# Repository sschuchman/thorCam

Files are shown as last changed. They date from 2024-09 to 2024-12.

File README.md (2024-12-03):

# Thoracic Camera

## Overview
The **Thoracic Camera** project is a collaborative effort to design a dynamic thoracic camera system capable of precision actuation and real-time feedback for use in minimally invasive surgeries. By combining a Raspberry Pi 5 for advanced processing and a Raspberry Pi Pico for motor control and sensor feedback, the system delivers a robust solution for camera tracking and actuation in the chest cavity.

---

## Contributors
- **Sean Schuchman**: January 2024 - December 2024  
- **Jakob Schoeberle**: August 2024 - December 2024  
- **Colton Wall**: August 2024 - December 2024  

---

## Hardware

### Raspberry Pi 5
- **Role**: Central processing hub for the system.  
- **Responsibilities**:
  - Handles video feed from the Pi Camera Module V3.
  - Performs computer vision tasks to detect and track a target object.
  - Sends actuation commands to the Pico Controller via UART.

### Pico Controller (Raspberry Pi Pico)
- **Role**: Camera actuation controller.  
- **Responsibilities**:
  - Interprets movement commands from the Raspberry Pi 5 and drives stepper motors.
  - Monitors sensor feedback from tension modules to ensure proper wire tension.
  - Handles precise actuation of the thoracic camera in response to commands.

---

## Pico Controller
The **Pico Controller** acts as an abstraction layer between the computer vision system on the Raspberry Pi 5 and the physical camera actuation system. It simplifies control by encapsulating motor and tension management, providing an easy-to-interface control system.  

### Features:
- **Camera Actuation**:  
  Controls stepper motors to manipulate tension wires, enabling the camera to move along the x-plane and y-plane directions.  
- **Tension Monitoring**:  
  Uses sensor feedback from load cells to dynamically adjust wires and maintain system balance.  
- **Control Modes**:  
  - **Manual Mode**: Direct input to move the camera.  
  - **Automatic Mode**: Actuation based on computer vision commands from the Raspberry Pi 5.  

---

## Directory Structure
The project is divided into several directories to organize hardware, software, and firmware resources.

- `/Software`: Contains software running on the Raspberry Pi 5, including computer vision and the Flask web application for control.  
- `/Firmware`: Firmware for the Raspberry Pi Pico to manage motor control and tension monitoring.  
- `/Hardware`: Schematic diagrams, PCB designs, and other hardware resources.  
- `/Datasheets`: Documentation for components such as stepper motors, motor drivers, and sensors.  
- `/3D_Models`: 3D printable designs for physical components.  
- `/legacy`: Archive of previous iterations or deprecated designs.

---

## Setup

### Raspberry Pi Pico Setup
1. **Development Environment**:
   - Use Visual Studio Code with the Raspberry Pi Pico extension to build and flash the firmware.
   - Ensure the Raspberry Pi Pico Debug Probe is connected for flashing and debugging.  

2. **Firmware Installation**:
   - Clone the repository and navigate to the `/Firmware` directory.
   - Open the project in Visual Studio Code and use the Pico extension to compile and flash the firmware.  

3. **Hardware Connections**:
   - Connect stepper motors via L293D drivers to the GPIO pins.
   - Connect ADS1115 ADC modules to GPIO4 (SDA) and GPIO5 (SCL).
   - Ensure UART pins (GPIO0 and GPIO1) are connected to the Raspberry Pi 5 for communication.

### Raspberry Pi 5 Setup
1. **Install Required Software**:
   - Ensure Python is installed with the required libraries (`Flask`, `OpenCV`, etc.).
   - Navigate to the `/Software` directory and install dependencies using:
     ```bash
     pip install -r requirements.txt
     ```

2. **Start the Web Application**:
   - Run the `app.py` script to start the Flask web server:
     ```bash
     python app.py
     ```
   - Access the control interface via a web browser on the local network.

3. **Hardware Connections**:
   - Connect the Pi Camera Module V3 to the CSI port.
   - Ensure UART is configured on `/dev/ttyAMA0` for communication with the Pico Controller.

---

## Usage
1. **Manual Control**:
   - Use the web interface to manually send movement commands to the Pico Controller.
   - Adjust camera settings and monitor sensor feedback through the interface.

2. **Automatic Control**:
   - Enable automatic mode via the web interface to allow the system to track a selected object.
   - The Raspberry Pi 5 processes the video feed to calculate the offset and sends movement commands to the Pico Controller.

3. **Real-Time Feedback**:
   - Monitor sensor values and system logs in the web interface.
   - View live video and mask feeds to verify object tracking.

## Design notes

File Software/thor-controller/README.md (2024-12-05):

# Thor Controller Software

## Overview
The **Thor Controller Software** is a dual-component system designed to control and monitor the thoracic camera for minimally invasive surgery. The software runs on two devices:
1. **Raspberry Pi Pico**: Handles movement commands and sensor data.
2. **Raspberry Pi 5**: Serves as the control hub, hosting a web-based user interface and managing computer vision processing and UART communication with the Pico.

This system provides a seamless interface for real-time camera movement, video visualization, and automatic tracking of surgical tools.

---

## Features
### Raspberry Pi 5
- **Web Application**:
  - Built with Flask, serving as the main user interface.
  - Displays:
    - High-resolution live camera feed from the Pi Camera V3 Wide.
    - Mask feed showing object tracking and offset visualization.
    - Real-time sensor data in a bar chart.
    - Live UART log output from the Raspberry Pi Pico.
  - Supports toggling between **manual** and **automatic** control modes.
  - Interactive sliders to adjust brightness, tracking thresholds, and color detection parameters.
- **Computer Vision**:
  - Uses OpenCV to detect and track objects based on color.
  - Computes positional offsets `(dx, dy)` of the target relative to the center of the screen.
  - In automatic mode, calculates and sends movement commands to the Raspberry Pi Pico for continuous adjustments.
- **UART Communication**:
  - Sends movement commands (`Move[x, y]`) to the Raspberry Pi Pico.
  - Receives live sensor data and logs from the Pico for display.

### Raspberry Pi Pico
- Processes UART commands received from the Raspberry Pi 5.
- Adjusts camera position based on movement commands.
- Reads and processes tension sensor data using ADC inputs.
- Manages motor control via L293D motor drivers.

---

## Installation

### Prerequisites
#### Raspberry Pi 5
1. Ensure your Raspberry Pi 5 is running Raspberry Pi OS with Python 3 installed.
2. Enable the camera interface:
   ```bash
   sudo raspi-config
   ```
   Navigate to **Interface Options > Camera** and enable it.

3. Install required system dependencies:
   ```bash
   sudo apt update
   sudo apt install -y python3-opencv python3-picamera2 python3-numpy python3-flask python3-serial
   ```

4. Install additional required libraries:
   ```bash
   sudo apt install -y libcamera-apps libcamera-dev
   ```

5. Ensure the user has the appropriate permissions to use the camera:
   ```bash
   sudo usermod -a -G video $USER
   ```

6. Reboot the Raspberry Pi to apply changes:
   ```bash
   sudo reboot
   ```

#### Raspberry Pi Pico
1. Flash the custom firmware onto the Pico using the Pico SDK or any C development environment.
2. Ensure the Pico is connected to the Raspberry Pi 5 via UART for communication.

---

## Usage

### Raspberry Pi 5
1. Clone this repository to your Raspberry Pi 5:
   ```bash
   git clone <repository_url>
   cd <repository_directory>
   ```

2. Start the Flask server:
   ```bash
   python3 app.py
   ```

3. Open a web browser and navigate to:
   ```bash
   http://<Raspberry-Pi-IP>:5000
   ```
   Replace `<Raspberry-Pi-IP>` with your Raspberry Pi's IP address.

---

## Troubleshooting

### ModuleNotFoundError: No module named 'libcamera'
- Ensure `libcamera` is installed using:
  ```bash
  sudo apt install -y libcamera-apps libcamera-dev
  ```
- Verify the camera interface is enabled:
  ```bash
  sudo raspi-config
  ```
  Navigate to **Interface Options > Camera** and enable it.

### Permission Errors with Camera
- Add the user to the `video` group:
  ```bash
  sudo usermod -a -G video $USER
  ```
- Reboot the Raspberry Pi:
  ```bash
  sudo reboot
  ```

### Dependencies Not Installed
If you encounter dependency installation errors, ensure that you run:
```bash
sudo apt update
sudo apt install -y python3-opencv python3-picamera2 python3-numpy python3-flask python3-serial
```

---

## Notes
- For smoother operation, ensure the Raspberry Pi is connected to a stable network.
- Regularly check for updates to the dependencies using `sudo apt update && sudo apt upgrade`.

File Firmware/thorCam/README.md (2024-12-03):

# Thor Controller Firmware

## Overview
The **Thor Controller Firmware** is designed to run on the Raspberry Pi Pico, facilitating movement control and sensor monitoring for the thoracic camera system. The firmware communicates with the Raspberry Pi 5 over UART, processing movement commands and controlling stepper motors while continuously monitoring sensor data.

The firmware leverages a modular structure, with functionalities like motor control, sensor monitoring, and UART communication implemented in dedicated source and header files.

---

## Features
- **UART Communication**:
  - Receives movement commands (`Move[x, y]`) from the Raspberry Pi 5.
  - Sends real-time sensor data (`Load[0, 0, 0, 0]`) back to the Raspberry Pi 5.
- **Sensor Monitoring**:
  - Reads tension sensor values using ADS1115 ADCs connected over I2C.
  - Monitors sensor thresholds to maintain balance and ensure safe motor operation.
- **Motor Control**:
  - Controls four stepper motors via L293D motor drivers.
  - Supports precise movement in response to parsed UART commands.
- **Multicore Processing**:
  - Core 0 handles UART communication and movement control.
  - Core 1 continuously reads sensor values for real-time feedback.

---

## Installation

### Prerequisites
- **Development Environment**:
  - Install Visual Studio Code with the Raspberry Pi Pico extension.
  - Configure the extension to build and run Pico projects.
- **Debugging Tools**:
  - Use the Raspberry Pi Pico Debug Probe to flash firmware and debug.
- **Hardware Setup**:
  - Connect:
    - ADS1115 ADC modules to the I2C pins (SDA: GPIO4, SCL: GPIO5).
    - Stepper motors to L293D drivers and appropriate GPIO pins.
    - UART (GPIO0, GPIO1) for communication with the Raspberry Pi 5.

### Build and Flash
1. Clone the repository and open the `thorCam` folder in Visual Studio Code.
2. Build the firmware using the Pico extension's build tools.
3. Flash the firmware to the Raspberry Pi Pico using the Pico Debug Probe.

---

## Key Functionalities

### 1. **Main File**
- `main.c`: Initializes all components and starts the main execution loop.
  - Sets up UART, I2C, and GPIO configurations.
  - Spawns tasks for:
    - Reading sensors on Core 1.
    - Handling UART commands and movement control on Core 0.

### 2. **Functional Highlights**
- **Motor Control**:
  - `l293d.c` and `l293d.h` provide functions to initialize and control stepper motors.
  - Implements precise stepping logic for both forward and backward movement.
- **Sensor Monitoring**:
  - Interfaces with ADS1115 modules to read differential sensor values.
  - Calibrates sensors and monitors tension thresholds.
- **Movement**:
  - Maps movement commands to motor actions.
  - Ensures balanced tension during movement by coordinating multiple motors.
- **UART Communication**:
  - Parses incoming UART commands such as `Move[x, y]`.
  - Sends sensor data logs back to the Raspberry Pi 5.
- **ADC Handling**:
  - Provides an interface for configuring and reading from ADS1115 ADC modules.
  - Supports differential and single-ended readings.

---

## Usage
1. Flash the firmware to the Raspberry Pi Pico using the Debug Probe.
2. Connect the hardware as specified in the prerequisites.
3. Use the Flask web interface running on the Raspberry Pi 5 to send movement commands and monitor sensor feedback.

---

## Troubleshooting
- **No UART Communication**:
  - Verify the correct UART pins (GPIO0, GPIO1) are connected to the Raspberry Pi 5.
  - Check the baud rate matches between the devices (default: `115200`).
- **Motor Stalling or Overrun**:
  - Ensure motor driver connections are secure.
  - Verify tension limits in the sensor monitoring code and adjust as necessary.
- **Incorrect Sensor Readings**:
  - Confirm I2C connections (SDA: GPIO4, SCL: GPIO5).
  - Calibrate the ADS1115 modules using the `ads1115_calibrate()` function.

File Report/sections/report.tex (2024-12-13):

\section{Background}
Thoracic surgeries often face challenges of limited visibility due to the narrow space between the ribs. Traditional surgical methods frequently involve partial rib removal to provide surgeons with adequate access and visibility. This invasive approach leads to longer recovery times and increased post-surgery complications.

The \textbf{Thoracic Camera Project} aims to address these issues by introducing a highly maneuverable thoracic camera system capable of precise actuation and real-time feedback. This system is designed to operate within the chest cavity, providing continuous, clear visualization without the need for rib removal. By combining manual and automatic control, our solution enhances surgical precision, reduces the need for assistants, and promotes minimally invasive procedures.

\section{Technical Descriptions}

\subsection{System Overview}
\subsubsection{Block Diagram}

\paragraph{Level 0}
The Level 0 block diagram, shown in Figure~\ref{fig:level0}, outlines the four primary components of the thoracic camera system: the Camera, Video Processing, Tension Control, and the User Interface. The core functionality of the system revolves around the camera, which is mounted on an actuating platform. This slim and maneuverable camera is inserted into the chest cavity during surgery, providing a live video feed.

\begin{figure}[H]
    \centering
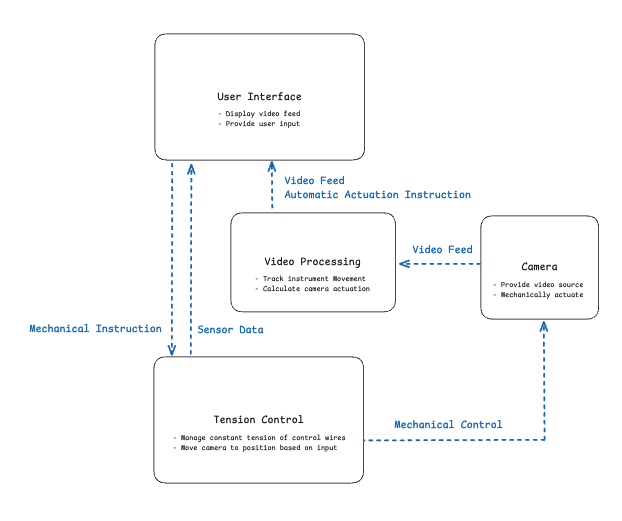
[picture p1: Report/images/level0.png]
    
    \caption{Level 0 Block Diagram of the Thoracic Camera System}
    \label{fig:level0}
\end{figure}

The video feed is processed in the Video Processing module, where frames are analyzed to detect surgical tools and calculate the necessary movements to center the object within the frame. These calculated movement commands are forwarded to the Tension Control system, which adjusts the tension in the wires to precisely move and stabilize the camera as needed.

The User Interface (UI) provides surgeons with full control over the system, offering options for both automatic and manual operation modes. Through the UI, users can view the live video feed, monitor system diagnostics, and adjust settings such as brightness or control modes. This integration ensures seamless interaction between the surgeon, the visualization system, and the tension control mechanisms.

\paragraph{Level 1}  
As shown in Figure~\ref{fig:level1}, the Level 1 block diagram details the operational units and their interconnections, emphasizing key components such as the \textbf{Raspberry Pi 5}, \textbf{Pi Pico}, \textbf{ADC Modules}, \textbf{Load Cells}, \textbf{Pi Camera V3 Wide}, \textbf{Stepper Motors}, and \textbf{Stepper Drivers}.

\begin{figure}[H]
    \centering
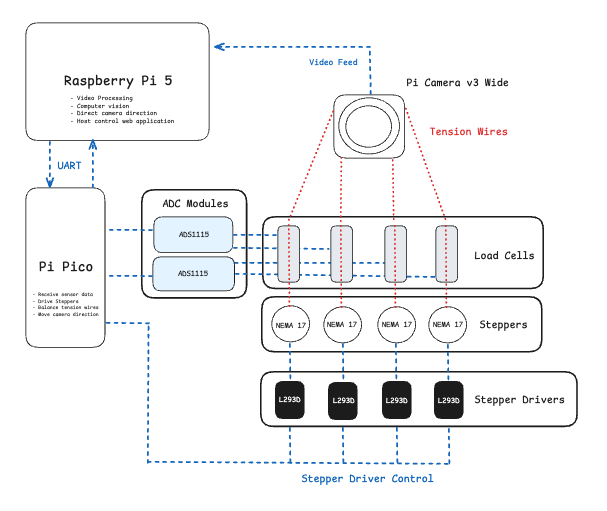
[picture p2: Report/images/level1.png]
    
    \caption{Level 1 Block Diagram of the Thoracic Camera System}
    \label{fig:level1}
\end{figure}

\begin{itemize}
    \item \textbf{Pi Camera V3 Wide:} The camera captures high-quality images with a broad field of view, suitable for minimally invasive surgical environments. Its compact design ensures it can navigate tight spaces while providing clear visualization of the surgical field.

    \item \textbf{Raspberry Pi 5:} Serving as the central processing unit, the Raspberry Pi 5 handles computer vision tasks, detecting and tracking objects in the camera feed. It calculates movement adjustments to keep targets aligned at the frame center and hosts the web-based User Interface for real-time video streaming, diagnostics, and control options.

    \item \textbf{Pi Pico:} The Raspberry Pi Pico manages mechanical actuation by controlling four \textbf{Stepper Motors} via \textbf{L293D Stepper Drivers}. It adjusts the tension in four wires attached to the camera mount to ensure smooth movement. The Pico also processes sensor data from the \textbf{ADC Modules} and dynamically balances wire tension to stabilize the camera.

    \item \textbf{ADC Modules:} Two ADS1115 ADC modules interface with the system's \textbf{Load Cells}, reading tension data to ensure precise control. These modules enable continuous monitoring of wire tension and provide feedback for real-time adjustments.

    \item \textbf{Load Cells:} Four load cells measure the tension in each wire, providing critical data to the Raspberry Pi Pico. This feedback allows the system to dynamically adjust wire tension and maintain stability during movement.

    \item \textbf{Stepper Motors:} Four NEMA 17 stepper motors provide the mechanical actuation required to adjust wire tension and position the camera. These motors are controlled by the Raspberry Pi Pico through the \textbf{Stepper Drivers}.

    \item \textbf{Stepper Drivers:} Four L293D drivers serve as the interface between the Raspberry Pi Pico and the stepper motors, enabling precise control over the camera's position and orientation through wire tension adjustments.
\end{itemize}

The integration of these components ensures smooth, responsive, and precise camera movements. The \textbf{Raspberry Pi 5} and \textbf{Pi Pico} communicate via a UART connection, allowing for continuous feedback and command transmission. This seamless interaction between hardware and software provides surgeons with a reliable, intuitive visualization tool for thoracic surgeries, adaptable for both manual and automatic modes.

\subsection{Physical Design}
\subsubsection{Tension Control Module}
The tension control module is responsible for accurately adjusting the position and orientation of the thoracic camera by controlling the tension in four wires connected to the camera. Each module is equipped with a NEMA 17 stepper motor, located at the bottom of the unit, which drives a spool to regulate the tension in the wire. This setup allows for precise control of the camera's movement, crucial for the dynamic visualization required in thoracic surgeries.

For tension monitoring, each module uses a 1kg load cell, which is centrally positioned in the module to measure the exact force applied to the wire. The load cell’s accuracy is key to ensuring balanced tension across all four wires, preventing any misalignment or jerking motions that could interfere with the camera’s positioning. The chosen load cell has an accuracy of ±0.01kg, providing a resolution fine enough to detect even the smallest changes in wire tension. This ensures the camera’s movements are smooth and responsive, which is critical during delicate surgical procedures. 

In terms of physical size, the tension control module, as shown in the attached schematic, is compact yet robust. The overall dimensions are approximately 12.7mm wide by 80mm tall, with a depth of 12.7mm. The wire feeds out from the top of the module through a guiding tube, ensuring that the wire moves smoothly as tension is adjusted. This small form factor makes the system suitable for tight surgical environments, where space is a premium, while still providing the necessary functionality to support the thoracic camera.

\includepdf[pages=-]{docs/Tension_Module_v3.pdf}

\subsection{Tension Module Rack}
The tension module rack is designed to hold and align the four tension control modules, ensuring they function precisely and consistently during operation. Each module is mounted within the rack, and the rack's dimensions and construction are carefully optimized for stability and ease of assembly. 

The overall length of the rack is 260mm, with a height of 74mm and a depth of 88mm. The modules are spaced 64mm apart, with a set screw positioned at the back of each module, securing them firmly in place. This design prevents any unwanted movement or vibrations, ensuring that the tensioning system remains stable, even under varying loads. The precision alignment of the modules is essential to achieving consistent wire tension and smooth actuation of the thoracic camera. 

Additionally, the rack allows for easy access to each module's stepper motor and load cell for maintenance or adjustment. The rack's design is modular, meaning it can accommodate different configurations or upgrades if needed. This flexibility is critical in surgical environments, where equipment must be adaptable and reliable. 

\includepdf[pages=-]{docs/Module_Rack.pdf}

\subsubsection{Camera Module}
\begin{itemize}
    \item Mounted on a gimbal plate actuated by four tension wires for precise directional control.
    \item Includes optimized internal tunnels to reduce friction and enhance movement responsiveness.
    \item Dimensions: 40mm wide, 60mm long, and slightly taller than 15.75mm.
\end{itemize}

The camera module consists of two key components: the platform and the gimbal plate. The platform secures the tension wires, each routed through dedicated tubes and locked into place using set screws. These tubes ensure that the tension wires remain aligned as they apply force to the gimbal plate for movement control. The set screws provide a firm grip on the wires, preventing any slippage, which is critical for maintaining precise camera movement. 

Mounted on a central pedestal, the gimbal plate holds the camera and allows for precise directional control in response to tension adjustments. The tension wires are connected at each corner of the gimbal plate, creating a balanced system that ensures smooth and accurate movement in all directions. 

An iteration of this design introduces an optimized internal tunnel within the base of the camera mount. This adjustment reduces the number of sharp turns that the tension wires must navigate, lowering friction and minimizing wire wear. The smoother path improves force transmission from the stepper motors to the gimbal plate, allowing for more responsive and precise camera movement. However, this optimization has slightly increased the overall height of the design compared to previous versions. This trade-off, favoring smoother action over a slightly taller profile, was necessary to enhance the efficiency and dexterity of the camera movement. 

Despite this change, the overall design remains compact, with the camera module measuring 40mm wide, 60mm long, and now slightly taller than the previous 15.75mm height. This small form factor is still ideal for thoracic surgery, minimizing the amount of hardware within the chest cavity and preventing obstruction of the surgeon’s view. 

Additionally, the camera system eliminates the need for external motors or bulky components inside the surgical area, keeping the setup streamlined. The gimbal plate’s actuation is entirely driven by the tension in the wires, which is managed by stepper motors and load cells located outside of the chest cavity, ensuring smooth, precise, and responsive control during the surgery. 

\includepdf[pages=-]{docs/Camera_Module_v3.pdf}

\subsection{Hardware Design}

\subsubsection{Custom PCB Design}
The custom PCB for the thoracic camera system is a crucial component that integrates and organizes all hardware modules for efficient operation.

\begin{figure}[H]
    \centering
    
    \caption{Board View of the PCB}
    \label{fig:BoardView}
\end{figure}

It is designed to accommodate the following features and functionalities:

\begin{itemize}
    \item \textbf{Mounting and Routing:} The PCB includes dedicated mounting holes and routing paths for the \textbf{Raspberry Pi Pico}, \textbf{ADS1115 ADC modules}, and \textbf{L293D Stepper Drivers}. These components are strategically placed to ensure minimal signal interference and efficient power distribution.

    \item \textbf{Debugging Headers:} Debugging headers are provided to facilitate development and troubleshooting. These headers allow seamless access to key signals and communication lines during firmware development and testing.

    \item \textbf{Screw Block Terminals:} Screw block terminals are integrated into the PCB to provide secure connections for external components, including the stepper motors and load cells. These terminals ensure robust mechanical and electrical connections, minimizing the risk of disconnections during operation.

    \item \textbf{24-Pin PC Power Supply Headers:} Female headers are included for compatibility with a standard 24-pin PC power supply. This allows the system to leverage the reliable and high-current output of a PC power supply to drive the motors and other components.

    \item \textbf{Integrated Power Switch:} A power switch is built into the PCB for convenient system control. The switch allows the user to safely power the system on and off without the need to disconnect cables or power supplies.

    \item \textbf{IC Sockets:} IC sockets are used for the stepper drivers and other replaceable components, enabling easy swapping or upgrading without soldering. This feature enhances the maintainability and extendibility of the PCB.

    \item \textbf{Compact and Modular Design:} The PCB design is compact and modular, with clear silkscreen labeling for all connections and components. This ensures that assembly and maintenance can be performed efficiently, even in a high-pressure operating environment.

    \item \textbf{Grounding and Power Distribution:} Proper grounding techniques and wide power traces are used to handle high current demands while minimizing electrical noise. This ensures stable operation of the stepper motors and ADC modules.
\end{itemize}

The PCB not only consolidates the hardware into a single compact unit but also enhances the system's reliability and maintainability. With clearly labeled connections and a well-organized layout, it ensures that all hardware modules can interact seamlessly, supporting the precise and dynamic operation required by the thoracic camera system.

\subsubsection{Raspberry Pi 5}
The Raspberry Pi 5 acts as the central processing unit for the thoracic camera system. It serves several key roles:
\begin{itemize}
    \item \textbf{Computer Vision:} Hosts the OpenCV-based video processing application, which detects and tracks objects within the camera's video feed and calculates movement commands.
    \item \textbf{Web Application:} Runs a Flask-based web application that provides a graphical user interface for live video streaming, manual and automatic control modes, brightness and color range adjustments, and system diagnostics.
    \item \textbf{Communication:} Sends movement commands to the Raspberry Pi Pico and receives sensor data over a UART connection to enable dynamic feedback.
    \item \textbf{Efficient Processing:} Leverages the high-performance quad-core processor to ensure real-time video processing and low-latency system control.
\end{itemize}

\subsubsection{Pi Camera V3 Wide}
The Pi Camera V3 – Wide Angle captures the video feed for the system. Its key attributes include:
\begin{itemize}
    \item \textbf{Wide Field of View:} Provides an extensive view of the surgical field, minimizing blind spots.
    \item \textbf{High Resolution:} Delivers clear, detailed images for precise object detection and tracking.
    \item \textbf{Compact Form Factor:} Enables insertion into tight surgical spaces without obstruction.
\end{itemize}

\subsubsection{Raspberry Pi Pico}
The Raspberry Pi Pico functions as the dedicated hardware controller for the system, responsible for:
\begin{itemize}
    \item \textbf{Motor Control:} Drives four stepper motors using custom-written firmware and L293D stepper motor drivers to adjust the tension in the wires connected to the camera.
    \item \textbf{Sensor Integration:} Reads analog data from ADS1115 ADC modules connected to load cells, providing real-time tension monitoring.
    \item \textbf{Dynamic Adjustment:} Implements a feedback loop to ensure balanced wire tension during camera movements, maintaining stability and precision.
    \item \textbf{Multicore Processing:} Utilizes the dual-core architecture to manage motor control and sensor data independently, ensuring smooth and efficient operation.
\end{itemize}

\begin{figure}[H]
    \centering
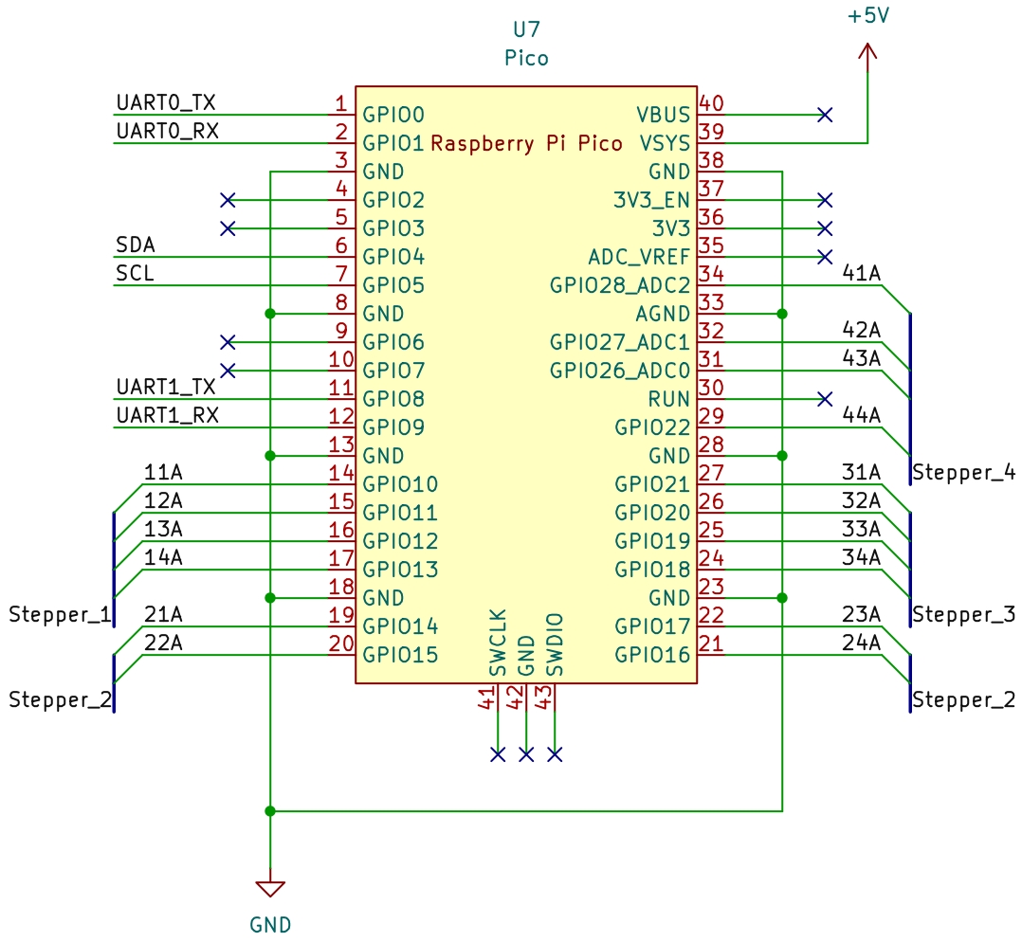
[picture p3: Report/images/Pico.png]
    
    \caption{Raspberry Pi Pico Schematic}
    \label{fig:Pico}
\end{figure}

\subsubsection{L293D Stepper Drivers}
The L293D motor drivers are used to control the NEMA 17 stepper motors. Key features include:
\begin{itemize}
    \item Dual H-bridge configuration for driving bipolar stepper motors.
    \item Control signals provided by the Raspberry Pi Pico to execute precise stepper motor movements.
    \item Compact design integrated onto the custom PCB for easy installation and replacement.
\end{itemize}

\subsubsection{NEMA 17 Stepper Motors}
The system employs four NEMA 17 stepper motors to actuate the tension wires. These motors offer:
\begin{itemize}
    \item \textbf{High Precision:} Capable of microstepping for smooth and accurate movements.
    \item \textbf{Compact Size:} Suitable for integration into the compact tension control module design.
    \item \textbf{Reliable Operation:} Provides consistent performance under variable loads.
\end{itemize}

\begin{figure}[H]
    \centering
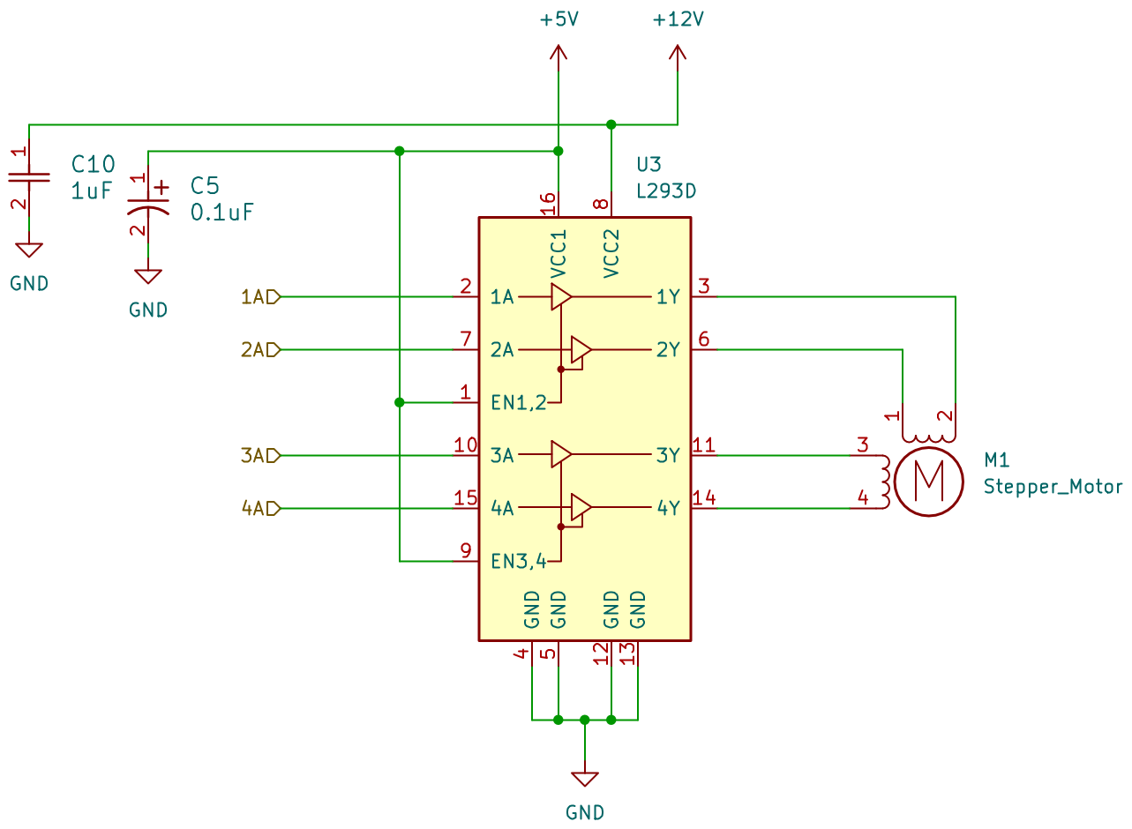
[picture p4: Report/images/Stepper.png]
    
    \caption{NEMA 17 Stepper Driver Schematic}
    \label{fig:Stepper}
\end{figure}

\subsubsection{ADS1115 ADC Modules}
The ADS1115 ADC modules interface with the load cells to provide high-precision tension data. Features include:
\begin{itemize}
    \item \textbf{Differential Measurements:} Capable of measuring the voltage difference across the load cell's Wheatstone bridge.
    \item \textbf{I2C Communication:} Reduces the number of GPIO pins required for integration with the Raspberry Pi Pico.
    \item \textbf{High Resolution:} Provides 16-bit analog-to-digital conversion for accurate tension readings.
\end{itemize}

\subsubsection{Load Cells}
The load cells provide critical feedback on the tension applied to the wires. Features include:
\begin{itemize}
    \item \textbf{1kg Load Capacity:} Ensures accurate tension monitoring within the system's operational range.
    \item \textbf{High Precision:} Connected to ADS1115 ADC modules to measure minute changes in tension.
    \item \textbf{Robust Design:} Mounted securely on the custom PCB to minimize noise and maintain stability.
\end{itemize}

\begin{figure}[H]
    \centering
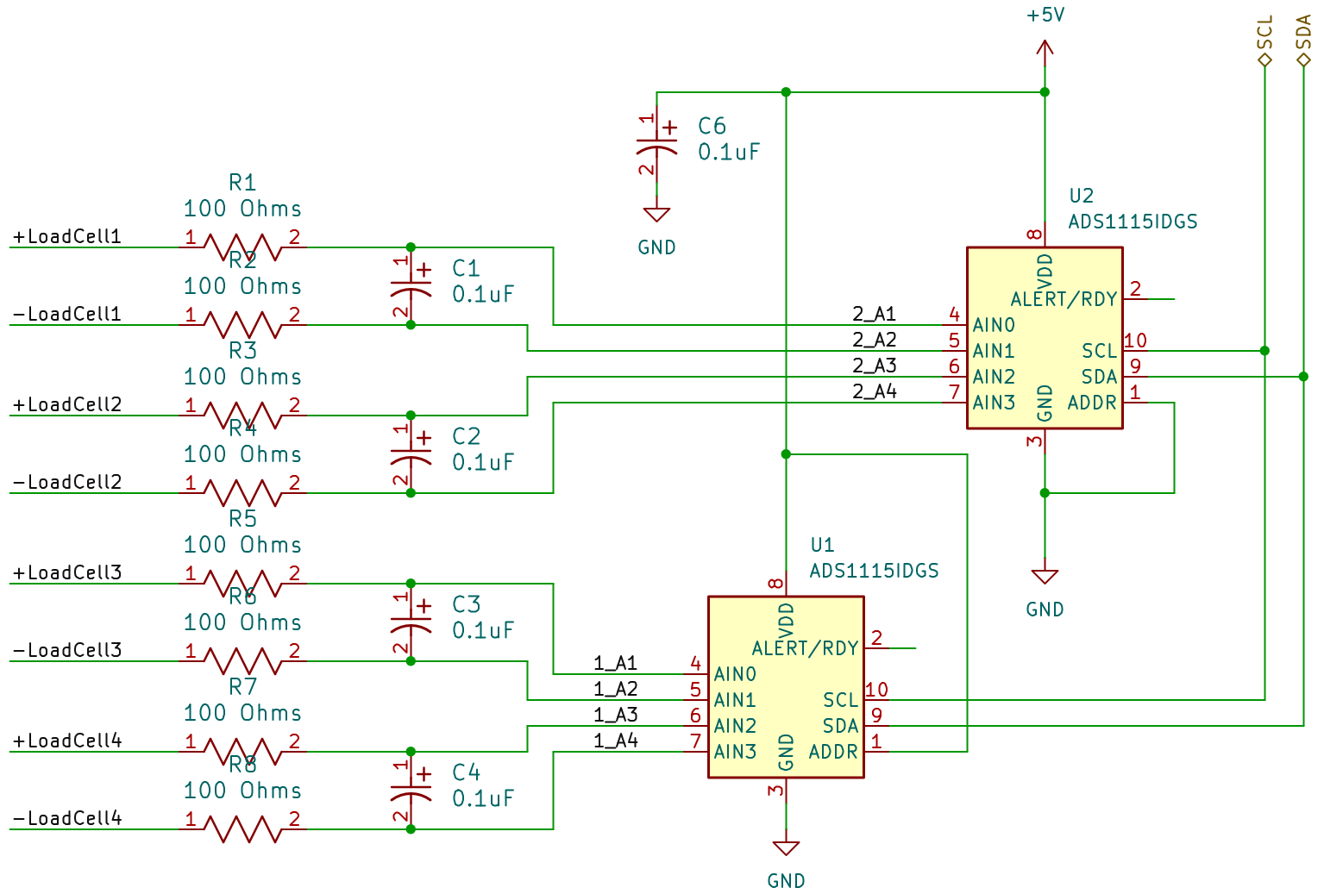
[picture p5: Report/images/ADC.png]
    
    \caption{Loadcell ADC Schematic}
    \label{fig:ADC}
\end{figure}

This hardware design, with its carefully selected components and custom PCB, ensures the system operates reliably and efficiently under the demands of thoracic surgery. Each module is integrated seamlessly to provide surgeons with precise control and a clear visualization of the surgical field.

\newpage
\subsection{Firmware and Software Design}

The firmware and software design work in unison to deliver a seamless and efficient control system for the thoracic camera. Both the firmware running on the Raspberry Pi Pico and the software hosted on the Raspberry Pi 5 are tailored to achieve precise camera control, real-time feedback, and user interaction. The integration of these two components enables the system to provide reliable performance under the demands of surgical applications. The high-level architecture of this integration is illustrated in Figure~\ref{fig:software_flowchart}.

\begin{figure}[H]
    \centering
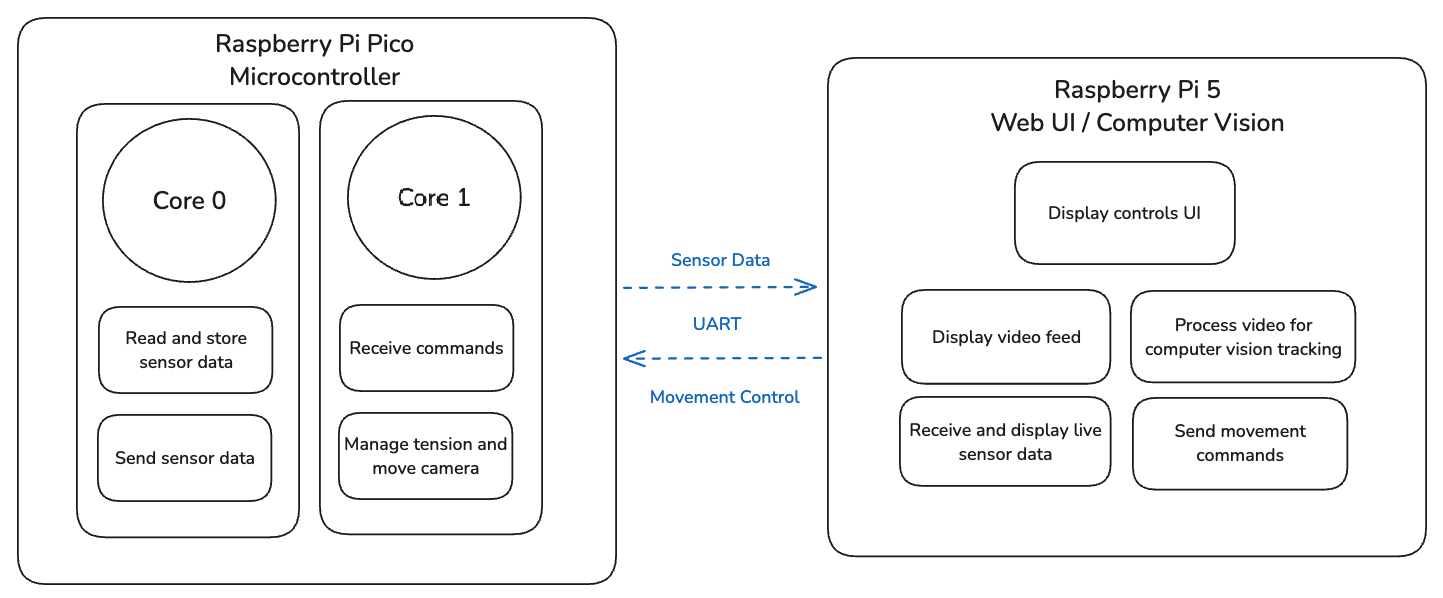
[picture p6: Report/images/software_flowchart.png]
    
    \caption{Firmware and Software Flowchart}
    \label{fig:software_flowchart}
\end{figure}

\subsubsection{Firmware Design}
The firmware for the thoracic camera system was meticulously crafted to provide precise control of the stepper motors and accurate monitoring of load cell data, enabling real-time actuation of the camera module. Written in C, the firmware leverages the full capabilities of the Raspberry Pi Pico, including its dual-core processor, to optimize performance and responsiveness. Custom drivers were developed from scratch for critical components such as the L293D motor drivers, ADS1115 analog-to-digital converters (ADCs), and UART communication, ensuring full control and flexibility over the hardware.

Core 0 of the Raspberry Pi Pico is dedicated to high-priority tasks such as receiving commands from the Raspberry Pi 5 via UART and executing motor control routines. The UART communication interface continuously listens for movement commands in the form of Move[x, y], where x and y dictate the directional control of the camera. These commands are parsed and validated before the motors are activated. The movement routines adjust wire tension by stepping the corresponding motors either forward or backward based on load cell feedback, ensuring precise and balanced actuation. The motor drivers use custom microstepping sequences implemented in the firmware to provide smooth and accurate movements.

Core 1 is responsible for monitoring the load cell data by interfacing with two ADS1115 ADC modules configured in differential mode. Each ADC monitors two load cells, allowing the system to measure the tension in all four wires simultaneously. The ADS1115 driver was custom-built to initialize the ADCs, perform calibration, and retrieve differential voltage readings at a high sampling rate. These readings are processed and stored in a shared data structure, protected by mutexes to prevent race conditions. This modular design ensures that load cell data is continuously updated without interrupting the real-time responsiveness of motor control operations on Core 0.

The firmware's calibration routine ensures the system is correctly aligned before operation. During calibration, each stepper motor unwinds the tension wires to a safe baseline, while the ADS1115 modules measure and offset any discrepancies in the load cell readings. Once the baseline tension is set, the motors are activated to bring the wires to their optimal tension range, guaranteeing smooth and precise movements during operation.

The firmware also incorporates safeguards and intelligent error handling. For example, the motor control routines actively monitor the tension limits using load cell data to prevent over-tightening or slack in the wires. If the tension exceeds the predefined upper or lower thresholds, the firmware stops the motors and adjusts as necessary to maintain balance.

By utilizing the Pico's dual-core architecture, the firmware efficiently separates computational tasks, ensuring that motor control and load cell monitoring run concurrently and without interference. This design enables seamless coordination between the hardware components and the software system, allowing for precise real-time adjustments required during minimally invasive thoracic surgeries. The custom-built drivers and modular firmware structure provide a reliable and extensible foundation for future enhancements and adaptability to additional hardware components.

For further details and to reference the implementation, please visit the GitHub repository at \url{https://github.com/sschuchman/thorCam}. Specifically, navigate to the \texttt{/Firmware/thorCam} directory for access to the software codebase.

\subsubsection{Software Design}
The software design of the thoracic camera system integrates multiple components to provide real-time control and visualization. At the core of the system, an OpenCV-based program running on the Raspberry Pi 5 handles object detection. This program processes the live video feed to identify objects based on their color and calculates their offset from the center of the frame. Using this information, movement commands are generated and sent to the Raspberry Pi Pico via a Flask-based server. The Pico receives these commands over UART and drives the stepper motors to adjust the camera's position, enabling real-time, smooth actuation. In automatic mode, the camera continuously tracks the object and adjusts its position to keep the object centered in the frame without requiring user input.

The user interface, implemented as a web application using Flask, provides seamless interaction between the operator and the system. It supports both manual and automatic control modes. In manual mode, users can operate the camera using on-screen directional buttons or keyboard keys, while in automatic mode, the system autonomously tracks the object and adjusts the camera position accordingly. The interface also features a live video feed for real-time visualization, a mask feed that highlights the detected object with bounding boxes and offset lines, and a dynamic bar chart displaying tension data from the load cell sensors. Additional interface features include sliders for adjusting brightness and HSV color thresholds, as well as toggle switches for selecting control modes and activating a demo mode.

To ensure optimal system performance, the software processes the video feed at 1920x1080 resolution, overlaying critical information such as bounding boxes, offsets (\textit{dx} and \textit{dy}), and object distances. A separate thread continuously monitors the UART connection to receive and log tension data from the load cells, which is displayed in the web application in real time. The mask feed uses HSV-based filtering and contour analysis to visualize the object detection process, aiding in debugging and parameter optimization.

The software is designed to provide a flexible and responsive user experience, allowing the operator to configure system parameters dynamically. Users can fine-tune brightness and color thresholds through the web interface to adapt to changing lighting conditions. The demo mode automates pre-defined movement patterns for testing and demonstration purposes. These capabilities, combined with seamless integration between the Raspberry Pi 5 and Pico, ensure precise and efficient control of the thoracic camera system.

For further details and to reference the implementation, please visit the GitHub repository at \url{https://github.com/sschuchman/thorCam}. Specifically, navigate to the \texttt{/Software/thor-controller} directory for access to the software codebase.

\subsection{System Performance}
The thoracic camera system delivers real-time responsiveness and precision through the integration of efficient firmware and software, tailored for minimally invasive surgical applications.

On the firmware side, the Raspberry Pi Pico leverages its dual-core architecture to handle sensor data acquisition and motor control independently. Core 1 manages load cell readings from two ADS1115 ADCs in differential mode, updating all four tension values approximately every 10 milliseconds. Core 0 handles stepper motor control and UART communication, with motor movements executed in 10–15 microseconds per microstep. Typical movement commands, involving both sensor feedback and tension adjustments, are processed within 50–100 milliseconds, ensuring smooth, dynamic actuation.

The software on the Raspberry Pi 5 integrates video processing, user interface, and communication with the firmware. OpenCV-based object tracking processes frames at 30 FPS (33 ms per frame), calculating offsets and sending movement commands with a transmission latency of less than 20 milliseconds. The Flask web interface refreshes live video and mask feeds at 30 FPS, while tension sensor data is updated every 100 milliseconds, providing a responsive and intuitive user experience.

Together, the system achieves near-instantaneous feedback and control with key performance benchmarks: sensor updates at 100 Hz, stepper command execution in under 100 milliseconds, and real-time UI updates. These metrics ensure the system's reliability, making it ideal for delicate surgical procedures requiring precision and minimal latency.

\begin{itemize}
    \item \textbf{Sensor Update Rate:} 100 Hz (every 10 ms)
    \item \textbf{Stepper Command Execution:} $~$50–100 ms
    \item \textbf{Video Feed and Mask Refresh Rate:} 15 FPS (software limited to 30 FPS)
    \item \textbf{Sensor Data Display Refresh Rate:} 10 Hz (every 100 ms)
    \item \textbf{Transmission Latency:} $<$20 ms
\end{itemize}

\newpage
\section{Final Schedule}

\begin{tabular}{|l|l|l|}
    \hline
    \textbf{Task} & \textbf{Responsible Party} & \textbf{Completion Date} \\ \hline
    Physical Design Prototyping & Sean Schuchman & August 2024 \\ \hline
    Initial Firmware and Electrical Design & Sean Schuchman, Colton Wall & September 2024 \\ \hline
    Circuit Breadboarding and Iteration & All Contributors & October 2024 \\ \hline
    Firmware and PCB Design & Sean Schuchman, Jakob Schoeberle & November 2024 \\ \hline
    Final Assembly, UI Development, and Tuning & All Contributors & December 2024 \\ \hline
\end{tabular}

\vspace{0.5cm}

The final schedule, shown above, highlights five distinct stages of development. 

The first stage focused on physical prototyping, which was completed by the end of August 2024. This early completion allowed us to shift our focus to the second stage, which involved initial iterations of firmware and electrical design. During September 2024, we developed and tested the basic firmware and initial electrical circuits to validate the project's core functionality.

The third stage involved breadboard prototyping with the Raspberry Pi Pico, stepper drivers, and ADC modules. During this phase, we explored several iterations of the circuit design, testing different parts and strategies to optimize the system. By the end of October 2024, we finalized the circuit design and began prototyping basic firmware to support our selected components.

In the fourth stage, after committing to the finalized circuit design and chosen components, we focused heavily on PCB design to ensure it could be ordered in time. Concurrently, the software and firmware were further developed, with significant progress made by early November 2024.

By late November, the PCB was completed, and all physical and electrical components were assembled and fully integrated. The final stage involved polishing the system, refining the software controller UI, and tuning the machine for optimal performance. During the last week, we focused on preparing our presentation and ensuring the system met all expectations for functionality and reliability.

\section{Distribution of Effort}
\begin{tabular}{|l|l|}
    \hline
    Contributor & Area of Contribution \\ \hline
    Sean Schuchman & 3D Modeling, Manufacturing, Software/Firmware Design, Prototyping \\ \hline
    Jakob Schoeberle & Circuit Design, PCB Design, PCB Assembly \\ \hline
    Colton Wall & Circuit Design, Research, Hardware Assembly, System Integration \\ \hline
\end{tabular}

\section{Possible Future Work}
The thoracic camera system has demonstrated its potential as a reliable surgical visualization tool, but several areas of improvement can be pursued to enhance its functionality, usability, and application scope:

\begin{itemize}
    \item \textbf{Miniaturization and Physical Redesign:} Scale down the size of the camera probe and tension control module to make the system less intrusive and more versatile for broader surgical applications. A redesigned camera platform can improve maneuverability in confined spaces.

    \item \textbf{Integrated Lighting and Compact PCB:} Develop a custom PCB with integrated LED lighting for the camera, minimizing the system's footprint and reducing the need for additional external components.

    \item \textbf{PID Control for Camera Movement:} Replace the heuristic-based movement algorithm with a PID (Proportional-Integral-Derivative) control system. This would provide more precise, stable, and responsive control over camera movements.

    \item \textbf{Alternative Control Options:} Explore wireless control systems to eliminate the need for physical cabling in the operating room or integrate foot pedal controls to give surgeons hands-free operation.

    \item \textbf{Medical-Grade Material Design:} Transition to medical-grade materials for the camera probe, tension wires, and platform to ensure biocompatibility, sterilizability, and compliance with healthcare regulations.

    \item \textbf{AI-Based Object Tracking:} Implement AI-based object detection and tracking algorithms to improve the accuracy, robustness, and response time of the system's automatic mode.

    \item \textbf{System Robustness and Durability:} Enhance the durability of tension wires, load-bearing components, and the gimbal plate to withstand repeated use in clinical environments without performance degradation.

    \item \textbf{Clinical Trials and Validation:} Conduct extensive testing in simulated and real surgical environments to validate the system's reliability, safety, and usability in various medical procedures.
\end{itemize}

These advancements would not only improve the overall functionality and performance of the system but also increase its adaptability for diverse surgical applications, bringing it closer to practical deployment in clinical settings.

\section{Conclusion}

The \textbf{Thoracic Camera Project} represents a well-executed and practical approach to improving visibility and precision in thoracic surgeries. By integrating hardware and software components effectively, the system provides a minimally invasive alternative to traditional methods, which often involve rib removal and extended recovery times. The project successfully demonstrated precise, real-time actuation using tension-controlled wires and object tracking, offering surgeons a clear and stable view of the surgical field.

Each phase of the project contributed to its success, from physical prototyping and electrical design to firmware development and software integration. The prototype leverages the Raspberry Pi 5 for video processing, the Raspberry Pi Pico for tension control, custom PCBs for efficient hardware organization, and a user-friendly interface for seamless operation. The modular and well-documented design lays a solid foundation for future iterations and improvements.

While the project met its core objectives, challenges such as miniaturization and clinical validation remain. Future work could focus on refining the system's size for broader surgical applications, incorporating AI-based tracking for enhanced precision, and ensuring the use of medical-grade materials for compliance and durability. These refinements would help align the system with real-world surgical needs.

Overall, the Thoracic Camera Project achieved its goals and demonstrated the feasibility of an integrated system for minimally invasive surgeries. With further development and testing, the design has the potential to serve as a reliable and effective tool, contributing to incremental improvements in surgical techniques and outcomes.

\vspace{0.5cm}
\noindent
\textbf{\normalsize For a demonstration of the system, watch the} \href{https://youtu.be/UekYdXSXzXo}{\textbf{\normalsize demo video}}.
\vspace{0.5cm}

\subsection{References}
\begin{itemize}
    \item Raspberry Pi Documentation: \url{https://datasheets.raspberrypi.com/rpi5/raspberry-pi-5-product-brief.pdf}
    \item Raspberry Pi Pico Documentation: \url{https://datasheets.raspberrypi.com/pico/pico-datasheet.pdf}
    \item Raspberry Pi Pico C/C++ SDK: \url{https://www.raspberrypi.com/documentation/microcontrollers/c_sdk.html}
    \item OpenCV Python Documentation: \url{https://opencv.org}
    \item NEMA 17 Datasheet: \url{https://pages.pbclinear.com/rs/909-BFY-775/images/Data-Sheet-Stepper-Motor-Support.pdf}
    \item L293D Motor Driver Datasheet: \url{https://www.ti.com/product/L293D}
    \item ADS1115 ADC Datasheet: \url{https://www.ti.com/lit/ds/symlink/ads1115.pdf}
\end{itemize}

\section{Bill of Materials}

\begin{tabular}{|l|l|c|c|c|c|}
    \hline
    \textbf{Name} & \textbf{Description} & \textbf{Quantity} & \textbf{Price (USD)} & \textbf{Cost (USD)} & \textbf{Link} \\ \hline
    Raspberry Pi 5 & 8GB & 1 & 79.99 & 79.99 & \href{https://www.microcenter.com/product/673711/raspberry-pi-5-8gb-lpddr4x}{Link} \\ \hline
    Pi Pico & Non-wireless & 1 & 3.99 & 3.99 & \href{https://www.microcenter.com/product/661033/raspberry-pi-pico-microcontroller-development-board}{Link} \\ \hline
    L293D & Stepper Motor Driver (10 pcs) & 1 & 8.99 & 3.60 & \href{https://www.amazon.com/gp/product/B09NBQYVLL/ref=ppx_yo_dt_b_asin_title_o00_s00}{Link} \\ \hline
    M3 Screw Set & Metric Screws with Nuts & 1 & 8.99 & 1.18 & \href{https://www.amazon.com/dp/B0BMQFHD8H?ref_=yo_ov_dt_b_fed_asin_title}{Link} \\ \hline
    Ball Bearing & 3mm Bore & 1 & 8.29 & 4.97 & \href{https://www.amazon.com/dp/B07WF18HQY?ref_=ppx_yo2ov_dt_b_fed_asin_title}{Link} \\ \hline
    Threaded Inserts & M3 brass threaded insert & 1 & 6.99 & 2.10 & \href{https://www.amazon.com/dp/B0CCX33LHD?ref_=ppx_yo2ov_dt_b_fed_asin_title}{Link} \\ \hline
    Mount Bracket & Nema 17 mounting bracket (4 pcs) & 1 & 14.99 & 14.99 & \href{https://www.amazon.com/dp/B07JW6X9ZR?ref_=ppx_yo2ov_dt_b_fed_asin_title}{Link} \\ \hline
    Load Cell & 1kg load cell (4 pcs) & 1 & 15.49 & 15.49 & \href{https://www.amazon.com/dp/B09YTQKQ9G/ref=ppx_yo_dt_b_search_asin_title}{Link} \\ \hline
    Pi Camera & Pi Camera V3 – Wide & 1 & 34.99 & 34.99 & \href{https://www.microcenter.com/product/662018/raspberry-pi-camera-3-wide}{Link} \\ \hline
    Camera Cable & Standard $\rightarrow$ Mini Pi camera cable & 1 & 1.99 & 1.99 & \href{https://www.microcenter.com/product/671933/raspberry-pi-5-camera-cable-300mm}{Link} \\ \hline
    Printed Circuit Board & Custom Designed PCB & 5 & 60.92 & 60.92 & \href{https://jlcpcb.com/}{Link} \\ \hline
    PCB Components & Electrical Components & n/a & 22.75 & 22.75 & \href{https://www.digikey.com/}{Link}\\ \hline
    \textbf{Total} &  &  & \textbf{268.37} & \textbf{247.96} &  \\ \hline
\end{tabular}

\section{Acknowledgements}
We extend our gratitude to:
\begin{itemize}
    \item \textbf{Dr. Amardeep Kaur} for her guidance and mentorship throughout the project.
    \item \textbf{Dr. Timothy York} for technical specifications and project requirements.
    \item \textbf{Craig Watson} for technical guidance and perspective throughout the project.
    \item \textbf{SIUE (Southern Illinois University Edwardsville) URCA (Undergraduate Research and Creative Activities)} for allowing us to adopt the Thoracic Camera Project as a senior design project.
    \item \textbf{SIUE ECE (Electrical and Computer Engineering) Department} for providing the resources and lab space.
\end{itemize}

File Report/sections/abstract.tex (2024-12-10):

\section{Abstract}
Minimally invasive thoracic surgeries often face challenges of limited visibility and access, traditionally addressed through invasive procedures such as rib removal, which increase recovery time and postoperative complications. This project introduces a dynamic thoracic camera system designed to enhance surgical precision and reduce invasiveness by providing real-time feedback and precise actuation. The system integrates a Raspberry Pi 5 for image processing and computer vision to track surgical tools and a Raspberry Pi Pico for motor control and sensor feedback to actuate a slim, maneuverable camera mounted on a tension-controlled platform. Stepper motors adjust tension wires monitored by load cells, ensuring balanced operation and smooth camera movement. A web-based interface allows surgeons to operate the system in manual or automatic modes, providing intuitive controls and live system monitoring. By eliminating rib removal and enabling precise control, this system improves the efficiency and safety of thoracic surgeries. This report details the project’s design, implementation, and performance, alongside challenges encountered, team contributions, and opportunities for future enhancements such as 3D visualization and advanced robotic integration.

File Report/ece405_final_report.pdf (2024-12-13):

# Final Report

# ECE 405 - Senior Design II

Sean Schuchman, Jakob Schoeberle, Colton Wall

December 12, 2024

## 1 Abstract

Minimally invasive thoracic surgeries often face challenges of limited visibility and access, traditionally addressed through invasive procedures such as rib removal, which increase recovery time and postoperative complications. This project introduces a dynamic thoracic camera system designed to enhance surgical precision and reduce invasiveness by providing real-time feedback and precise actuation. The system integrates a Raspberry Pi 5 for image processing and computer vision to track surgical tools and a Raspberry Pi Pico for motor control and sensor feedback to actuate a slim, maneuverable camera mounted on a tension-controlled platform. Stepper motors adjust tension wires monitored by load cells, ensuring balanced operation and smooth camera movement. A web-based interface allows surgeons to operate the system in manual or automatic modes, providing intuitive controls and live system monitoring. By eliminating rib removal and enabling precise control, this system improves the efficiency and safety of thoracic surgeries. This report details the project’s design, implementation, and performance, alongside challenges encountered, team contributions, and opportunities for future enhancements such as 3D visualization and advanced robotic integration.

## Contents

1 Abstract | 1
2 Background | 3
3 Technical Descriptions | 3

1

Final Report | Sean Schuchman, Jakob Schoeberle, Colton Wall
4 Final Schedule | 19
5 Distribution of Effort | 19
6 Possible Future Work | 19
7 Conclusion | 20
8 Bill of Materials | 21
9 Acknowledgements | 21

## 2 Background

Thoracic surgeries often face challenges of limited visibility due to the narrow space between the ribs. Traditional surgical methods frequently involve partial rib removal to provide surgeons with adequate access and visibility. This invasive approach leads to longer recovery times and increased post-surgery complications.
The Thoracic Camera Project aims to address these issues by introducing a highly maneuverable thoracic camera system capable of precise actuation and real-time feedback. This system is designed to operate within the chest cavity, providing continuous, clear visualization without the need for rib removal. By combining manual and automatic control, our solution enhances surgical precision, reduces the need for assistants, and promotes minimally invasive procedures.

## 3 Technical Descriptions

### 3.1 System Overview

### 3.1.1 Block Diagram

Level 0 The Level 0 block diagram, shown in Figure 1, outlines the four primary components of the thoracic camera system: the Camera, Video Processing, Tension Control, and the User Interface. The core functionality of the system revolves around the camera, which is mounted on an actuating platform. This slim and maneuverable camera is inserted into the chest cavity during surgery, providing a live video feed.


Figure 1: Level 0 Block Diagram of the Thoracic Camera System

The video feed is processed in the Video Processing module, where frames are analyzed to detect surgical tools and calculate the necessary movements to center the object within the frame. These calculated movement commands are forwarded to the Tension Control system, which adjusts the tension in the wires to precisely move and stabilize the camera as needed.
The User Interface (UI) provides surgeons with full control over the system, offering options for both automatic and manual operation modes. Through the UI, users can view the live video feed, monitor system diagnostics, and adjust settings such as brightness or control modes. This integration ensures seamless interaction between the surgeon, the visualization system, and the tension control mechanisms.

Level 1 As shown in Figure 2, the Level 1 block diagram details the operational units and their interconnections, emphasizing key components such as the Raspberry Pi 5, Pi Pico, ADC Modules, Load Cells, Pi Camera V3 Wide, Stepper Motors, and Stepper Drivers.


Figure 2: Level 1 Block Diagram of the Thoracic Camera System

- Pi Camera V3 Wide: The camera captures high-quality images with a broad field of view, suitable for minimally invasive surgical environments. Its compact design ensures it can navigate tight spaces while providing clear visualization of the surgical field.
- Raspberry Pi 5: Serving as the central processing unit, the Raspberry Pi 5 handles computer vision tasks, detecting and tracking objects in the camera feed. It calculates movement adjustments to keep targets aligned at the frame center and hosts the web-based User Interface for real-time video streaming, diagnostics, and control options.
- Pi Pico: The Raspberry Pi Pico manages mechanical actuation by controlling four Stepper Motors via L293D Stepper Drivers. It adjusts the tension in four wires attached to the camera mount to ensure smooth movement. The Pico also processes sensor data from the ADC Modules and dynamically balances wire tension to stabilize the camera.
- ADC Modules: Two ADS1115 ADC modules interface with the system’s Load Cells, reading tension data to ensure precise control. These modules enable continuous monitoring of wire tension and provide feedback for real-time adjustments.
- Load Cells: Four load cells measure the tension in each wire, providing critical data to the Raspberry Pi Pico. This feedback allows the system to dynamically adjust wire tension and maintain stability during movement.
- Stepper Motors: Four NEMA 17 stepper motors provide the mechanical actuation required to adjust wire tension and position the camera. These motors are controlled by the Raspberry Pi Pico through the Stepper Drivers.

- Stepper Drivers: Four L293D drivers serve as the interface between the Raspberry Pi Pico and the stepper motors, enabling precise control over the camera’s position and orientation through wire tension adjustments.

The integration of these components ensures smooth, responsive, and precise camera movements. The Raspberry Pi 5 and Pi Pico communicate via a UART connection, allowing for continuous feedback and command transmission. This seamless interaction between hardware and software provides surgeons with a reliable, intuitive visualization tool for thoracic surgeries, adaptable for both manual and automatic modes.

### 3.2 Physical Design

### 3.2.1 Tension Control Module

The tension control module is responsible for accurately adjusting the position and orientation of the thoracic camera by controlling the tension in four wires connected to the camera. Each module is equipped with a NEMA 17 stepper motor, located at the bottom of the unit, which drives a spool to regulate the tension in the wire. This setup allows for precise control of the camera’s movement, crucial for the dynamic visualization required in thoracic surgeries.
For tension monitoring, each module uses a 1kg load cell, which is centrally positioned in the module to measure the exact force applied to the wire. The load cell’s accuracy is key to ensuring balanced tension across all four wires, preventing any misalignment or jerking motions that could interfere with the camera’s positioning. The chosen load cell has an accuracy of ±0.01kg, providing a resolution fine enough to detect even the smallest changes in wire tension. This ensures the camera’s movements are smooth and responsive, which is critical during delicate surgical procedures.
In terms of physical size, the tension control module, as shown in the attached schematic, is compact yet robust. The overall dimensions are approximately 12.7mm wide by 80mm tall, with a depth of 12.7mm. The wire feeds out from the top of the module through a guiding tube, ensuring that the wire moves smoothly as tension is adjusted. This small form factor makes the system suitable for tight surgical environments, where space is a premium, while still providing the necessary functionality to support the thoracic camera.

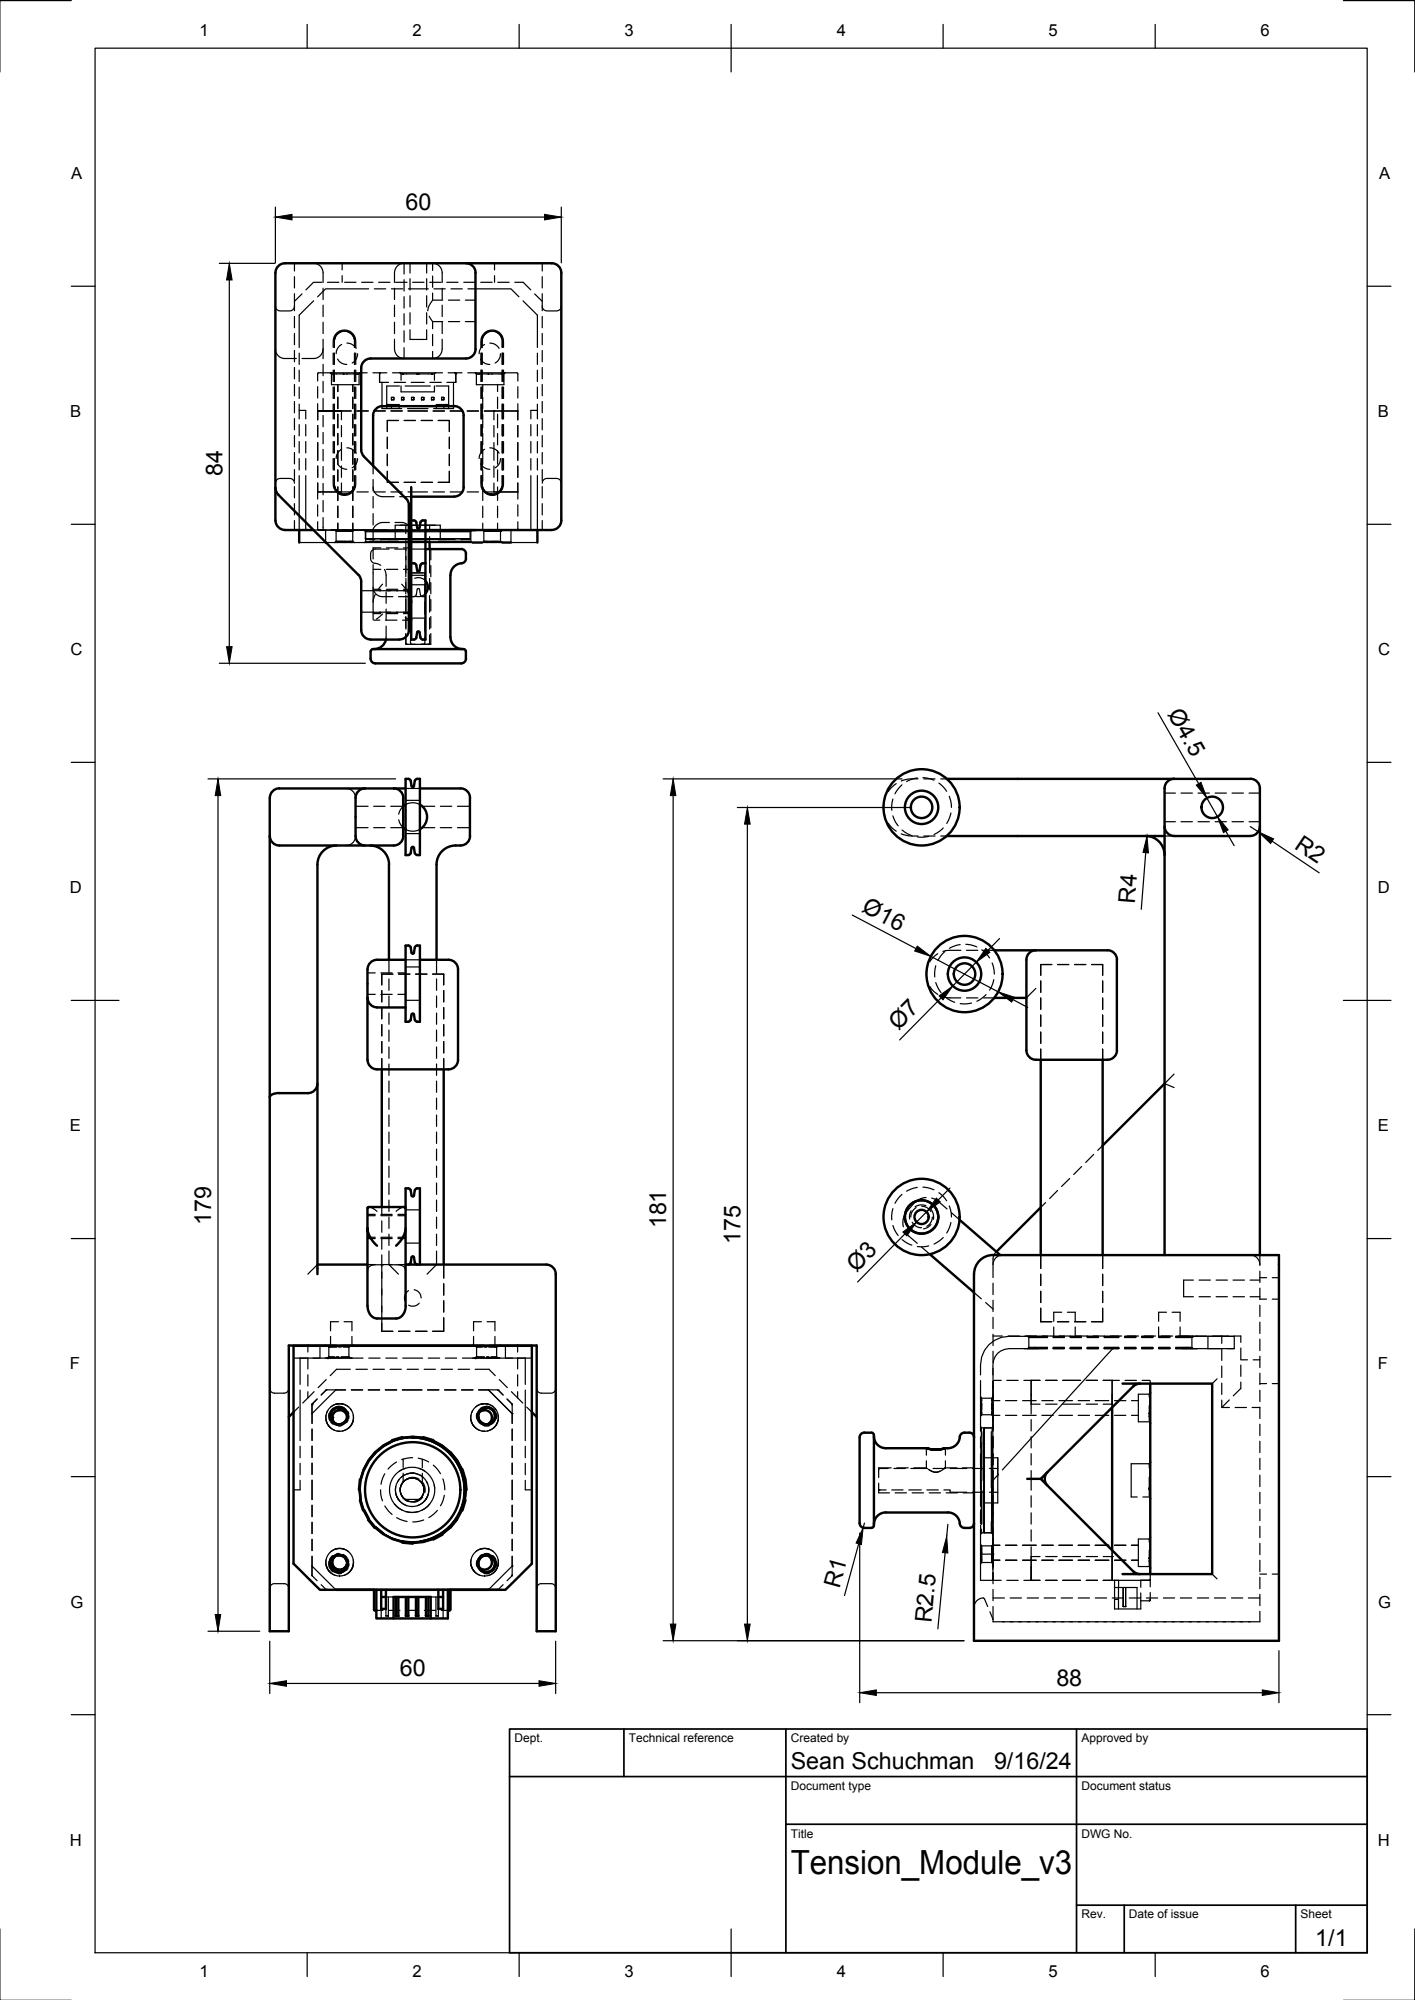
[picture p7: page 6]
Dept.; Technical reference; Created by; Approved by; Sean Schuchman; 60 ¹⁷⁹

Document type | Document status

Title Tension_Module_v3 | DWG No.

Rev. | Date of issue | Sheet 1/1

### 3.3 Tension Module Rack

The tension module rack is designed to hold and align the four tension control modules, ensuring they function precisely and consistently during operation. Each module is mounted within the rack, and the rack’s dimensions and construction are carefully optimized for stability and ease of assembly.
The overall length of the rack is 260mm, with a height of 74mm and a depth of 88mm. The modules are spaced 64mm apart, with a set screw positioned at the back of each module, securing them firmly in place. This design prevents any unwanted movement or vibrations, ensuring that the tensioning system remains stable, even under varying loads. The precision alignment of the modules is essential to achieving consistent wire tension and smooth actuation of the thoracic camera.
Additionally, the rack allows for easy access to each module’s stepper motor and load cell for maintenance or adjustment. The rack’s design is modular, meaning it can accommodate different configurations or upgrades if needed. This flexibility is critical in surgical environments, where equipment must be adaptable and reliable.

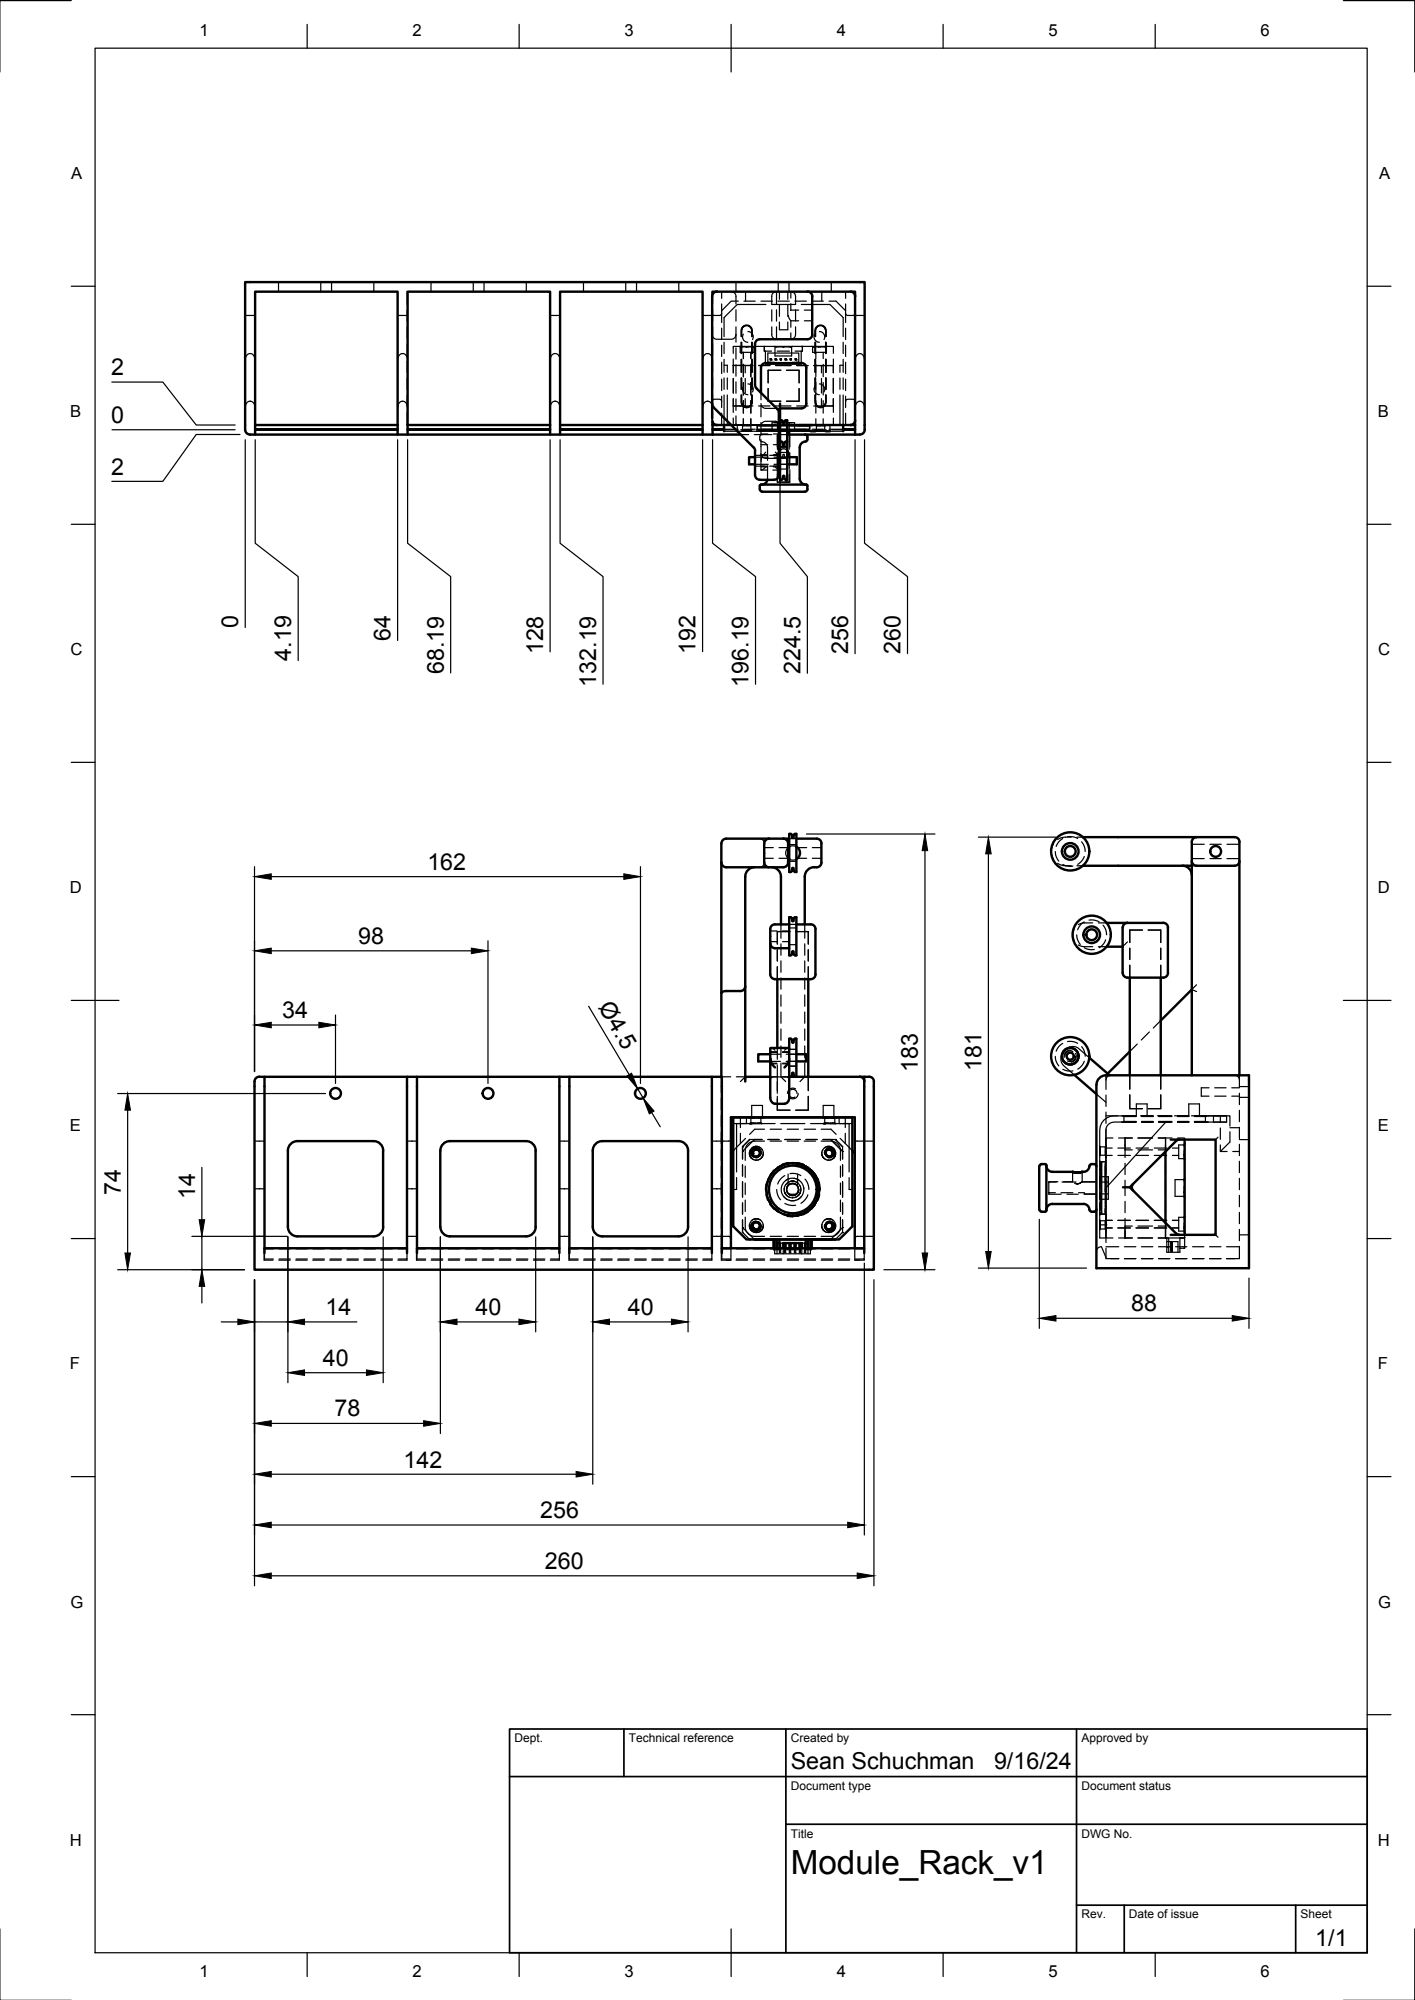
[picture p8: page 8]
Dept.; Technical reference; Created by; Approved by; Document type; Document status; Title; DWG No.; Rev.; Date of issue; Sheet; Module_Rack_v1; Sean Schuchman

### 3.3.1 Camera Module

- Mounted on a gimbal plate actuated by four tension wires for precise directional control.
- Includes optimized internal tunnels to reduce friction and enhance movement responsiveness.
- Dimensions: 40mm wide, 60mm long, and slightly taller than 15.75mm.

The camera module consists of two key components: the platform and the gimbal plate. The platform secures the tension wires, each routed through dedicated tubes and locked into place using set screws. These tubes ensure that the tension wires remain aligned as they apply force to the gimbal plate for movement control. The set screws provide a firm grip on the wires, preventing any slippage, which is critical for maintaining precise camera movement.
Mounted on a central pedestal, the gimbal plate holds the camera and allows for precise directional control in response to tension adjustments. The tension wires are connected at each corner of the gimbal plate, creating a balanced system that ensures smooth and accurate movement in all directions.
An iteration of this design introduces an optimized internal tunnel within the base of the camera mount. This adjustment reduces the number of sharp turns that the tension wires must navigate, lowering friction and minimizing wire wear. The smoother path improves force transmission from the stepper motors to the gimbal plate, allowing for more responsive and precise camera movement. However, this optimization has slightly increased the overall height of the design compared to previous versions. This trade-off, favoring smoother action over a slightly taller profile, was necessary to enhance the efficiency and dexterity of the camera movement.
Despite this change, the overall design remains compact, with the camera module measuring 40mm wide, 60mm long, and now slightly taller than the previous 15.75mm height. This small form factor is still ideal for thoracic surgery, minimizing the amount of hardware within the chest cavity and preventing obstruction of the surgeon’s view.
Additionally, the camera system eliminates the need for external motors or bulky components inside the surgical area, keeping the setup streamlined. The gimbal plate’s actuation is entirely driven by the tension in the wires, which is managed by stepper motors and load cells located outside of the chest cavity, ensuring smooth, precise, and responsive control during the surgery.

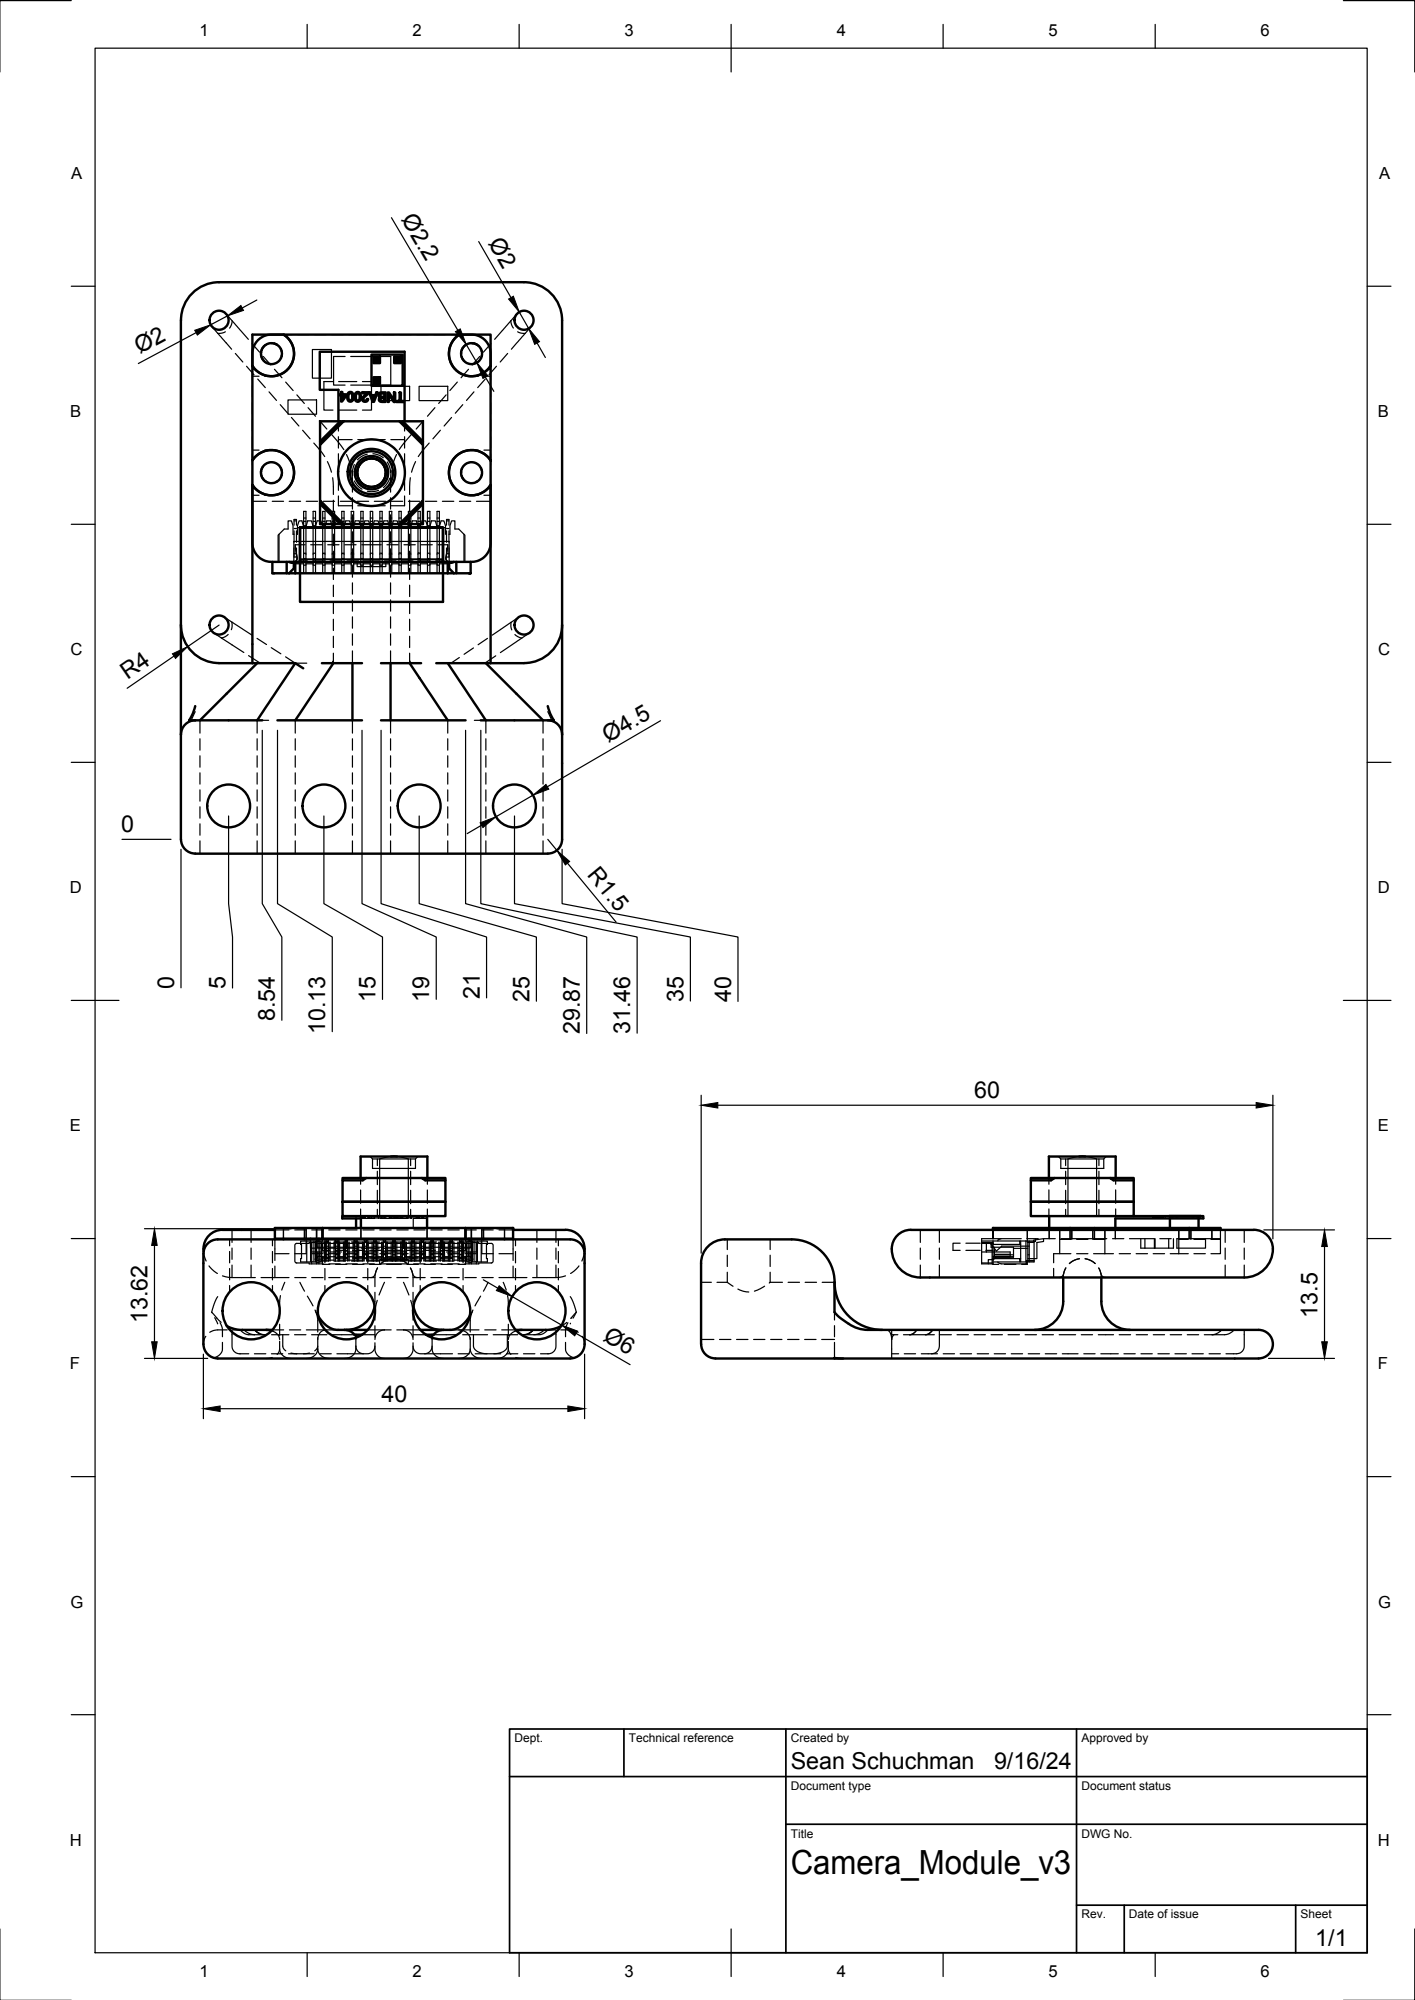
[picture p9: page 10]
Dept.; Technical reference; Created by; Approved by; Sean Schuchman

Document type | Document status

Title Camera_Module_v3 | DWG No.

Rev. | Date of issue | Sheet 1/1

### 3.4 Hardware Design

### 3.4.1 Custom PCB Design

The custom PCB for the thoracic camera system is a crucial component that integrates and organizes all hardware modules for efficient operation.

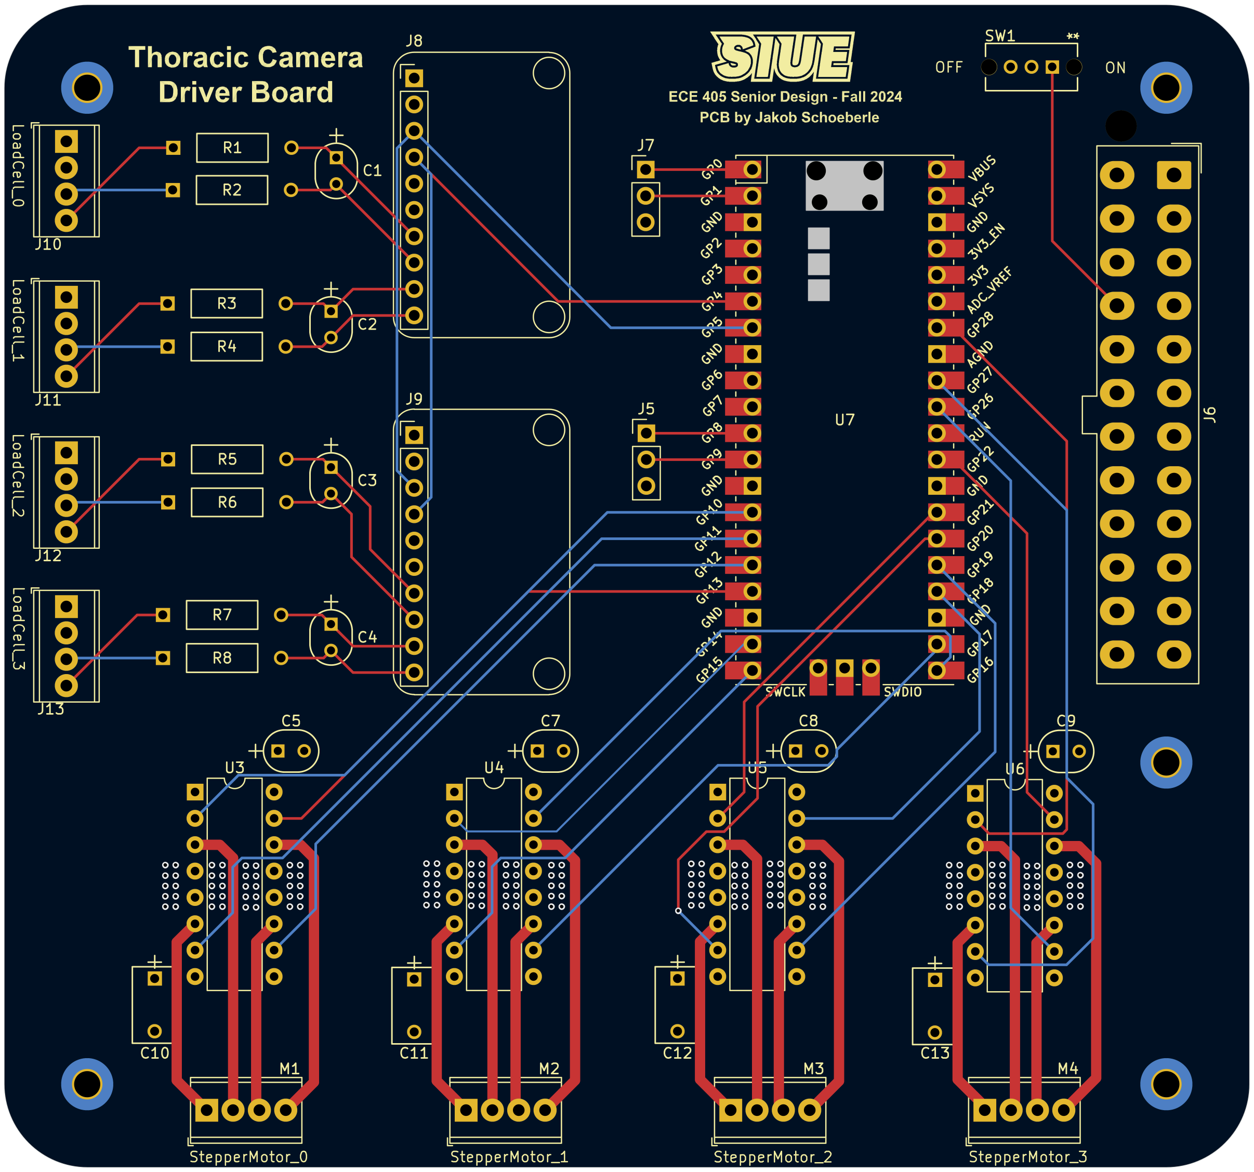
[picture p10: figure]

Figure 3: Board View of the PCB

It is designed to accommodate the following features and functionalities:

- Mounting and Routing: The PCB includes dedicated mounting holes and routing paths for the Raspberry Pi Pico, ADS1115 ADC modules, and L293D Stepper Drivers. These components are strategically placed to ensure minimal signal interference and efficient power distribution.
- Debugging Headers: Debugging headers are provided to facilitate development and troubleshooting. These headers allow seamless access to key signals and communication lines during firmware development and testing.
- Screw Block Terminals: Screw block terminals are integrated into the PCB to provide secure connections for external components, including the stepper motors and load cells. These terminals ensure robust mechanical and electrical connections, minimizing the risk of disconnections during operation.
- 24-Pin PC Power Supply Headers: Female headers are included for compatibility with a standard 24-pin PC power supply. This allows the system to leverage the reliable and high-current output of a PC power supply to drive the motors and other components.
- Integrated Power Switch: A power switch is built into the PCB for convenient system control. The switch allows the user to safely power the system on and off without the need to disconnect cables or power supplies.

- IC Sockets: IC sockets are used for the stepper drivers and other replaceable components, enabling easy swapping or upgrading without soldering. This feature enhances the maintainability and extendibility of the PCB.
- Compact and Modular Design: The PCB design is compact and modular, with clear silkscreen labeling for all connections and components. This ensures that assembly and maintenance can be performed efficiently, even in a high-pressure operating environment.
- Grounding and Power Distribution: Proper grounding techniques and wide power traces are used to handle high current demands while minimizing electrical noise. This ensures stable operation of the stepper motors and ADC modules.

The PCB not only consolidates the hardware into a single compact unit but also enhances the system’s reliability and maintainability. With clearly labeled connections and a well-organized layout, it ensures that all hardware modules can interact seamlessly, supporting the precise and dynamic operation required by the thoracic camera system.

### 3.4.2 Raspberry Pi 5

The Raspberry Pi 5 acts as the central processing unit for the thoracic camera system. It serves several key roles:

- Computer Vision: Hosts the OpenCV-based video processing application, which detects and tracks objects within the camera’s video feed and calculates movement commands.
- Web Application: Runs a Flask-based web application that provides a graphical user interface for live video streaming, manual and automatic control modes, brightness and color range adjustments, and system diagnostics.
- Communication: Sends movement commands to the Raspberry Pi Pico and receives sensor data over a UART connection to enable dynamic feedback.
- Efficient Processing: Leverages the high-performance quad-core processor to ensure real-time video processing and low-latency system control.

### 3.4.3 Pi Camera V3 Wide

The Pi Camera V3 – Wide Angle captures the video feed for the system. Its key attributes include:

- Wide Field of View: Provides an extensive view of the surgical field, minimizing blind spots.
- High Resolution: Delivers clear, detailed images for precise object detection and tracking.
- Compact Form Factor: Enables insertion into tight surgical spaces without obstruction.

### 3.4.4 Raspberry Pi Pico

The Raspberry Pi Pico functions as the dedicated hardware controller for the system, responsible for:

- Motor Control: Drives four stepper motors using custom-written firmware and L293D stepper motor drivers to adjust the tension in the wires connected to the camera.
- Sensor Integration: Reads analog data from ADS1115 ADC modules connected to load cells, providing real-time tension monitoring.
- Dynamic Adjustment: Implements a feedback loop to ensure balanced wire tension during camera movements, maintaining stability and precision.
- Multicore Processing: Utilizes the dual-core architecture to manage motor control and sensor data independently, ensuring smooth and efficient operation.


Figure 4: Raspberry Pi Pico Schematic

### 3.4.5 L293D Stepper Drivers

The L293D motor drivers are used to control the NEMA 17 stepper motors. Key features include:

- Dual H-bridge configuration for driving bipolar stepper motors.
- Control signals provided by the Raspberry Pi Pico to execute precise stepper motor movements.
- Compact design integrated onto the custom PCB for easy installation and replacement.

### 3.4.6 NEMA 17 Stepper Motors

The system employs four NEMA 17 stepper motors to actuate the tension wires. These motors offer:

- High Precision: Capable of microstepping for smooth and accurate movements.
- Compact Size: Suitable for integration into the compact tension control module design.
- Reliable Operation: Provides consistent performance under variable loads.


Figure 5: NEMA 17 Stepper Driver Schematic

### 3.4.7 ADS1115 ADC Modules

The ADS1115 ADC modules interface with the load cells to provide high-precision tension data. Features include:

- Differential Measurements: Capable of measuring the voltage difference across the load cell’s Wheatstone bridge.
- I2C Communication: Reduces the number of GPIO pins required for integration with the Raspberry Pi Pico.
- High Resolution: Provides 16-bit analog-to-digital conversion for accurate tension readings.

### 3.4.8 Load Cells

The load cells provide critical feedback on the tension applied to the wires. Features include:

- 1kg Load Capacity: Ensures accurate tension monitoring within the system’s operational range.
- High Precision: Connected to ADS1115 ADC modules to measure minute changes in tension.
- Robust Design: Mounted securely on the custom PCB to minimize noise and maintain stability.


Figure 6: Loadcell ADC Schematic

This hardware design, with its carefully selected components and custom PCB, ensures the system operates reliably and efficiently under the demands of thoracic surgery. Each module is integrated seamlessly to provide surgeons with precise control and a clear visualization of the surgical field.

### 3.5 Firmware and Software Design

The firmware and software design work in unison to deliver a seamless and efficient control system for the thoracic camera. Both the firmware running on the Raspberry Pi Pico and the software hosted on the Raspberry Pi 5 are tailored to achieve precise camera control, real-time feedback, and user interaction. The integration of these two components enables the system to provide reliable performance under the demands of surgical applications. The high-level architecture of this integration is illustrated in Figure 7.


Figure 7: Firmware and Software Flowchart

### 3.5.1 Firmware Design

The firmware for the thoracic camera system was meticulously crafted to provide precise control of the stepper motors and accurate monitoring of load cell data, enabling real-time actuation of the camera module. Written in C, the firmware leverages the full capabilities of the Raspberry Pi Pico, including its dual-core processor, to optimize performance and responsiveness. Custom drivers were developed from scratch for critical components such as the L293D motor drivers, ADS1115 analog-to-digital converters (ADCs), and UART communication, ensuring full control and flexibility over the hardware.
Core 0 of the Raspberry Pi Pico is dedicated to high-priority tasks such as receiving commands from the Raspberry Pi 5 via UART and executing motor control routines. The UART communication interface continuously listens for movement commands in the form of Move[x, y], where x and y dictate the directional control of the camera. These commands are parsed and validated before the motors are activated. The movement routines adjust wire tension by stepping the corresponding motors either forward or backward based on load cell feedback, ensuring precise and balanced actuation. The motor drivers use custom microstepping sequences implemented in the firmware to provide smooth and accurate movements.
Core 1 is responsible for monitoring the load cell data by interfacing with two ADS1115 ADC modules configured in differential mode. Each ADC monitors two load cells, allowing the system to measure the tension in all four wires simultaneously. The ADS1115 driver was custom-built to initialize the ADCs, perform calibration, and retrieve differential voltage readings at a high sampling rate. These readings are processed and stored in a shared data structure, protected by mutexes to prevent race conditions. This modular design ensures that load cell data is continuously updated without interrupting the real-time responsiveness of motor control operations on Core 0.
The firmware’s calibration routine ensures the system is correctly aligned before operation. During calibration, each stepper motor unwinds the tension wires to a safe baseline, while the ADS1115 modules measure and offset any discrepancies in the load cell readings. Once the baseline tension is set, the motors are activated to bring the wires to their optimal tension range, guaranteeing smooth and precise movements during operation.
The firmware also incorporates safeguards and intelligent error handling. For example, the motor control routines actively monitor the tension limits using load cell data to prevent over-tightening or slack in the wires. If the tension exceeds the predefined upper or lower thresholds, the firmware stops the motors and adjusts as necessary to maintain balance.
By utilizing the Pico’s dual-core architecture, the firmware efficiently separates computational tasks, ensuring that motor control and load cell monitoring run concurrently and without interference. This design enables seamless coordination between the hardware components and the software system, allowing for precise real-time adjustments required during minimally invasive thoracic surgeries. The custom-built drivers and modular firmware structure provide a reliable and extensible foundation for future enhancements and adaptability to additional hardware components.
For further details and to reference the implementation, please visit the GitHub repository at https: //github.com/sschuchman/thorCam. Specifically, navigate to the /Firmware/thorCam directory for access to the software codebase.

### 3.5.2 Software Design

The software design of the thoracic camera system integrates multiple components to provide real-time control and visualization. At the core of the system, an OpenCV-based program running on the Raspberry Pi 5 handles object detection. This program processes the live video feed to identify objects based on their color and calculates their offset from the center of the frame. Using this information, movement commands are generated and sent to the Raspberry Pi Pico via a Flask-based server. The Pico receives these commands over UART and drives the stepper motors to adjust the camera’s position, enabling real-time, smooth actuation. In automatic mode, the camera continuously tracks the object and adjusts its position to keep the object centered in the frame without requiring user input.
The user interface, implemented as a web application using Flask, provides seamless interaction between the operator and the system. It supports both manual and automatic control modes. In manual mode, users can operate the camera using on-screen directional buttons or keyboard keys, while in automatic mode, the system autonomously tracks the object and adjusts the camera position accordingly. The interface also features a live video feed for real-time visualization, a mask feed that highlights the detected object with bounding boxes and offset lines, and a dynamic bar chart displaying tension data from the load cell sensors. Additional interface features include sliders for adjusting brightness and HSV color thresholds, as well as toggle switches for selecting control modes and activating a demo mode. To ensure optimal system performance, the software processes the video feed at 1920x1080 resolution, overlaying critical information such as bounding boxes, offsets (dx and dy), and object distances. A separate thread continuously monitors the UART connection to receive and log tension data from the load cells, which is displayed in the web application in real time. The mask feed uses HSV-based filtering and contour analysis to visualize the object detection process, aiding in debugging and parameter optimization.
The software is designed to provide a flexible and responsive user experience, allowing the operator to configure system parameters dynamically. Users can fine-tune brightness and color thresholds through the web interface to adapt to changing lighting conditions. The demo mode automates pre-defined movement patterns for testing and demonstration purposes. These capabilities, combined with seamless integration between the Raspberry Pi 5 and Pico, ensure precise and efficient control of the thoracic camera system.
For further details and to reference the implementation, please visit the GitHub repository at https: //github.com/sschuchman/thorCam. Specifically, navigate to the /Software/thor-controller directory for access to the software codebase.

### 3.6 System Performance

The thoracic camera system delivers real-time responsiveness and precision through the integration of efficient firmware and software, tailored for minimally invasive surgical applications.
On the firmware side, the Raspberry Pi Pico leverages its dual-core architecture to handle sensor data acquisition and motor control independently. Core 1 manages load cell readings from two ADS1115 ADCs in differential mode, updating all four tension values approximately every 10 milliseconds. Core 0 handles stepper motor control and UART communication, with motor movements executed in 10–15 microseconds per microstep. Typical movement commands, involving both sensor feedback and tension adjustments, are processed within 50–100 milliseconds, ensuring smooth, dynamic actuation.
The software on the Raspberry Pi 5 integrates video processing, user interface, and communication with the firmware. OpenCV-based object tracking processes frames at 30 FPS (33 ms per frame), calculating offsets and sending movement commands with a transmission latency of less than 20 milliseconds. The Flask web interface refreshes live video and mask feeds at 30 FPS, while tension sensor data is updated every 100 milliseconds, providing a responsive and intuitive user experience.
Together, the system achieves near-instantaneous feedback and control with key performance benchmarks: sensor updates at 100 Hz, stepper command execution in under 100 milliseconds, and real-time

UI updates. These metrics ensure the system’s reliability, making it ideal for delicate surgical procedures requiring precision and minimal latency.

- Sensor Update Rate: 100 Hz (every 10 ms)
- Stepper Command Execution: 50–100 ms
- Video Feed and Mask Refresh Rate: 15 FPS (software limited to 30 FPS)
- Sensor Data Display Refresh Rate: 10 Hz (every 100 ms)
- Transmission Latency: <20 ms

## 4 Final Schedule

Task | Responsible Party | Completion Date
Physical Design Prototyping | Sean Schuchman | August 2024
Initial Firmware and Electrical Design | Sean Schuchman, Colton Wall | September 2024
Circuit Breadboarding and Iteration | All Contributors | October 2024
Firmware and PCB Design | Sean Schuchman, Jakob Schoeberle | November 2024
Final Assembly, UI Development, and Tuning | All Contributors | December 2024

The final schedule, shown above, highlights five distinct stages of development.
The first stage focused on physical prototyping, which was completed by the end of August 2024. This early completion allowed us to shift our focus to the second stage, which involved initial iterations of firmware and electrical design. During September 2024, we developed and tested the basic firmware and initial electrical circuits to validate the project’s core functionality.
The third stage involved breadboard prototyping with the Raspberry Pi Pico, stepper drivers, and ADC modules. During this phase, we explored several iterations of the circuit design, testing different parts and strategies to optimize the system. By the end of October 2024, we finalized the circuit design and began prototyping basic firmware to support our selected components.
In the fourth stage, after committing to the finalized circuit design and chosen components, we focused heavily on PCB design to ensure it could be ordered in time. Concurrently, the software and firmware were further developed, with significant progress made by early November 2024.
By late November, the PCB was completed, and all physical and electrical components were assembled and fully integrated. The final stage involved polishing the system, refining the software controller UI, and tuning the machine for optimal performance. During the last week, we focused on preparing our presentation and ensuring the system met all expectations for functionality and reliability.

## 5 Distribution of Effort

Contributor | Area of Contribution
Sean Schuchman | 3D Modeling, Manufacturing, Software/Firmware Design, Prototyping
Jakob Schoeberle | Circuit Design, PCB Design, PCB Assembly
Colton Wall | Circuit Design, Research, Hardware Assembly, System Integration

## 6 Possible Future Work

The thoracic camera system has demonstrated its potential as a reliable surgical visualization tool, but several areas of improvement can be pursued to enhance its functionality, usability, and application scope:

- Miniaturization and Physical Redesign: Scale down the size of the camera probe and tension control module to make the system less intrusive and more versatile for broader surgical applications. A redesigned camera platform can improve maneuverability in confined spaces.
- Integrated Lighting and Compact PCB: Develop a custom PCB with integrated LED lighting for the camera, minimizing the system’s footprint and reducing the need for additional external components.
- PID Control for Camera Movement: Replace the heuristic-based movement algorithm with a PID (Proportional-Integral-Derivative) control system. This would provide more precise, stable, and responsive control over camera movements.
- Alternative Control Options: Explore wireless control systems to eliminate the need for physical cabling in the operating room or integrate foot pedal controls to give surgeons hands-free operation.
- Medical-Grade Material Design: Transition to medical-grade materials for the camera probe, tension wires, and platform to ensure biocompatibility, sterilizability, and compliance with healthcare regulations.
- AI-Based Object Tracking: Implement AI-based object detection and tracking algorithms to improve the accuracy, robustness, and response time of the system’s automatic mode.

- System Robustness and Durability: Enhance the durability of tension wires, load-bearing components, and the gimbal plate to withstand repeated use in clinical environments without performance degradation.
- Clinical Trials and Validation: Conduct extensive testing in simulated and real surgical environments to validate the system’s reliability, safety, and usability in various medical procedures.

These advancements would not only improve the overall functionality and performance of the system but also increase its adaptability for diverse surgical applications, bringing it closer to practical deployment in clinical settings.

## 7 Conclusion

The Thoracic Camera Project represents a well-executed and practical approach to improving visibility and precision in thoracic surgeries. By integrating hardware and software components effectively, the system provides a minimally invasive alternative to traditional methods, which often involve rib removal and extended recovery times. The project successfully demonstrated precise, real-time actuation using tension-controlled wires and object tracking, offering surgeons a clear and stable view of the surgical field.
Each phase of the project contributed to its success, from physical prototyping and electrical design to firmware development and software integration. The prototype leverages the Raspberry Pi 5 for video processing, the Raspberry Pi Pico for tension control, custom PCBs for efficient hardware organization, and a user-friendly interface for seamless operation. The modular and well-documented design lays a solid foundation for future iterations and improvements.
While the project met its core objectives, challenges such as miniaturization and clinical validation remain. Future work could focus on refining the system’s size for broader surgical applications, incorporating AI-based tracking for enhanced precision, and ensuring the use of medical-grade materials for compliance and durability. These refinements would help align the system with real-world surgical needs. Overall, the Thoracic Camera Project achieved its goals and demonstrated the feasibility of an integrated system for minimally invasive surgeries. With further development and testing, the design has the potential to serve as a reliable and effective tool, contributing to incremental improvements in surgical techniques and outcomes.

For a demonstration of the system, watch the demo video. (https://youtu.be/UekYdXSXzXo)

### 7.1 References

- Raspberry Pi Documentation: https://datasheets.raspberrypi.com/rpi5/raspberry-pi-5-product-brief.

pdf (https://datasheets.raspberrypi.com/rpi5/raspberry-pi-5-product-brief.pdf)

- Raspberry Pi Pico Documentation: https://datasheets.raspberrypi.com/pico/pico-datasheet.

pdf (https://datasheets.raspberrypi.com/pico/pico-datasheet.pdf)

- Raspberry Pi Pico C/C++ SDK: https://www.raspberrypi.com/documentation/microcontrollers/

c_sdk.html (https://www.raspberrypi.com/documentation/microcontrollers/c_sdk.html)

- OpenCV Python Documentation: https://opencv.org
- NEMA 17 Datasheet: https://pages.pbclinear.com/rs/909-BFY-775/images/Data-Sheet-Stepper-Motor-Support.

pdf (https://pages.pbclinear.com/rs/909-BFY-775/images/Data-Sheet-Stepper-Motor-Support.pdf)

- L293D Motor Driver Datasheet: https://www.ti.com/product/L293D
- ADS1115 ADC Datasheet: https://www.ti.com/lit/ds/symlink/ads1115.pdf

## 8 Bill of Materials

Name | Description | Quantity | Price (USD) | Cost (USD) | Link
Raspberry Pi 5 | 8GB | 1 | 79.99 | 79.99 | Link (https://www.microcenter.com/product/673711/raspberry-pi-5-8gb-lpddr4x)
Pi Pico | Non-wireless | 1 | 3.99 | 3.99 | Link (https://www.microcenter.com/product/661033/raspberry-pi-pico-microcontroller-development-board)
L293D | Stepper Motor Driver (10 pcs) | 1 | 8.99 | 3.60 | Link (https://www.amazon.com/gp/product/B09NBQYVLL/ref=ppx_yo_dt_b_asin_title_o00_s00)
M3 Screw Set | Metric Screws with Nuts | 1 | 8.99 | 1.18 | Link (https://www.amazon.com/dp/B0BMQFHD8H?ref_=yo_ov_dt_b_fed_asin_title)
Ball Bearing | 3mm Bore | 1 | 8.29 | 4.97 | Link (https://www.amazon.com/dp/B07WF18HQY?ref_=ppx_yo2ov_dt_b_fed_asin_title)
Threaded Inserts | M3 brass threaded insert | 1 | 6.99 | 2.10 | Link (https://www.amazon.com/dp/B0CCX33LHD?ref_=ppx_yo2ov_dt_b_fed_asin_title)
Mount Bracket | Nema 17 mounting bracket (4 pcs) | 1 | 14.99 | 14.99 | Link (https://www.amazon.com/dp/B07JW6X9ZR?ref_=ppx_yo2ov_dt_b_fed_asin_title)
Load Cell | 1kg load cell (4 pcs) | 1 | 15.49 | 15.49 | Link (https://www.amazon.com/dp/B09YTQKQ9G/ref=ppx_yo_dt_b_search_asin_title)
Pi Camera | Pi Camera V3 – Wide | 1 | 34.99 | 34.99 | Link (https://www.microcenter.com/product/662018/raspberry-pi-camera-3-wide)
Camera Cable | Standard → Mini Pi camera cable | 1 | 1.99 | 1.99 | Link (https://www.microcenter.com/product/671933/raspberry-pi-5-camera-cable-300mm)
Printed Circuit Board | Custom Designed PCB | 5 | 60.92 | 60.92 | Link (https://jlcpcb.com/)
PCB Components | Electrical Components | n/a | 22.75 | 22.75 | Link (https://www.digikey.com/)
Total | | | 268.37 | 247.96

## 9 Acknowledgements

We extend our gratitude to:

- Dr. Amardeep Kaur for her guidance and mentorship throughout the project.
- Dr. Timothy York for technical specifications and project requirements.
- Craig Watson for technical guidance and perspective throughout the project.
- SIUE (Southern Illinois University Edwardsville) URCA (Undergraduate Research and Creative Activities) for allowing us to adopt the Thoracic Camera Project as a senior design project.
- SIUE ECE (Electrical and Computer Engineering) Department for providing the resources and lab space.

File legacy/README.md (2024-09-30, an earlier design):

# ThorCam
## URCA

# Contributors
Sean Schuchman: January 2024 - July 2024

# Setup

# Push to Remote
*** git push [URL] will not work:
```
git init
git add .
git commit -m "<insert comment here>"
git push --set-upstream origin --all
```

# Project Hierarchy
- Raspberry Pi 4
    - Handle camera module video feed
    - Computer vision to determine location of target
    - Send input to Pico Controller to handle actuation of camera in desired direction

- Pico Controller
    - Takes in input of direction to drive the camera actuation
    - Takes in sensor data from tension modules to maintain proper control wire tension
    - Drives stepper motors for tension wire control

- Tension Module
    - Reads control wire tension via pressure sensor
    - Analog signal fed through Op-Amp buffer to ADC module
    - ACD module connected to I2C bus
    - Four tension modules for each control wire are connected along Pico Controller I2C bus by the ACD module I2C interface
    - Tension module provides analog data on pressure sensor, as well as target tension by means of analog voltage

# Pico Controller
The Pico Controller is designed to serve as the abstraction layer between the computer vision element and the camera actuation control. This is intended to simplify the project by containerizing the physical movement and control of the camera into a simple to interface.

The Pico Controller is configured to handle camera actuation by control of the stepper motor wires, as well as receive data from the tension modules to adjust the control wires to maintain proper balance.

The Pico Controller can be controlled manually or via remote software driver with simple controls to actuate the camera in any combination of x-plane or y-plane directions.

Project files can be found under the project directory:
/dev/pico_controller

## Hardware
- Raspberry Pi Pico
    - RP2040 microcontroller chip
    - Dual-core ARM Cortex M0+ processor, clock up to 133 MHz
    - 264kB SRAM, 2MB on-board flash memory

## Dev Environment
- Raspberry Pi 4
    - Thonny IDE
    - MircoPython SDK for Pi Pico

## Raspberry Pi Pico Setup
Follow steps in YouTube tutorial for setup:
https://www.youtube.com/watch?v=Zy64kZEM_bg

1. Connect Pi Pico to Raspberry Pi 4 (or alternative version) via USB. Be sure to hold down reset button on Pi Pico while connecting to enable bootloader mode.
2. Access Pi Pico as a directory in file explorer.
3. Copy the MicroPython library 'RPI_PICO-20240105-v1.22.1.uf2' to the Pi Pico. MicroPython UF2 library file can be found in project directory: /dev/pico_controller.
4. Pi Pico should be ready to target as available device in Thonny IDE.

More information can be found at Raspberry Pi Pico Docs:
https://www.raspberrypi.com/documentation/microcontrollers/micropython.html

- Download the latest UF2 file from this page. Found under "Download the correct MicroPython UF2 file for your board:" and select the appropriate device.

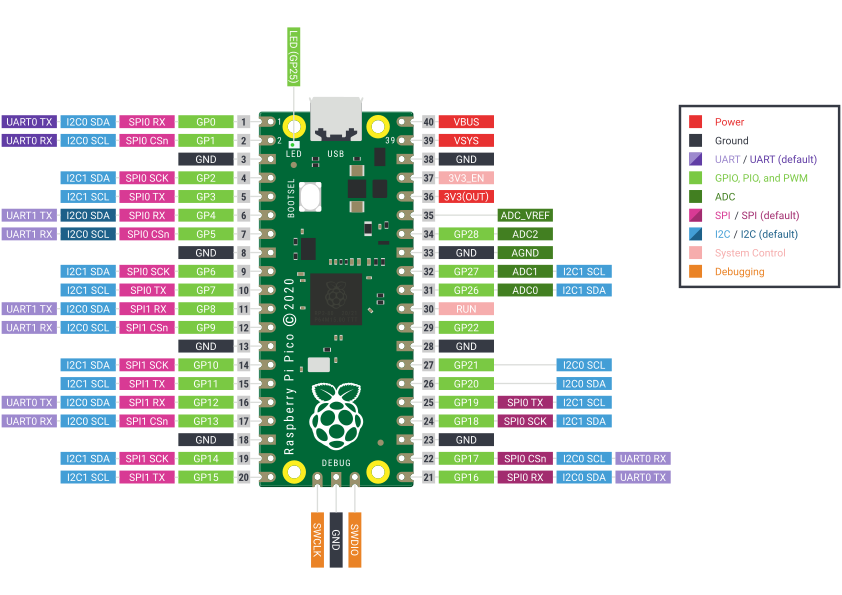
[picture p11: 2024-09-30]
Datasheets/pico-pinout.png

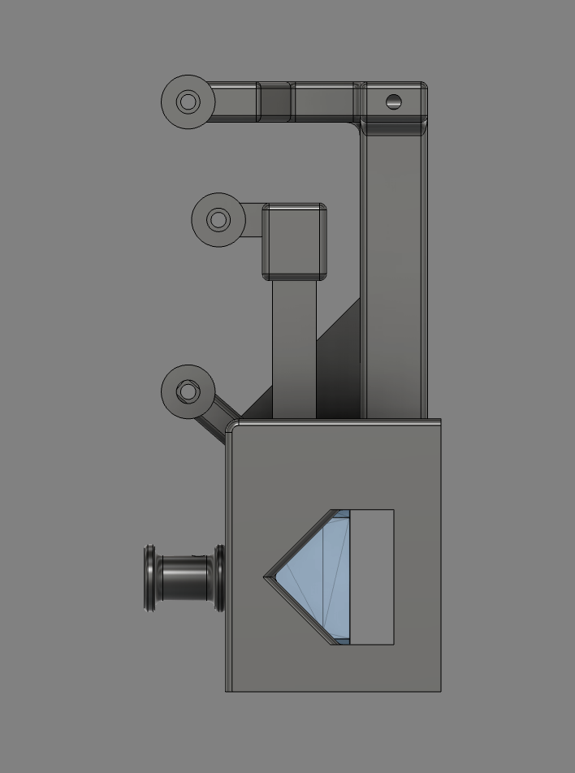
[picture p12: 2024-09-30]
3D_Models/images/tension/Screenshot 2024-08-27 at 11.53.16 AM.png

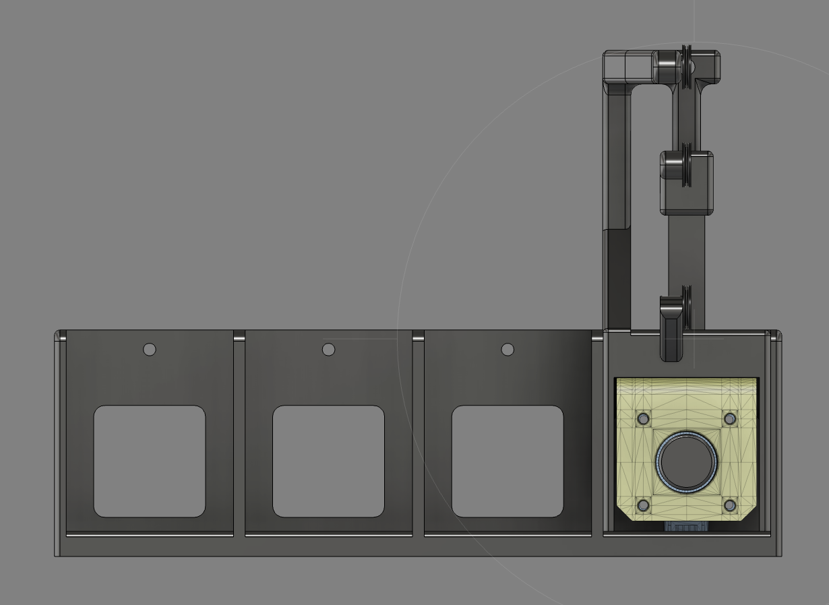
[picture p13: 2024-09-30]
3D_Models/images/tension/Screenshot 2024-08-27 at 11.53.03 AM.png

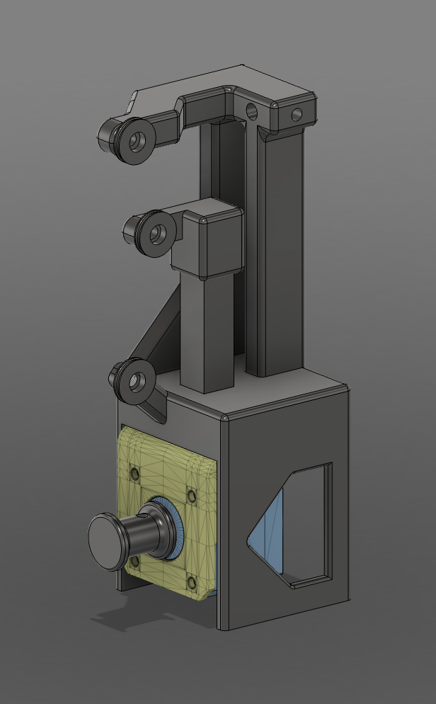
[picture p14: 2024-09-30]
3D_Models/images/tension/Screenshot 2024-08-27 at 11.53.59 AM.png

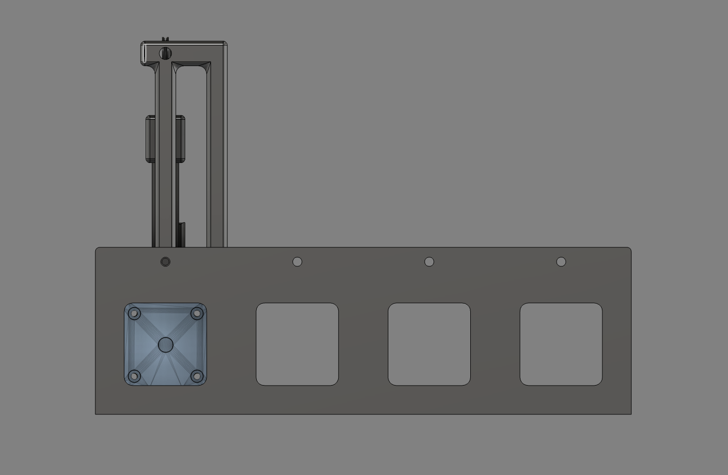
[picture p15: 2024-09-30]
3D_Models/images/tension/Screenshot 2024-08-27 at 11.53.25 AM.png

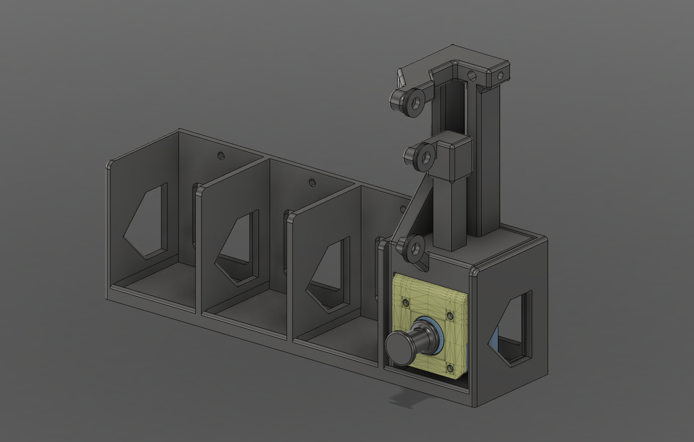
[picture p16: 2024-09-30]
3D_Models/images/tension/Screenshot 2024-08-27 at 11.52.42 AM.png

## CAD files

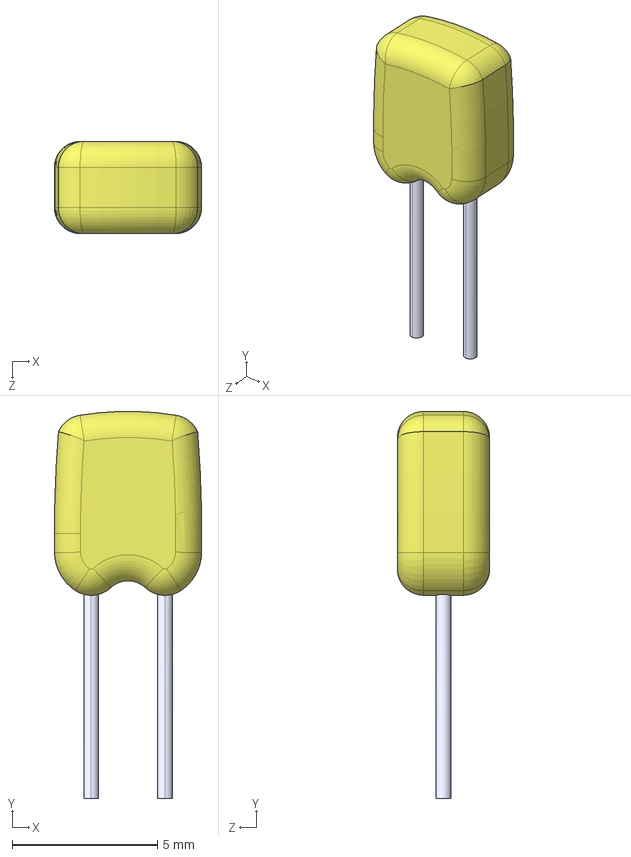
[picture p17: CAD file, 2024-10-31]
Hardware/ThorParts/3D Models/C320C104K5R5TA.step
5.08 x 13.3 x 3.18 mm

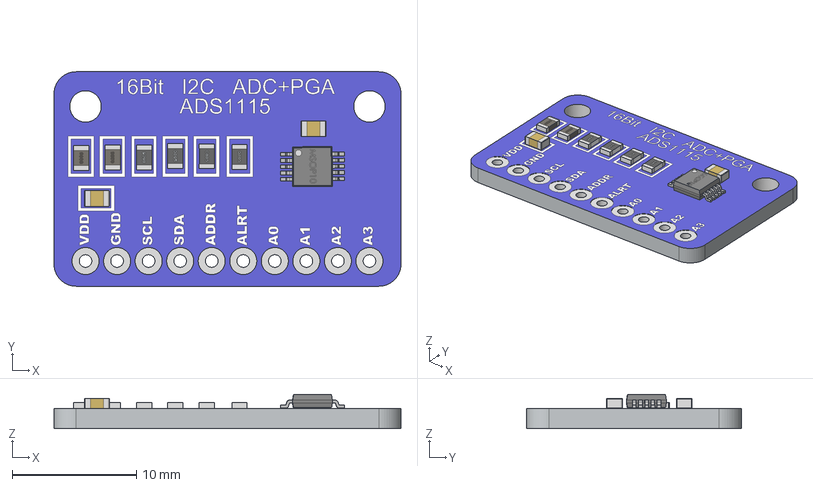
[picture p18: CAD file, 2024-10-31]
Hardware/ThorParts/3D Models/16Bit I2C ADC+PGA - ADS1115.stp
27.9 x 17.3 x 2.74 mm
ADS1115
0805 Capacitor x 2
0805 Inductor x 2
0805 Resistor x 4
MSOP10

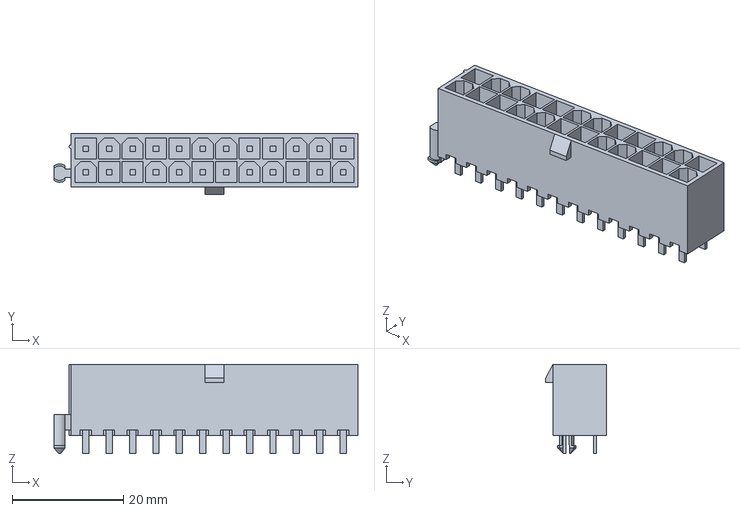
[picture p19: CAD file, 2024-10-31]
Hardware/ThorParts/3D Models/1-1775099-3.stp
54.6 x 10.9 x 16.0 mm

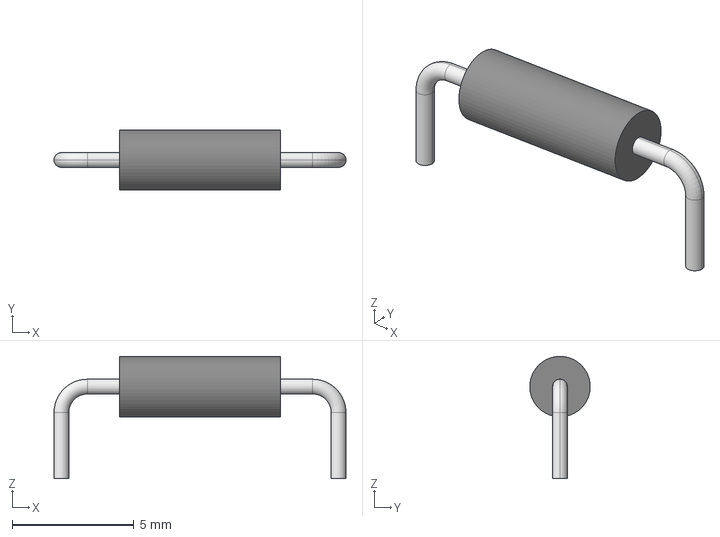
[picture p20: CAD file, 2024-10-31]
Hardware/ThorParts/3D Models/RES_TYCO_YR1_TYC.step
12.0 x 2.49 x 5.03 mm

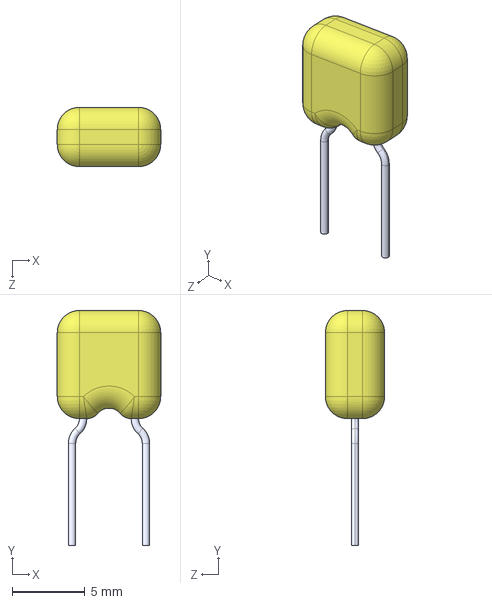
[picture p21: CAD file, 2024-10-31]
Hardware/ThorParts/3D Models/C330C105K5R5TA7301.STEP
7.11 x 16.1 x 4.07 mm

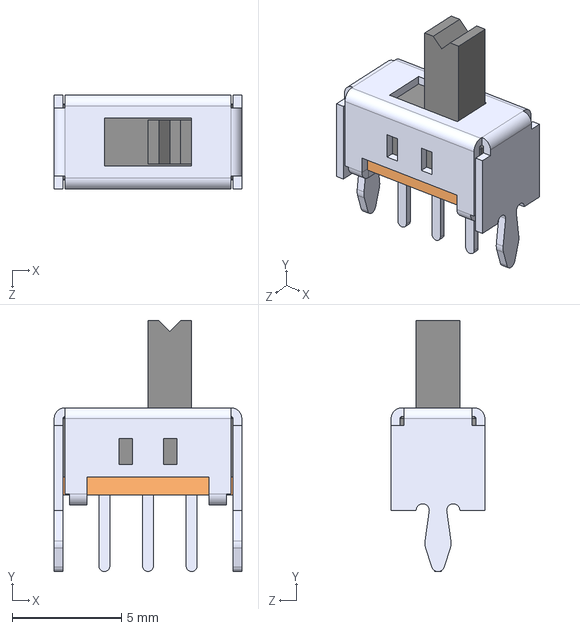
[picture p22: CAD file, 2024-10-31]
Hardware/ThorParts/3D Models/OS102011MS2QN1.step
8.60 x 11.5 x 4.30 mm

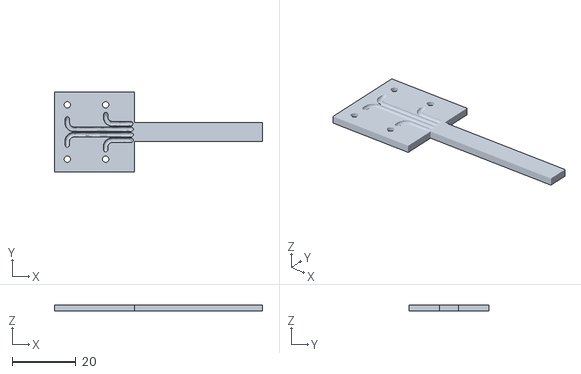
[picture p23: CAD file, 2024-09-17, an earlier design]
legacy/pre-2024/CamBracket.stl
65.0 x 25.0 x 2.00

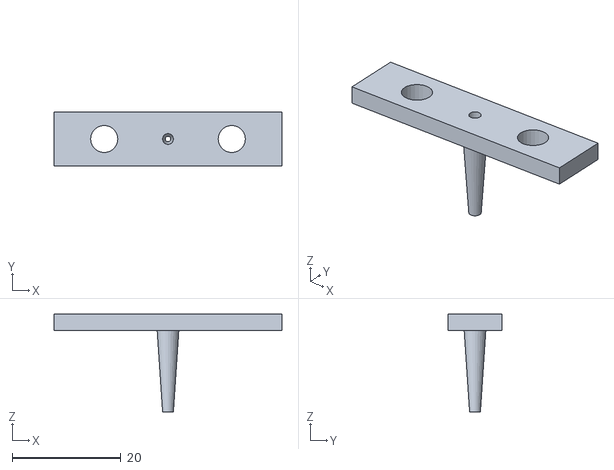
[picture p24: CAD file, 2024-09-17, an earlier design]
legacy/pre-2024/NewStringBracket.stl
42.0 x 10.00 x 18.0

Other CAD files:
3D_Models/files/Camera_Adapter_v3.f3d
3D_Models/files/Case_Passthrough_v4.f3d
3D_Models/files/Tension_Module_v3-v7.f3d

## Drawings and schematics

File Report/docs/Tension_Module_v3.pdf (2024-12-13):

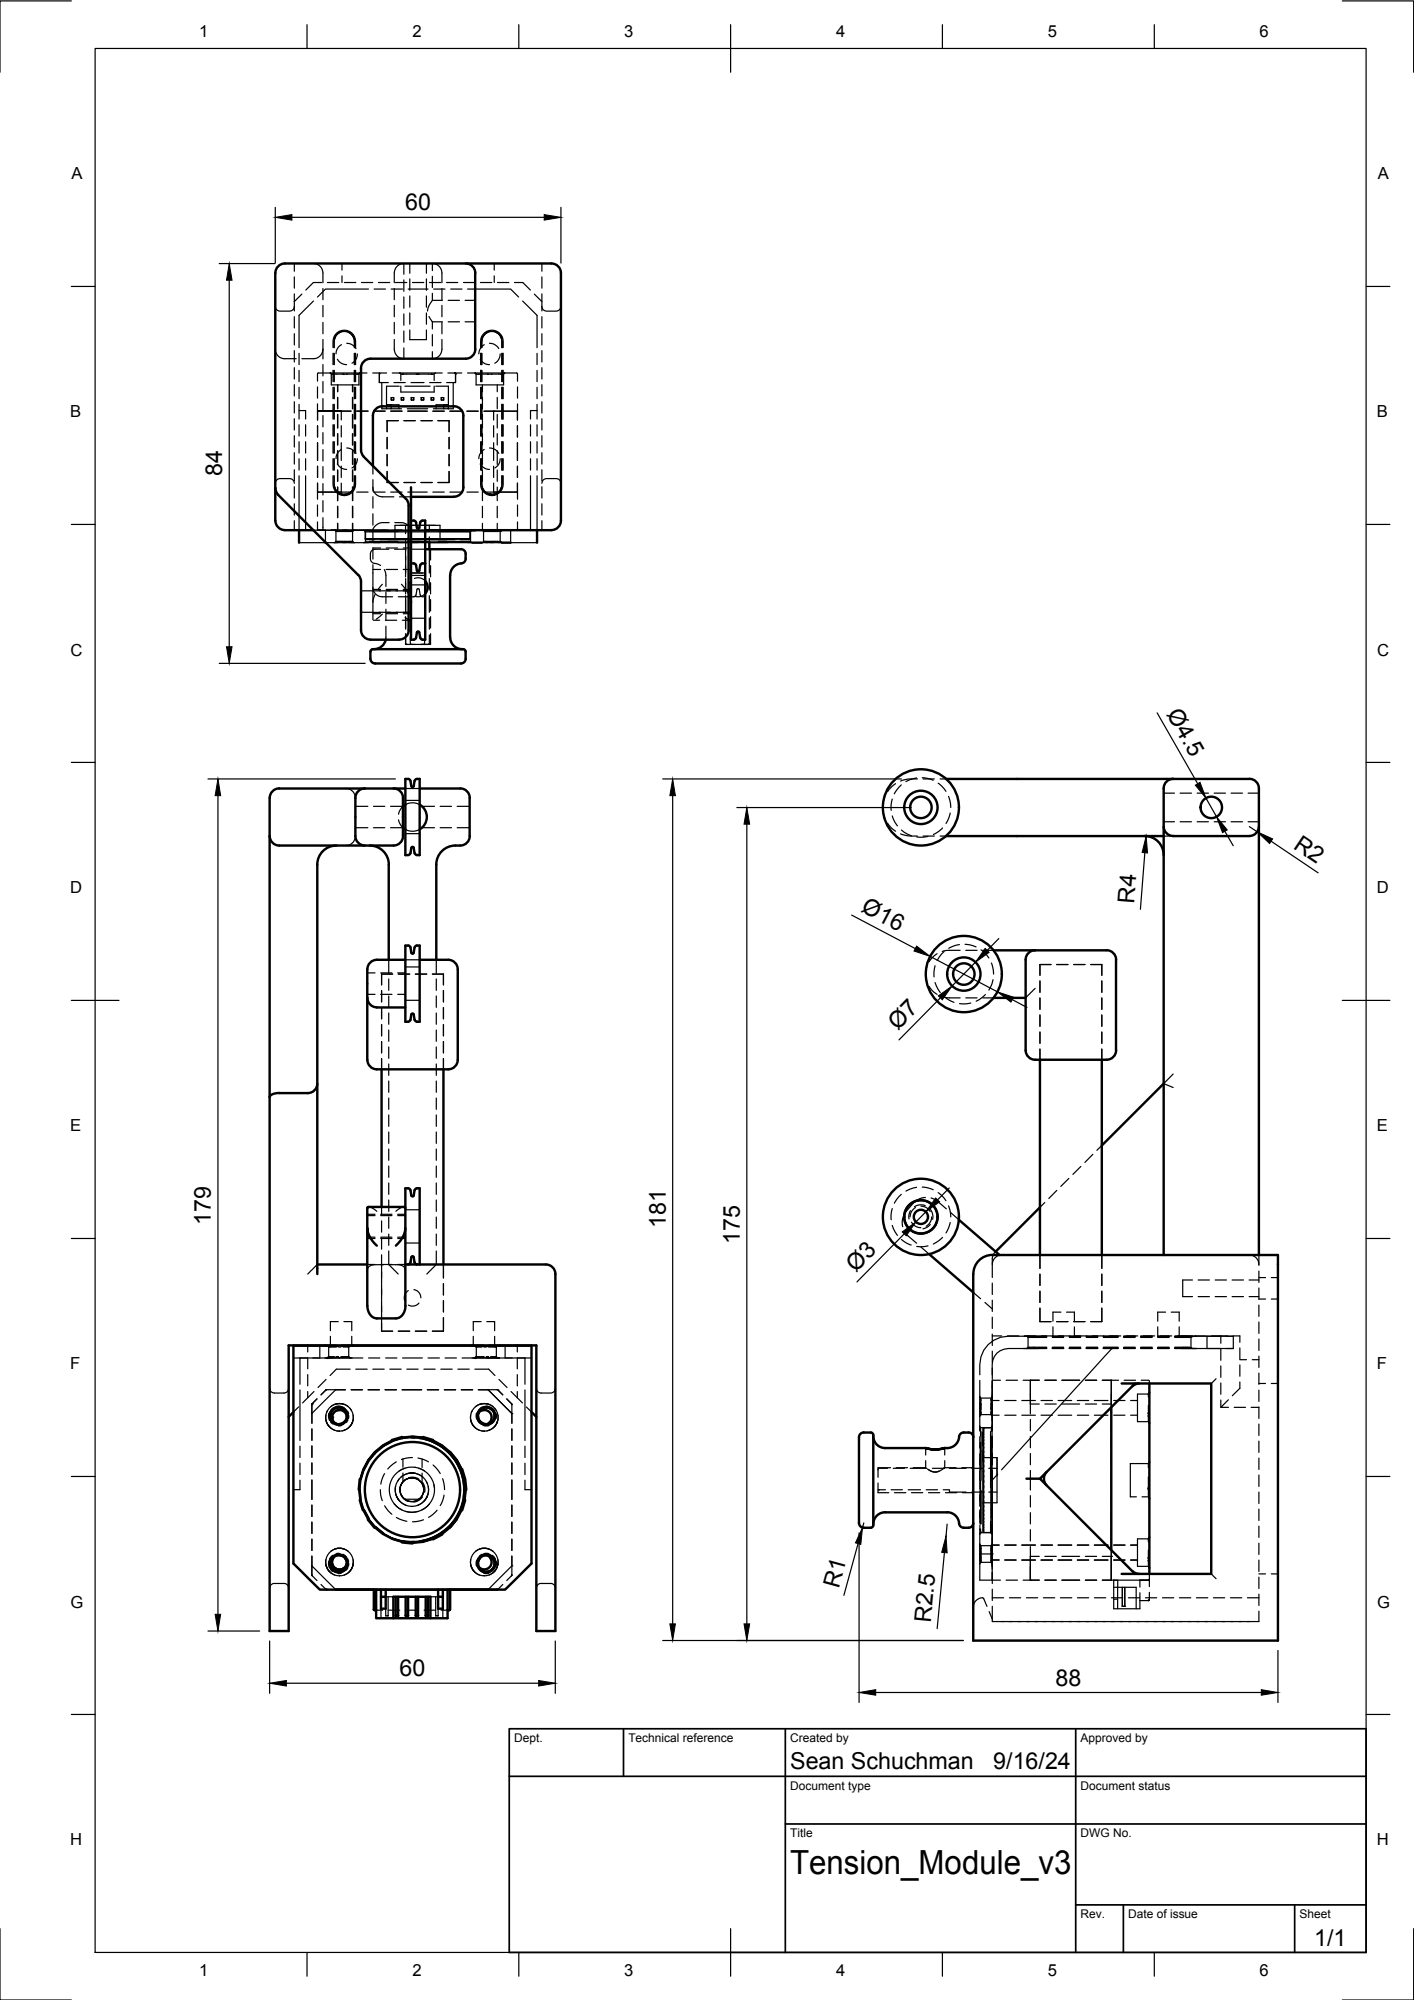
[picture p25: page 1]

Dept. | Technical reference | Created by Sean Schuchman 9/16/24 | Approved by

Document type | Document status

Title Tension_Module_v3 | DWG No.

Rev. | Date of issue | Sheet 1/1

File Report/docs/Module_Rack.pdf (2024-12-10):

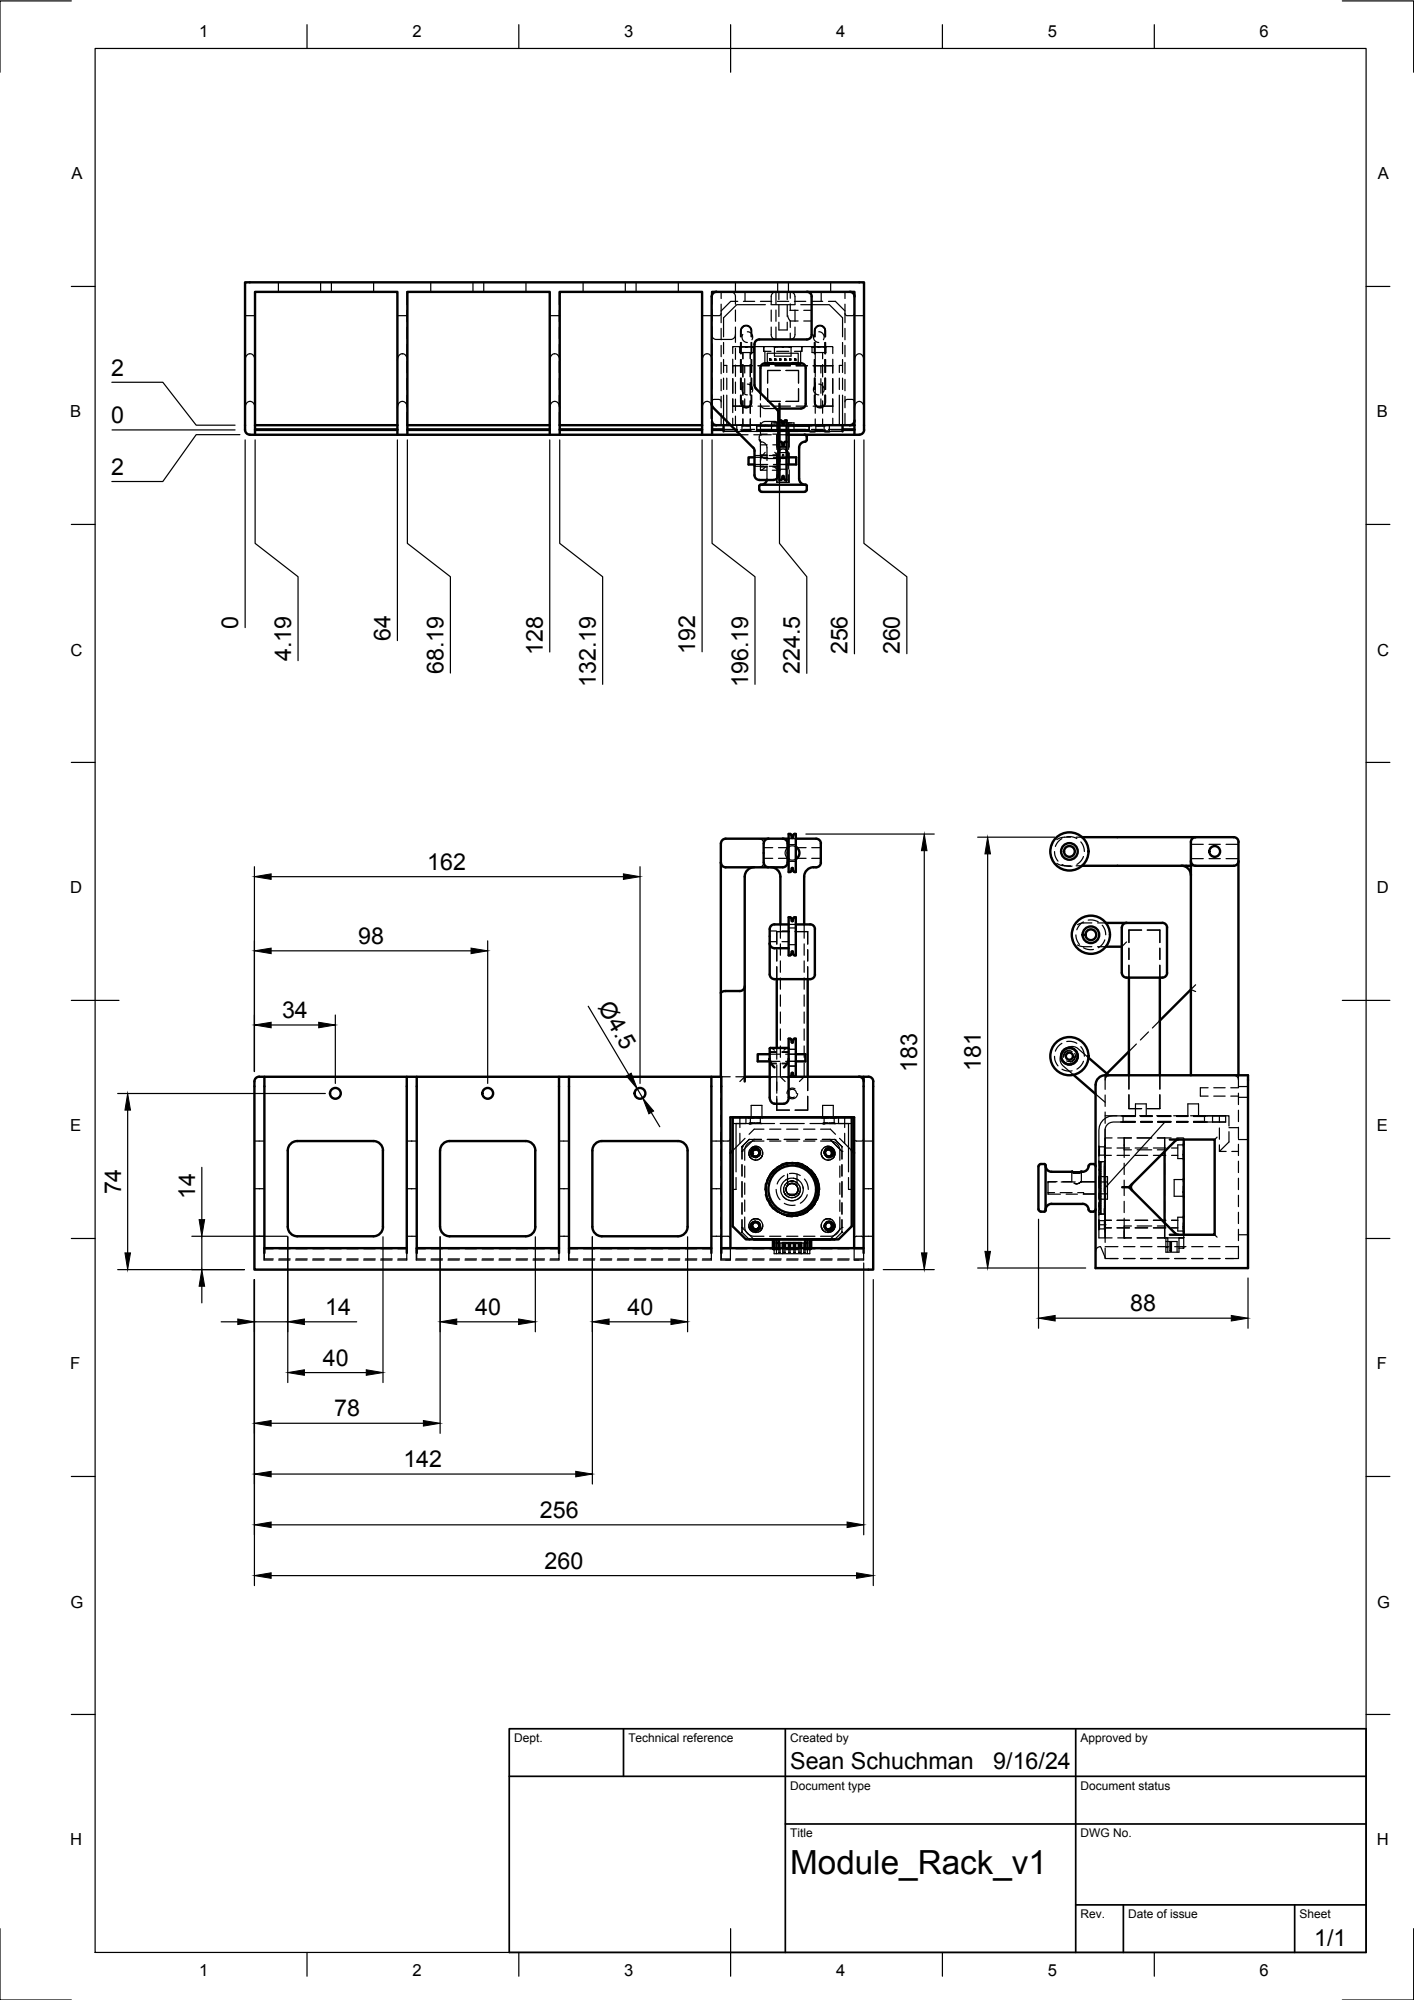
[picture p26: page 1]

Dept. | Technical reference | Created by Sean Schuchman 9/16/24 | Approved by

Document type | Document status

Title Module_Rack_v1 | DWG No.

Rev. | Date of issue | Sheet 1/1

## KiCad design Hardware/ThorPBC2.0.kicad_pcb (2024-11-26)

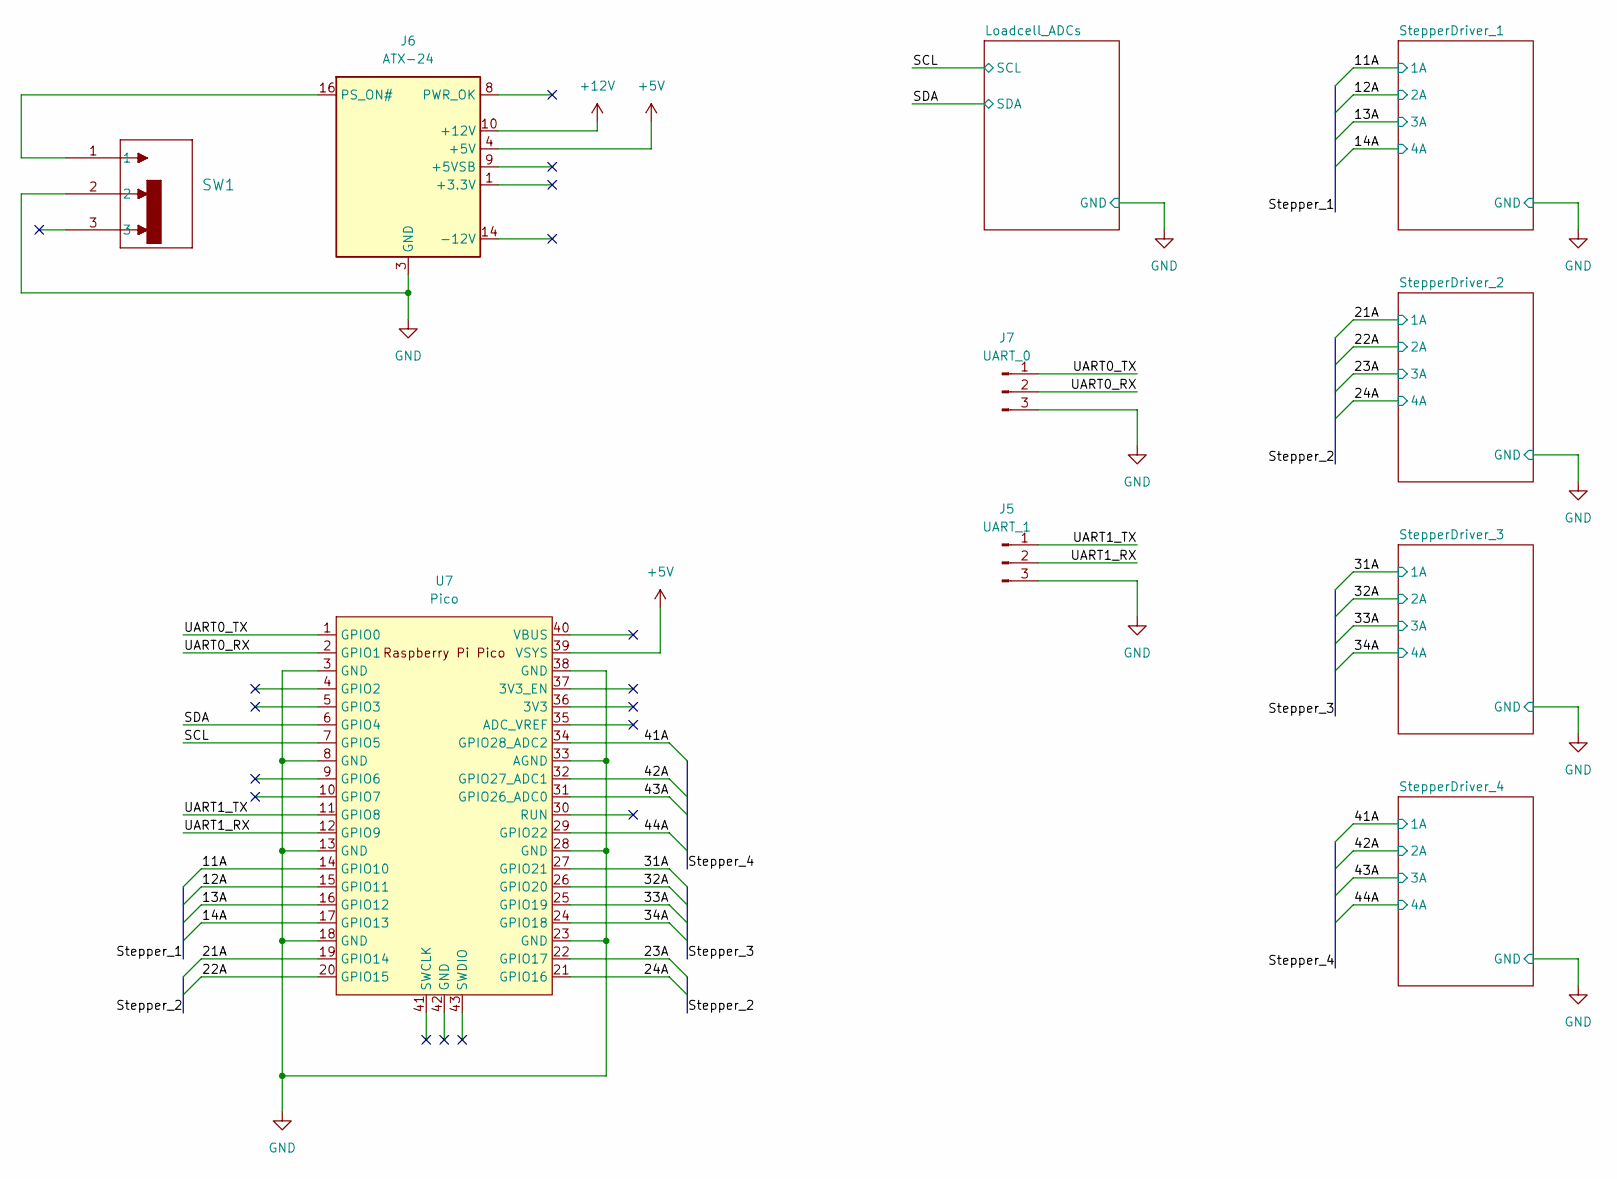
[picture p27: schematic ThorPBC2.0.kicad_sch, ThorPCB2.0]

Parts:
J5: UART_1; PinHeader_1x03_P2.54mm_Vertical
J6: ATX-24; Molex_Mini-Fit_Jr_5566-24A_2x12_P4.20mm_Vertical_Thor
J7: UART_0; PinHeader_1x03_P2.54mm_Vertical
SW1: OS102011MS2QN1; SPDT_OS102011_CNK
U7: Pico; RPi_Pico_SMD_TH

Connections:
+5V: J6.4 (+5V), J6.6 (+5V), J6.21 (+5V), J6.22 (+5V), J6.23 (+5V), U7.39 (VSYS); also elsewhere on the board
+12V: J6.10 (+12V), J6.11 (+12V); also elsewhere on the board
/11A: U7.14 (GPIO10); also elsewhere on the board
/12A: U7.15 (GPIO11); also elsewhere on the board
/13A: U7.16 (GPIO12); also elsewhere on the board
/14A: U7.17 (GPIO13); also elsewhere on the board
/21A: U7.19 (GPIO14); also elsewhere on the board
/22A: U7.20 (GPIO15); also elsewhere on the board
/23A: U7.22 (GPIO17); also elsewhere on the board
/24A: U7.21 (GPIO16); also elsewhere on the board
/31A: U7.27 (GPIO21); also elsewhere on the board
/32A: U7.26 (GPIO20); also elsewhere on the board
/33A: U7.25 (GPIO19); also elsewhere on the board
/34A: U7.24 (GPIO18); also elsewhere on the board
/41A: U7.34 (GPIO28_ADC2); also elsewhere on the board
/42A: U7.32 (GPIO27_ADC1); also elsewhere on the board
/43A: U7.31 (GPIO26_ADC0); also elsewhere on the board
/44A: U7.29 (GPIO22); also elsewhere on the board
/SCL: U7.7 (GPIO5); also elsewhere on the board
/SDA: U7.6 (GPIO4); also elsewhere on the board
/UART0_RX: J7.2, U7.2 (GPIO1)
/UART0_TX: J7.1, U7.1 (GPIO0)
/UART1_RX: J5.2, U7.12 (GPIO9)
/UART1_TX: J5.1, U7.11 (GPIO8)
GND: J5.3, J6.3 (GND), J6.5 (GND), J6.7 (GND), J6.15 (GND), J6.17 (GND), J6.18 (GND), J6.19 (GND), J6.24 (GND), J7.3, SW1.2, U7.3 (GND), U7.8 (GND), U7.13 (GND), U7.18 (GND), U7.23 (GND), U7.28 (GND), U7.33 (AGND), U7.38 (GND); also elsewhere on the board
unnamed: J6.16 (PS_ON#), SW1.1

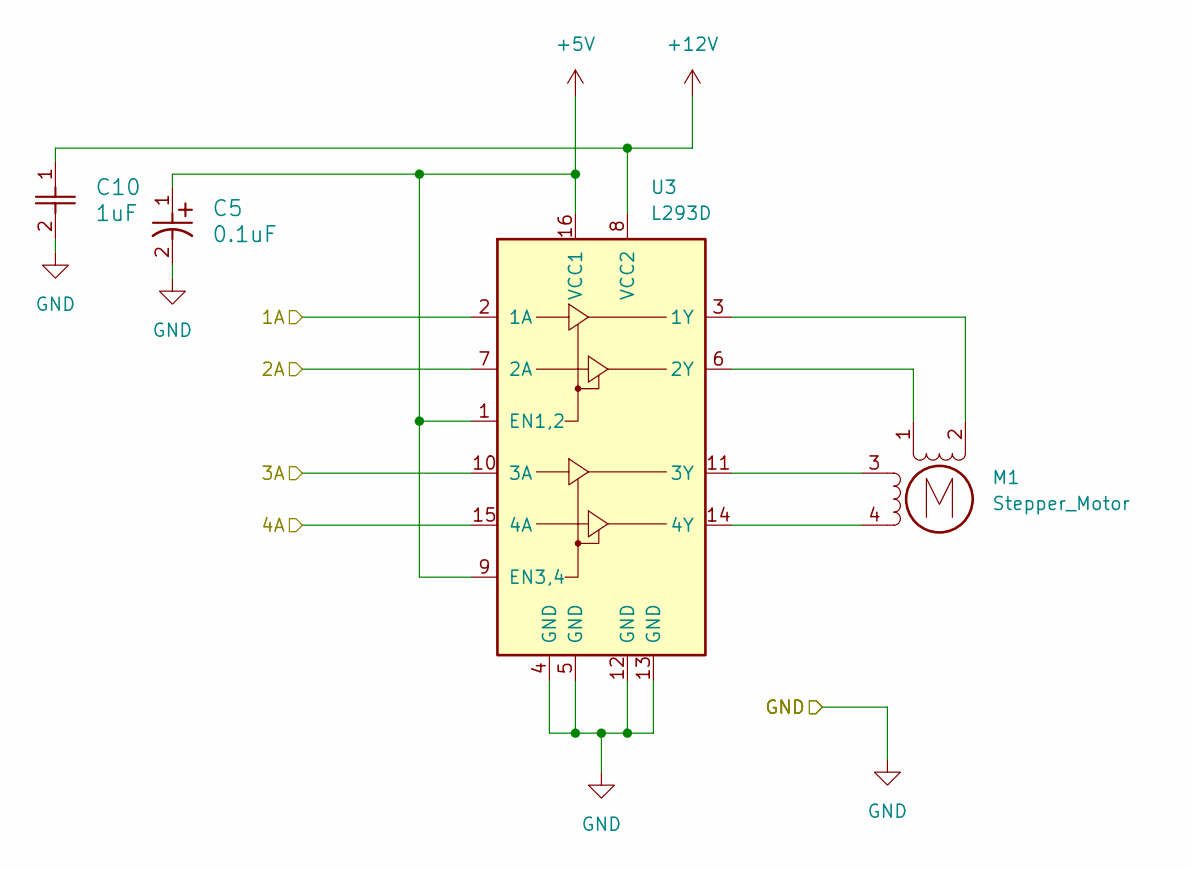
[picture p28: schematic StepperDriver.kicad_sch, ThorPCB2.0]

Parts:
C5: 0.1uF; CAP_C320_KEM
C10: 1uF; CAP_C330C_MR_X7R_KEM
M1: Stepper_Motor; TerminalBlock_Phoenix_MPT-0,5-4-2.54_1x04_P2.54mm_Horizontal
U3: L293D; DIP-16_W7.62mm

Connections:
+5V: C5.1, U3.1 (EN1,2), U3.9 (EN3,4), U3.16 (VCC1); also elsewhere on the board
+12V: C10.1, U3.8 (VCC2); also elsewhere on the board
/11A: U3.2 (1A); also elsewhere on the board
/12A: U3.7 (2A); also elsewhere on the board
/13A: U3.10 (3A); also elsewhere on the board
/14A: U3.15 (4A); also elsewhere on the board
GND: C5.2, C10.2, U3.4 (GND), U3.5 (GND), U3.12 (GND), U3.13 (GND); also elsewhere on the board
unnamed: M1.2 (-), U3.3 (1Y)
unnamed: M1.1, U3.6 (2Y)
unnamed: M1.3, U3.11 (3Y)
unnamed: M1.4, U3.14 (4Y)

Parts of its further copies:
C7, C8, C9: 0.1uF; CAP_C320_KEM
C11, C12, C13: 1uF; CAP_C330C_MR_X7R_KEM
M2, M3, M4: Stepper_Motor; TerminalBlock_Phoenix_MPT-0,5-4-2.54_1x04_P2.54mm_Horizontal
U4, U5, U6: L293D; DIP-16_W7.62mm

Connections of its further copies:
+5V: C7.1, C8.1, C9.1, U4.1 (EN1,2), U4.9 (EN3,4), U4.16 (VCC1), U5.1 (EN1,2), U5.9 (EN3,4), U5.16 (VCC1), U6.1 (EN1,2), U6.9 (EN3,4), U6.16 (VCC1); also elsewhere on the board
+12V: C11.1, C12.1, C13.1, U4.8 (VCC2), U5.8 (VCC2), U6.8 (VCC2); also elsewhere on the board
/21A: U4.2 (1A); also elsewhere on the board
/22A: U4.7 (2A); also elsewhere on the board
/23A: U4.10 (3A); also elsewhere on the board
/24A: U4.15 (4A); also elsewhere on the board
/31A: U5.2 (1A); also elsewhere on the board
/32A: U5.7 (2A); also elsewhere on the board
/33A: U5.10 (3A); also elsewhere on the board
/34A: U5.15 (4A); also elsewhere on the board
/41A: U6.2 (1A); also elsewhere on the board
/42A: U6.7 (2A); also elsewhere on the board
/43A: U6.10 (3A); also elsewhere on the board
/44A: U6.15 (4A); also elsewhere on the board
GND: C7.2, C8.2, C9.2, C11.2, C12.2, C13.2, U4.4 (GND), U4.5 (GND), U4.12 (GND), U4.13 (GND), U5.4 (GND), U5.5 (GND), U5.12 (GND), U5.13 (GND), U6.4 (GND), U6.5 (GND), U6.12 (GND), U6.13 (GND); also elsewhere on the board
unnamed: M2.2 (-), U4.3 (1Y)
unnamed: M3.2 (-), U5.3 (1Y)
unnamed: M4.2 (-), U6.3 (1Y)
unnamed: M2.1, U4.6 (2Y)
unnamed: M2.3, U4.11 (3Y)
unnamed: M2.4, U4.14 (4Y)
unnamed: M3.1, U5.6 (2Y)
unnamed: M3.3, U5.11 (3Y)
unnamed: M3.4, U5.14 (4Y)
unnamed: M4.1, U6.6 (2Y)
unnamed: M4.3, U6.11 (3Y)
unnamed: M4.4, U6.14 (4Y)

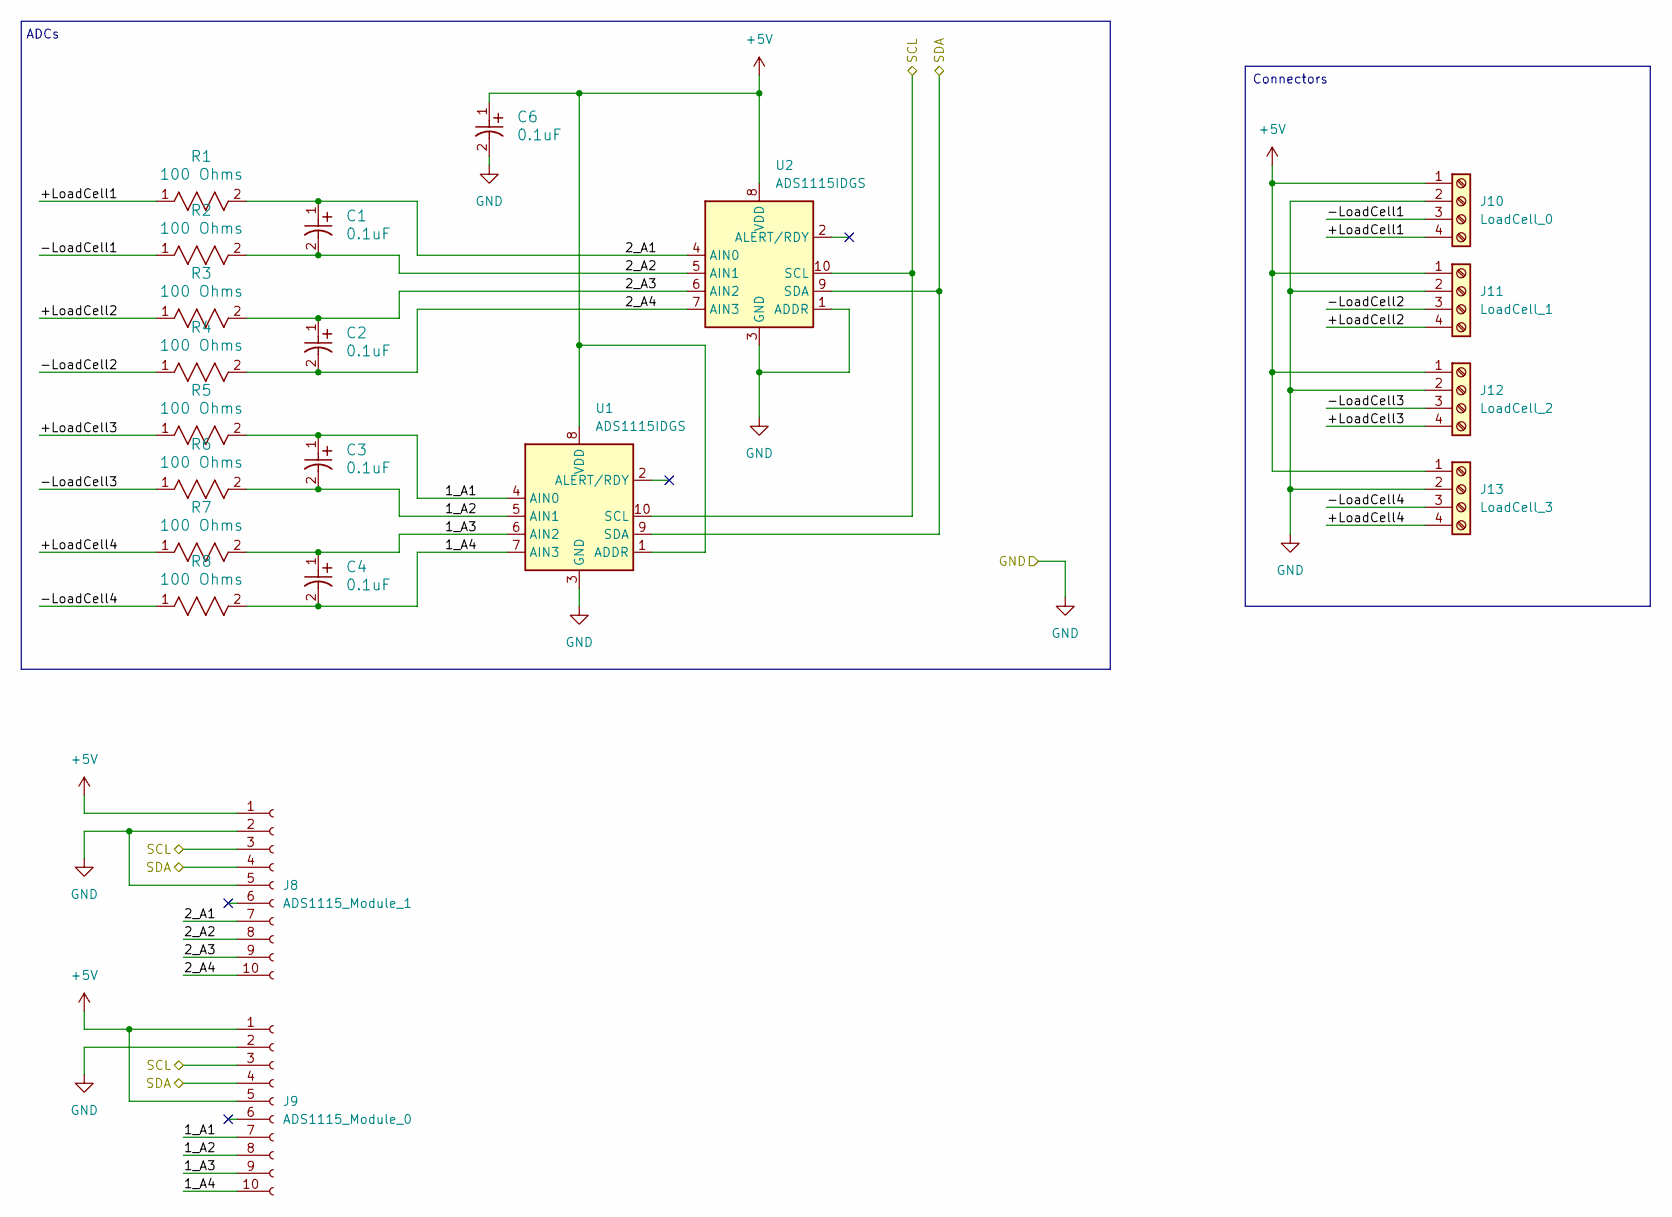
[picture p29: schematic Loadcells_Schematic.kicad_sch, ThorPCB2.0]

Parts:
C1, C2, C3, C4, C6: 0.1uF; CAP_C320_KEM
J8: ADS1115_Module_1; ADS1115_1x10_P2.54mm_Vertical
J9: ADS1115_Module_0; ADS1115_1x10_P2.54mm_Vertical
J10: LoadCell_0; TerminalBlock_Phoenix_MPT-0,5-4-2.54_1x04_P2.54mm_Horizontal
J11: LoadCell_1; TerminalBlock_Phoenix_MPT-0,5-4-2.54_1x04_P2.54mm_Horizontal
J12: LoadCell_2; TerminalBlock_Phoenix_MPT-0,5-4-2.54_1x04_P2.54mm_Horizontal
J13: LoadCell_3; TerminalBlock_Phoenix_MPT-0,5-4-2.54_1x04_P2.54mm_Horizontal
R1, R2, R3, R4, R5, R6, R7, R8: 100 Ohms; RES_TYCO_YR1_TYC
U1, U2: ADS1115IDGS; TSSOP-10_3x3mm_P0.5mm

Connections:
+5V: C6.1, J8.1, J9.1, J9.5, J10.1, J11.1, J12.1, J13.1, U1.1 (ADDR), U1.8 (VDD), U2.8 (VDD); also elsewhere on the board
/Loadcell_ADCs/1_A1: C3.1, J9.7, R5.2, U1.4 (AIN0)
/Loadcell_ADCs/1_A2: C3.2, J9.8, R6.2, U1.5 (AIN1)
/Loadcell_ADCs/1_A3: C4.1, J9.9, R7.2, U1.6 (AIN2)
/Loadcell_ADCs/1_A4: C4.2, J9.10, R8.2, U1.7 (AIN3)
/Loadcell_ADCs/2_A1: C1.1, J8.7, R1.2, U2.4 (AIN0)
/Loadcell_ADCs/2_A2: C1.2, J8.8, R2.2, U2.5 (AIN1)
/Loadcell_ADCs/2_A3: C2.1, J8.9, R3.2, U2.6 (AIN2)
/Loadcell_ADCs/2_A4: C2.2, J8.10, R4.2, U2.7 (AIN3)
/Loadcell_ADCs/+LoadCell1: J10.4, R1.1
/Loadcell_ADCs/+LoadCell2: J11.4, R3.1
/Loadcell_ADCs/+LoadCell3: J12.4, R5.1
/Loadcell_ADCs/+LoadCell4: J13.4, R7.1
/Loadcell_ADCs/-LoadCell1: J10.3, R2.1
/Loadcell_ADCs/-LoadCell2: J11.3, R4.1
/Loadcell_ADCs/-LoadCell3: J12.3, R6.1
/Loadcell_ADCs/-LoadCell4: J13.3, R8.1
/SCL: J8.3, J9.3, U1.10 (SCL), U2.10 (SCL); also elsewhere on the board
/SDA: J8.4, J9.4, U1.9 (SDA), U2.9 (SDA); also elsewhere on the board
GND: C6.2, J8.2, J8.5, J9.2, J10.2, J11.2, J12.2, J13.2, U1.3 (GND), U2.1 (ADDR), U2.3 (GND); also elsewhere on the board

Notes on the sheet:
ADCs
Connectors

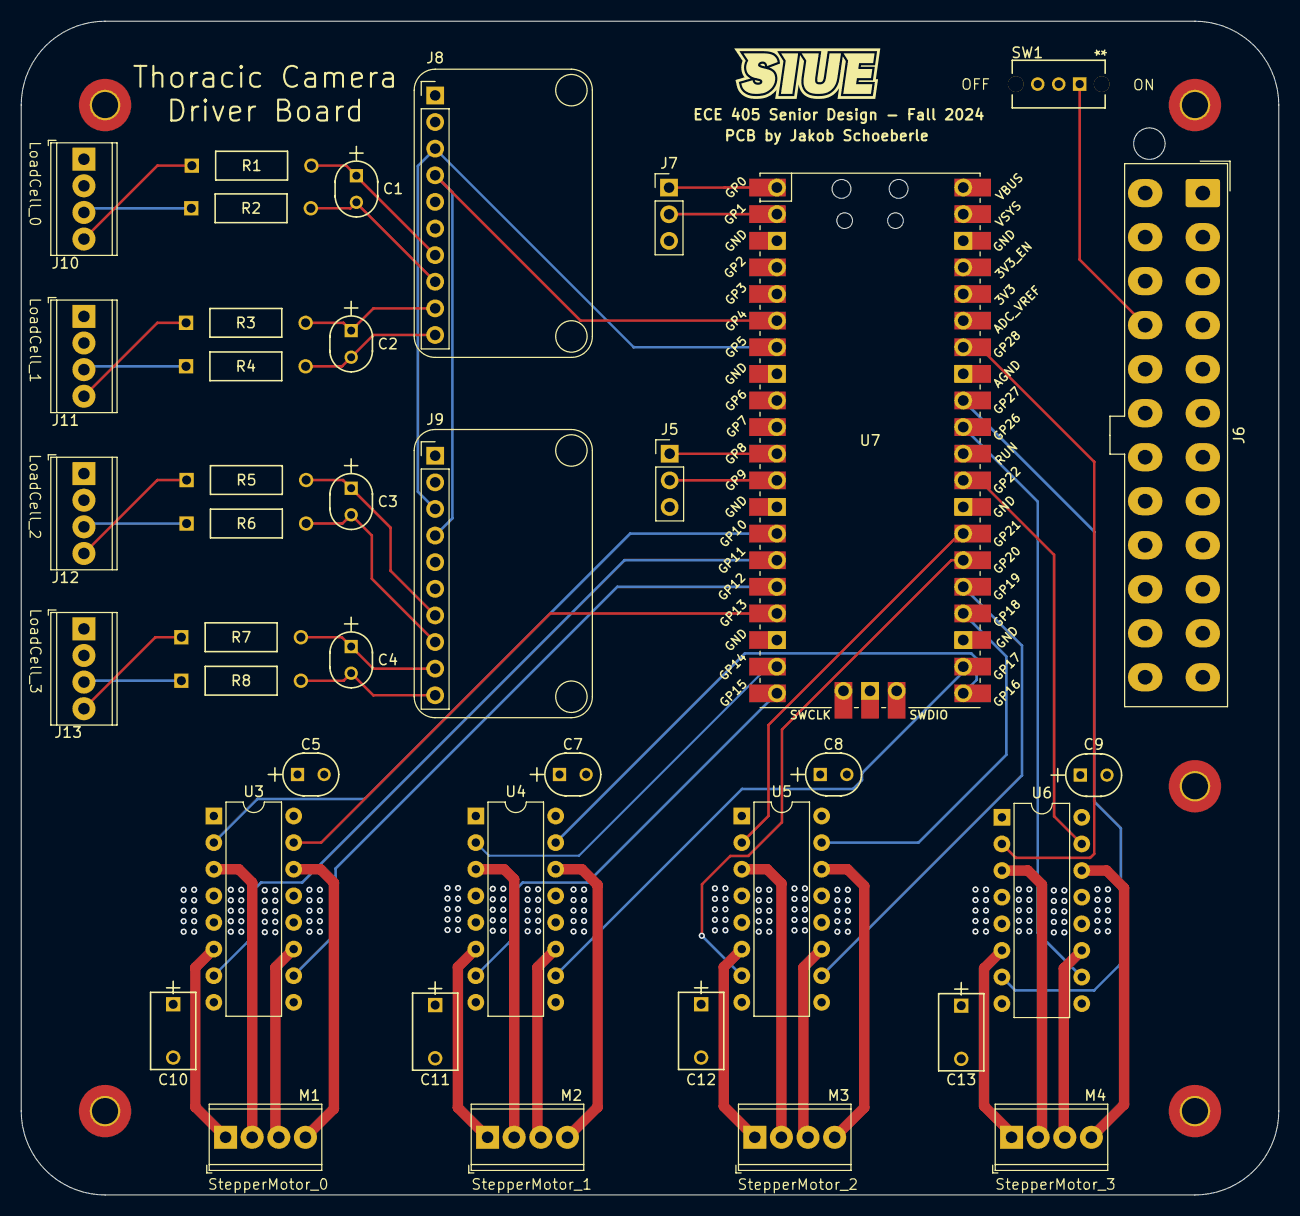
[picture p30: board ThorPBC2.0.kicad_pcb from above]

Board: 4 copper layers, 120.0 x 112.0 mm, 39 parts (0 on the bottom side), 58 nets.

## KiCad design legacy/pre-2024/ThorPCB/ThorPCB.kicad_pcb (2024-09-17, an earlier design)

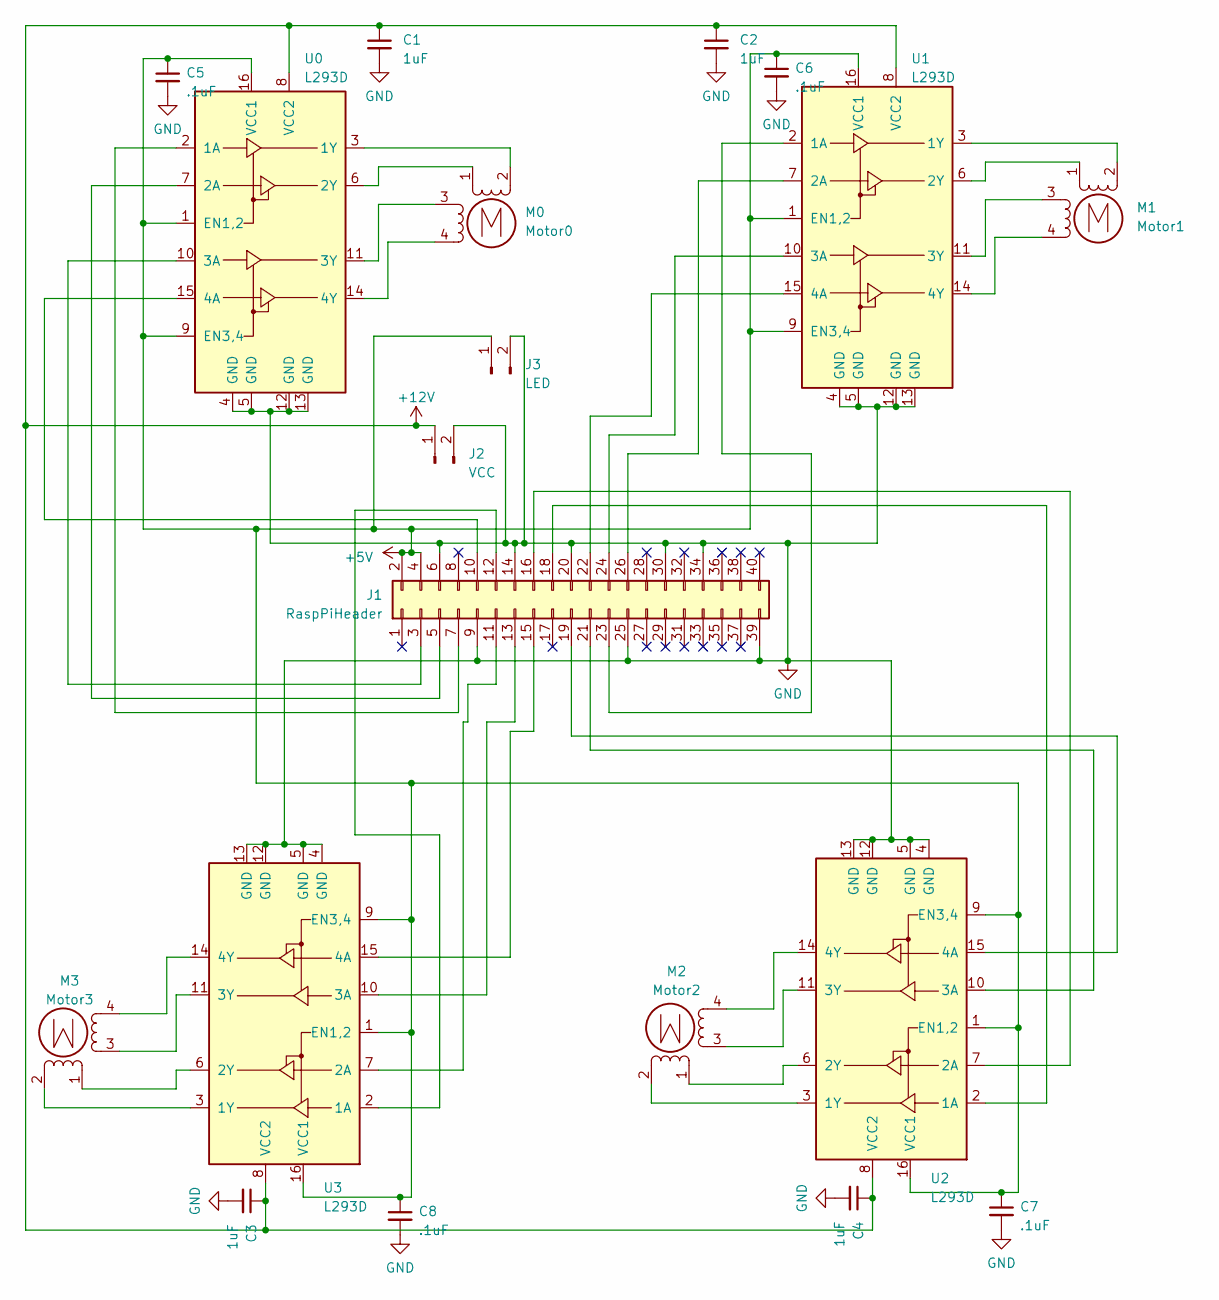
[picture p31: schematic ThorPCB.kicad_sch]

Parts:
C1, C2, C3, C4: 1uF; C_Disc_D6.0mm_W2.5mm_P5.00mm
C5, C6, C7, C8: .1uF; C_Disc_D5.0mm_W2.5mm_P5.00mm
J1: RaspPiHeader; PinHeader_2x20_P2.54mm_Vertical
J2: VCC; PinHeader_1x02_P2.54mm_Vertical
J3: LED; PinHeader_1x02_P2.54mm_Vertical
M0: Motor0; PinHeader_1x04_P2.54mm_Vertical
M1: Motor1; PinHeader_1x04_P2.54mm_Vertical
M2: Motor2; PinHeader_1x04_P2.54mm_Vertical
M3: Motor3; PinHeader_1x04_P2.54mm_Vertical
U0, U1, U2, U3: L293D; DIP-16_W7.62mm

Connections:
+5V: C5.1, C6.1, C7.1, C8.1, J1.2, J1.4, J3.1, U0.1 (EN1,2), U0.9 (EN3,4), U0.16 (VCC1), U1.1 (EN1,2), U1.9 (EN3,4), U1.16 (VCC1), U2.1 (EN1,2), U2.9 (EN3,4), U2.16 (VCC1), U3.1 (EN1,2), U3.9 (EN3,4), U3.16 (VCC1)
+12V: C1.1, C2.1, C3.1, C4.1, J2.1, U0.8 (VCC2), U1.8 (VCC2), U2.8 (VCC2), U3.8 (VCC2); also elsewhere on the board
GND: C1.2, C2.2, C3.2, C4.2, C5.2, C6.2, C7.2, C8.2, J1.6, J1.9, J1.14, J1.20, J1.25, J1.30, J1.34, J1.39, J2.2, J3.2, U0.4 (GND), U0.5 (GND), U0.12 (GND), U0.13 (GND), U1.4 (GND), U1.5 (GND), U1.12 (GND), U1.13 (GND), U2.4 (GND), U2.5 (GND), U2.12 (GND), U2.13 (GND), U3.4 (GND), U3.5 (GND), U3.12 (GND), U3.13 (GND); also elsewhere on the board
unnamed: J1.3, U0.10 (3A)
unnamed: J1.5, U0.7 (2A)
unnamed: J1.7, U0.2 (1A)
unnamed: J1.10, U0.15 (4A)
unnamed: J1.11, U3.7 (2A)
unnamed: J1.12, U3.2 (1A)
unnamed: J1.13, U3.10 (3A)
unnamed: J1.15, U3.15 (4A)
unnamed: J1.16, U2.7 (2A)
unnamed: J1.18, U2.2 (1A)
unnamed: J1.19, U2.15 (4A)
unnamed: J1.21, U2.10 (3A)
unnamed: J1.22, U1.15 (4A)
unnamed: J1.23, U1.2 (1A)
unnamed: J1.24, U1.10 (3A)
unnamed: J1.26, U1.7 (2A)
unnamed: M0.2 (-), U0.3 (1Y)
unnamed: M1.2 (-), U1.3 (1Y)
unnamed: M2.2 (-), U2.3 (1Y)
unnamed: M3.2 (-), U3.3 (1Y)
unnamed: M0.1, U0.6 (2Y)
unnamed: M0.3, U0.11 (3Y)
unnamed: M0.4, U0.14 (4Y)
unnamed: M1.1, U1.6 (2Y)
unnamed: M1.3, U1.11 (3Y)
unnamed: M1.4, U1.14 (4Y)
unnamed: M2.1, U2.6 (2Y)
unnamed: M2.3, U2.11 (3Y)
unnamed: M2.4, U2.14 (4Y)
unnamed: M3.1, U3.6 (2Y)
unnamed: M3.3, U3.11 (3Y)
unnamed: M3.4, U3.14 (4Y)

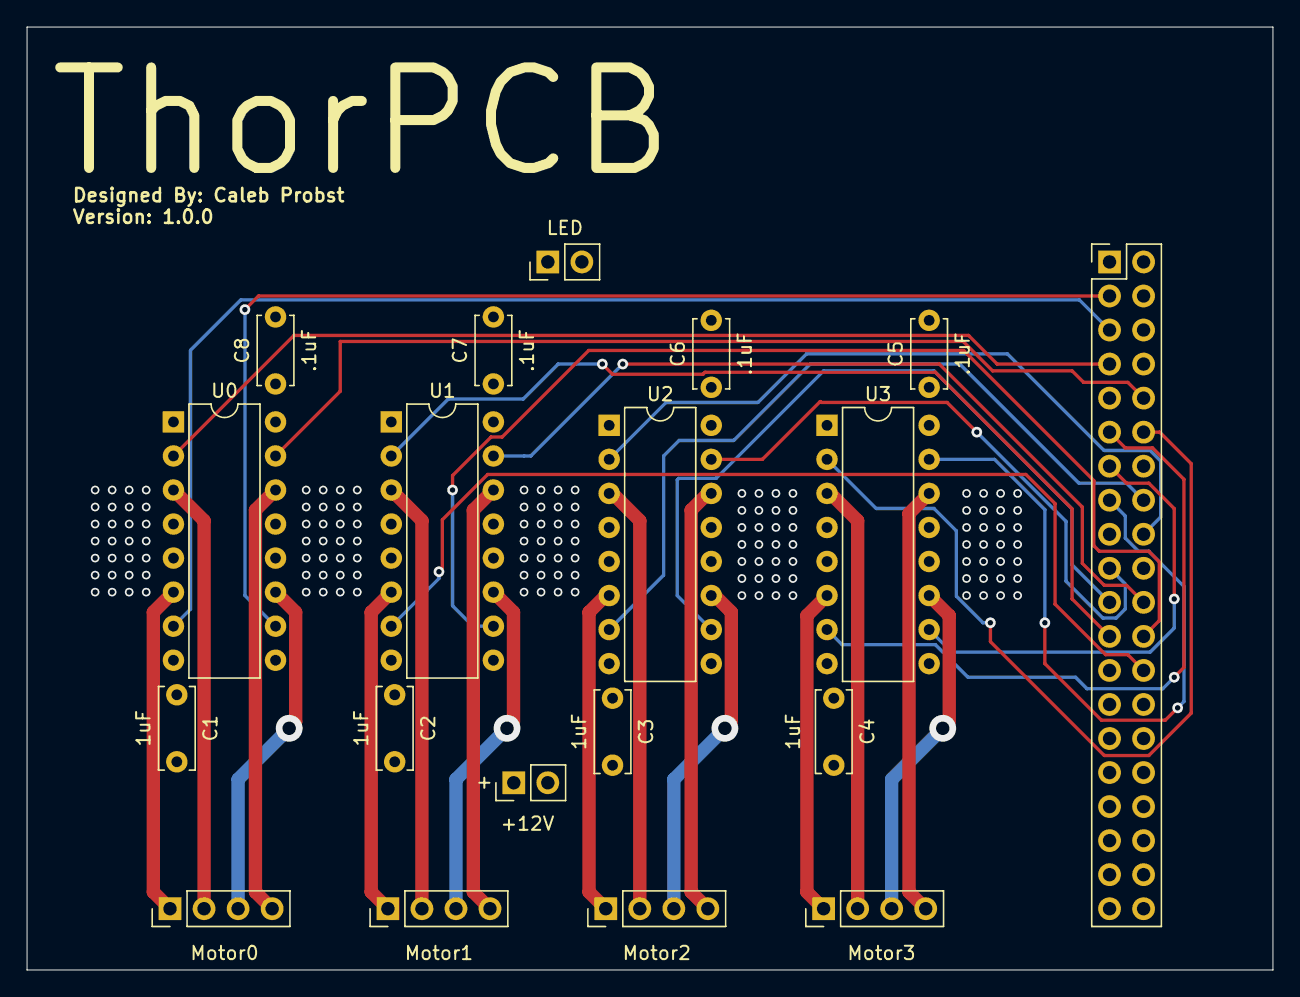
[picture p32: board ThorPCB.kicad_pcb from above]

Board: 4 copper layers, 93.0 x 70.4 mm, 19 parts (0 on the bottom side), 35 nets.

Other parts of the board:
+: +12V; PinHeader_1x02_P2.54mm_Vertical

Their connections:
+12V: +.1; also elsewhere on the board
GND: +.2; also elsewhere on the board

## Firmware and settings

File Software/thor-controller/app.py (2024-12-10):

from flask import Flask, Response, render_template, request, jsonify
from picamera2 import Picamera2
import cv2
import numpy as np
import threading
import serial
import math
import time

app = Flask(__name__)

# Initialize Picamera2 with high resolution for live feed
picam2 = Picamera2()
video_config = picam2.create_video_configuration(
    main={"size": (1920, 1080), "format": "RGB888"})
video_config['controls'] = {"FrameRate": 30}
picam2.configure(video_config)
picam2.start()

# Initialize UART connection
uart_port = '/dev/ttyAMA0'
baud_rate = 115200
try:
    ser = serial.Serial(uart_port, baud_rate, timeout=1)
except serial.SerialException as e:
    print(f"Error initializing UART: {e}")
    ser = None

# Global variables for shared resources
log_data = []
sensor_values = [0, 0, 0, 0]
data_lock = threading.Lock()  # Lock for thread-safe access to shared resources

# Minimum contour area for valid detection
MIN_CONTOUR_AREA = 20
kernel = np.ones((3, 3), np.uint8)
MASK_RESOLUTION = (320, 240)

# Default values for brightness adjustment and selected color
brightness_increase = 30
selected_color = "green"  # Default color to track

# Define HSV ranges for primary colors and default HSV values for sliders
color_ranges = {
    "red": ([0, 100, 100], [10, 255, 255]),
    "green": ([50, 100, 100], [70, 255, 255]),
    "blue": ([100, 100, 100], [130, 255, 255])
}
# Default slider values
lower_hue, upper_hue = color_ranges[selected_color][0][0], color_ranges[selected_color][1][0]

control_mode = "manual"  # Default control mode is manual
threshold = 10  # Threshold for dx and dy for automatic control


def generate_log_data():
    """Thread for continuous UART log reading."""
    global sensor_values  # Use the global variable
    while True:
        if ser and ser.in_waiting > 0:
            line = ser.readline().decode('utf-8').strip()
            with data_lock:  # Lock access to shared resources
                log_data.append(line)
                if len(log_data) > 20:
                    log_data.pop(0)

            # Parse the sensor values from "Load[0,0,0,0]" format
            if line.startswith("Load[") and line.endswith("]"):
                try:
                    values = line[5:-1].split(",")
                    with data_lock:  # Safely update sensor_values
                        sensor_values = [int(value) for value in values]
                    # print(f"Sensor values updated: {sensor_values}")  # Log parsed sensor values
                except ValueError:
                    print(f"Failed to parse sensor values: {line}")


# Start the log generation in a separate thread
log_thread = threading.Thread(target=generate_log_data)
log_thread.daemon = True
log_thread.start()


@app.route('/')
def index():
    return render_template('index.html')


# Function to generate live video feed with minimal processing and FPS tracking
def generate_video_feed():
    """Capture high-resolution frames for live feed and stream them directly."""
    video_start_time = time.time()
    video_frame_count = 0

    while True:
        frame = picam2.capture_array()
        video_frame_count += 1

        # Calculate FPS and SPF for video feed
        elapsed_time = time.time() - video_start_time
        fps = video_frame_count / elapsed_time if elapsed_time > 0 else 0
        spf = elapsed_time / video_frame_count if video_frame_count > 0 else 0

        # Display FPS and SPF in the top right corner
        cv2.putText(frame, f"FPS: {fps:.2f}", (1675, 45),
                    cv2.FONT_HERSHEY_SIMPLEX, 1.5, (255, 255, 255), 2)
        # cv2.putText(frame, f"SPF: {spf:.4f}s", (1500, 100), cv2.FONT_HERSHEY_SIMPLEX, 1.5, (255, 255, 255), 2)

        # Slightly reduce the JPEG quality to increase frame rate
        ret, buffer = cv2.imencode(
            '.jpg', frame, [cv2.IMWRITE_JPEG_QUALITY, 60])
        if ret:
            yield (b'--frame\r\n'
                   b'Content-Type: image/jpeg\r\n\r\n' + buffer.tobytes() + b'\r\n')


@app.route('/video_feed')
def video_feed():
    return Response(generate_video_feed(), mimetype='multipart/x-mixed-replace; boundary=frame')


# Function to generate mask feed with color detection, overlay, and FPS tracking
def generate_mask_feed():
    global control_mode, threshold
    mask_start_time = time.time()
    mask_frame_count = 0

    while True:
        frame = picam2.capture_array()
        small_frame = cv2.resize(frame, MASK_RESOLUTION)
        hsv_frame = cv2.cvtColor(small_frame, cv2.COLOR_RGB2HSV)
        hsv_frame[:, :, 2] = np.clip(
            hsv_frame[:, :, 2] + brightness_increase, 0, 255)

        lower_bound = np.array([lower_hue, 100, 100])
        upper_bound = np.array([upper_hue, 255, 255])

        mask = cv2.inRange(hsv_frame, lower_bound, upper_bound)
        mask = cv2.morphologyEx(mask, cv2.MORPH_OPEN, kernel, iterations=1)
        mask = cv2.morphologyEx(mask, cv2.MORPH_CLOSE, kernel, iterations=1)

        mask_colored = cv2.cvtColor(mask, cv2.COLOR_GRAY2BGR)

        contours, _ = cv2.findContours(
            mask, cv2.RETR_EXTERNAL, cv2.CHAIN_APPROX_SIMPLE)
        if contours:
            largest_contour = max(contours, key=cv2.contourArea)
            if cv2.contourArea(largest_contour) > MIN_CONTOUR_AREA:
                x, y, w, h = cv2.boundingRect(largest_contour)
                object_center = (x + w // 2, y + h // 2)

                screen_center = (
                    MASK_RESOLUTION[0] // 2, MASK_RESOLUTION[1] // 2)
                dx = object_center[0] - screen_center[0]
                dy = -(object_center[1] - screen_center[1])
                distance = int(math.sqrt(dx ** 2 + dy ** 2))

                cv2.rectangle(mask_colored, (x, y),
                              (x + w, y + h), (0, 255, 255), 2)
                cv2.line(mask_colored, screen_center,
                         object_center, (255, 0, 0), 2)

                cv2.putText(mask_colored, f"Distance: {distance}", (
                    10, 30), cv2.FONT_HERSHEY_SIMPLEX, 0.6, (255, 255, 255), 2)
                cv2.putText(
                    mask_colored, f"dx: {dx}", (10, 60), cv2.FONT_HERSHEY_SIMPLEX, 0.6, (255, 255, 255), 2)
                cv2.putText(
                    mask_colored, f"dy: {dy}", (10, 90), cv2.FONT_HERSHEY_SIMPLEX, 0.6, (255, 255, 255), 2)
                
                # Print the control mode
                # cv2.putText(mask_colored, f"Control Mode: {control_mode}", (10, 120),
                #             cv2.FONT_HERSHEY_SIMPLEX, 0.6, (255, 255, 255), 2)

                if control_mode == "auto":
                    x_command = -(1 if dx > threshold else -1 if dx < -threshold else 0)
                    y_command = 1 if dy > threshold else -1 if dy < -threshold else 0

                    if ser:
                        command = f"Move[{x_command},{y_command}]\n"
                        ser.write(command.encode('utf-8'))
                        print(f"Sent command: {command.strip()}")

        mask_frame_count += 1
        elapsed_time = time.time() - mask_start_time
        mask_fps = mask_frame_count / elapsed_time if elapsed_time > 0 else 0
        mask_spf = elapsed_time / mask_frame_count if mask_frame_count > 0 else 0

        cv2.putText(mask_colored, f"FPS: {mask_fps:.2f}", (220, 20),
                    cv2.FONT_HERSHEY_SIMPLEX, 0.6, (255, 255, 255), 2)
        # cv2.putText(mask_colored, f"SPF: {mask_spf:.4f}s", (200, 60), cv2.FONT_HERSHEY_SIMPLEX, 0.6, (255, 255, 255), 2)

        ret, buffer = cv2.imencode('.jpg', mask_colored, [
                                   cv2.IMWRITE_JPEG_QUALITY, 50])
        if ret:
            yield (b'--frame\r\n'
                   b'Content-Type: image/jpeg\r\n\r\n' + buffer.tobytes() + b'\r\n')


@app.route('/mask_feed')
def mask_feed():
    return Response(generate_mask_feed(), mimetype='multipart/x-mixed-replace; boundary=frame')


@app.route('/sensor_values')
def get_sensor_values():
    """Endpoint to retrieve the sensor values."""
    global sensor_values
    with data_lock:  # Lock access to shared resources
        # Properly return sensor values as JSON
        return jsonify(sensor_values=sensor_values)


@app.route('/update_range', methods=['POST'])
def update_range():
    global selected_color, lower_hue, upper_hue
    data = request.json
    if 'rgb' in data:
        rgb = data['rgb']
        # Convert RGB to HSV
        r, g, b = rgb
        hsv = cv2.cvtColor(np.uint8([[[r, g, b]]]), cv2.COLOR_RGB2HSV)[0][0]
        hue = hsv[0]
        lower_hue = max(0, hue - 15)
        upper_hue = min(180, hue + 15)
    if 'threshold' in data:
        threshold = int(data['threshold'])
        lower_hue = max(0, lower_hue - threshold)
        upper_hue = min(180, upper_hue + threshold)
    return jsonify(success=True)


@app.route('/move', methods=['POST'])
def move():
    global control_mode
    if control_mode != "manual":
        return jsonify(success=False, error="Cannot send manual commands in automatic mode.")

    data = request.json
    x = int(data.get('x', 0))
    y = int(data.get('y', 0))
    command = f"Move[{x},{y}]\n"

    if ser:
        ser.write(command.encode('utf-8'))
        print(f"Sent command: {command.strip()}")
        return jsonify(success=True, action=command.strip())
    else:
        print(
            f"UART not initialized. Failed to send command: {command.strip()}")
        return jsonify(success=False, error="UART not initialized.")


@app.route('/update_control_mode', methods=['POST'])
def update_control_mode():
    global control_mode
    data = request.json  # Parse JSON data from request
    control_mode = data.get('control_mode', 'manual')  # Default to "manual" if not provided
    print(f"Updated control_mode to: {control_mode}")  # Debugging
    return jsonify(success=True, control_mode=control_mode)


if __name__ == '__main__':
    print("Starting Flask server on port 5000")
    app.run(host='0.0.0.0', port=5000)

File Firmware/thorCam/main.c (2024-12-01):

#include "pico/stdlib.h"
#include "include/l293d.h"
#include <stdio.h>
#include "include/ads1115.h"
#include "hardware/i2c.h"
#include "pico/multicore.h"
#include "include/movement.h"
#include "include/sensor.h"
#include "include/uart_rx.h"

#define I2C_PORT i2c0
#define I2C_SCL 5
#define I2C_SDA 4

#define false 0
#define true 1

void setup(){
    stdio_init_all();

    setup_steppers();

    i2c_init(i2c_default, 400 * 1000); // 400kHz I2C
    gpio_set_function(I2C_SDA, GPIO_FUNC_I2C);
    gpio_set_function(I2C_SCL, GPIO_FUNC_I2C);
    gpio_pull_up(I2C_SDA);
    gpio_pull_up(I2C_SCL);

    ads1115_init(&adc1, I2C_PORT, 0x48);
    ads1115_init(&adc2, I2C_PORT, 0x49);

    uart_init(UART_ID, BAUD_RATE);
    gpio_set_function(UART_TX_PIN, GPIO_FUNC_UART);
    gpio_set_function(UART_RX_PIN, GPIO_FUNC_UART);
    uart_set_irq_enables(UART_ID, true, false);
}

void core1_task(){
    while(true){
        read_ads111_task();
        
        sleep_ms(10);
    }
}


int main()
{
    setup();

    calibrate();

    multicore_launch_core1(core1_task);

    while (true)
    {
        uart_rx_task();

        // for(int i=0; i<1000; i++){
        //     move(1, 1000, 0, 1);
        //     sleep_ms(10);
        // }

        // for(int i=0; i<1000; i++){
        //     move(1, 1000, 0, -1);
        //     sleep_ms(10);
        // }
    }

    return 0;
}

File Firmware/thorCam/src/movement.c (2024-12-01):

#include "movement.h"

l293d_t stepper0, stepper1, stepper2, stepper3;
int8_t vector[] = {1, 1, 1, 1};
l293d_controller_t controller;

void setup_steppers()
{
    // Initialize the steppers
    l293d_init(&stepper0, STEPPER0_PIN1, STEPPER0_PIN2, STEPPER0_PIN3, STEPPER0_PIN4);
    l293d_init(&stepper1, STEPPER1_PIN1, STEPPER1_PIN2, STEPPER1_PIN3, STEPPER1_PIN4);
    l293d_init(&stepper2, STEPPER2_PIN1, STEPPER2_PIN2, STEPPER2_PIN3, STEPPER2_PIN4);
    l293d_init(&stepper3, STEPPER3_PIN1, STEPPER3_PIN2, STEPPER3_PIN3, STEPPER3_PIN4);

    l293d_t steppers[] = {stepper0, stepper1, stepper2, stepper3};
    l293d_controller_init(&controller, steppers, NUM_STEPPERS);
}

/*
    Move 0, -Y
    Forward: 0
    Backward: 2
*/
void move_0(int num_steps, int delay_us)
{

    // Move stepper 2 to lower limit
    while (sensor_values[2] > TENSION_LOWER_LIMIT)
    {
        if(sensor_values[2] < TENSION_LOWER_LIMIT){
            break;
        }

        l293d_step_backward(&stepper2, REVERSE_DELAY, 1);
        sleep_ms(1);
    }

    l293d_stop(&stepper2);

    // Move stepper 0
    if (sensor_values[0] < TENSION_UPPER_LIMIT)
    {
        // Move stepper 0
        l293d_step_forward(&stepper0, delay_us, num_steps);
        sleep_ms(1);
    }
    else
    {
        // printf("Move 0: Stalled\n");
    }
}

/*
    Move -X, 0
    Forward: 0 & 1
    Backward: 2 & 3
*/
void move_1(int num_steps, int delay_us)
{
    // Move steppers 2 and 3 to lower limit
    while (sensor_values[2] > TENSION_LOWER_LIMIT || sensor_values[3] > TENSION_LOWER_LIMIT)
    {
        if(sensor_values[2] < TENSION_LOWER_LIMIT && sensor_values[3] < TENSION_LOWER_LIMIT){
            break;
        }

        if (sensor_values[2] > TENSION_LOWER_LIMIT)
        {
            l293d_step_backward(&stepper2, REVERSE_DELAY, 1);
            sleep_ms(1);
        }

        if (sensor_values[3] > TENSION_LOWER_LIMIT)
        {
            l293d_step_backward(&stepper3, REVERSE_DELAY, 1);
            sleep_ms(1);
        }
    }

    l293d_stop(&stepper2);
    l293d_stop(&stepper3);

    // Move steppers 0 and 1
    if (sensor_values[0] < TENSION_UPPER_LIMIT && sensor_values[1] < TENSION_UPPER_LIMIT)
    {
        // Move both steppers
        // printf("Move 1\n");
        l293d_step_forward(&stepper0, delay_us, num_steps);
        l293d_step_forward(&stepper1, delay_us, num_steps);
        sleep_ms(1);
    }
    else if (sensor_values[0] < TENSION_UPPER_LIMIT)
    {
        // Move stepper 0
        // printf("Move 1: Stepper 1 stalled\n");
        l293d_step_forward(&stepper0, delay_us, num_steps);
        sleep_ms(1);
    }
    else if (sensor_values[1] < TENSION_UPPER_LIMIT)
    {
        // Move stepper 1
        // printf("Move 1: Stepper 0 stalled\n");
        l293d_step_forward(&stepper1, delay_us, num_steps);
        sleep_ms(1);
    }
    else
    {
        // printf("Move 1: Stalled\n");
    }
}

/*
    Move -X, +Y
    Forward: 1
    Backward: 3
*/
void move_2(int num_steps, int delay_us)
{
    // Move stepper 3 to lower limit
    while (sensor_values[3] > TENSION_LOWER_LIMIT)
    {
        if(sensor_values[3] < TENSION_LOWER_LIMIT){
            break;
        }

        l293d_step_backward(&stepper3, REVERSE_DELAY, 1);
        sleep_ms(1);
    }

    l293d_stop(&stepper3);

    // Move stepper 1
    if (sensor_values[1] < TENSION_UPPER_LIMIT)
    {
        // Move stepper 1
        l293d_step_forward(&stepper1, delay_us, num_steps);
        sleep_ms(1);
    }
    else
    {
        // printf("Move 2: Stalled\n");
    }
}

/*
    Move 0, -Y
    Forward: 0 & 3
    Backward: 1 & 2
*/
void move_3(int num_steps, int delay_us)
{
    // Move steppers 1 and 2 to lower limit
    while (sensor_values[1] > TENSION_LOWER_LIMIT || sensor_values[2] > TENSION_LOWER_LIMIT)
    {
        if(sensor_values[1] < TENSION_LOWER_LIMIT && sensor_values[2] < TENSION_LOWER_LIMIT){
            break;
        }

        if (sensor_values[1] > TENSION_LOWER_LIMIT)
        {
            l293d_step_backward(&stepper1, REVERSE_DELAY, 1);
            sleep_ms(1);
        }

        if (sensor_values[2] > TENSION_LOWER_LIMIT)
        {
            l293d_step_backward(&stepper2, REVERSE_DELAY, 1);
            sleep_ms(1);
        }
    }

    l293d_stop(&stepper1);
    l293d_stop(&stepper2);

    // Move steppers 0 and 3
    if (sensor_values[0] < TENSION_UPPER_LIMIT && sensor_values[3] < TENSION_UPPER_LIMIT)
    {
        // Move both steppers
        // printf("Move 3\n");
        l293d_step_forward(&stepper0, delay_us, num_steps);
        l293d_step_forward(&stepper3, delay_us, num_steps);
        sleep_ms(1);
    }
    else if (sensor_values[0] < TENSION_UPPER_LIMIT)
    {
        // Move stepper 0
        // printf("Move 3: Stepper 3 stalled\n");
        l293d_step_forward(&stepper0, delay_us, num_steps);
        sleep_ms(1);
    }
    else if (sensor_values[3] < TENSION_UPPER_LIMIT)
    {
        // Move stepper 3
        // printf("Move 3: Stepper 0 stalled\n");
        l293d_step_forward(&stepper3, delay_us, num_steps);
        sleep_ms(1);
    }
    else
    {
        // printf("Move 3: Stalled\n");
    }
}

/*
    Move 0, 0
    Do nothing
*/
void move_4(int num_steps, int delay_us)
{
    // Do nothing
}
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

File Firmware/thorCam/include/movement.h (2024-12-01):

#ifndef MOVEMENT_H
#define MOVEMENT_H

#include "sensor.h"
#include <stdio.h>
#include "pico/stdlib.h"
#include "l293d.h"

#define STEPPER0_PIN1 10
#define STEPPER0_PIN2 12
#define STEPPER0_PIN3 11
#define STEPPER0_PIN4 13

#define STEPPER1_PIN1 14
#define STEPPER1_PIN2 16
#define STEPPER1_PIN3 15
#define STEPPER1_PIN4 17

#define STEPPER2_PIN1 18
#define STEPPER2_PIN2 20
#define STEPPER2_PIN3 19
#define STEPPER2_PIN4 21

#define STEPPER3_PIN1 22
#define STEPPER3_PIN2 27
#define STEPPER3_PIN3 26
#define STEPPER3_PIN4 28

#define NUM_STEPPERS 4

#define TENSION_HARD_UPPER_LIMIT 300
#define TENSION_UPPER_LIMIT 250
#define TENSION_OPTIMAL 100
#define TENSION_LOWER_LIMIT 10

#define REVERSE_DELAY 1000
#define FORWARD_DELAY 1000

extern l293d_t stepper0, stepper1, stepper2, stepper3;
extern l293d_controller_t controller;
extern int8_t vector[];

// Function prototypes
void calibrate();
void setup_steppers();
void move(int num_steps, int delay_us, int x, int y);

// Movement sub-functions
void move_0(int num_steps, int delay_us);
void move_1(int num_steps, int delay_us);
void move_2(int num_steps, int delay_us);
void move_3(int num_steps, int delay_us);
void move_4(int num_steps, int delay_us);
void move_5(int num_steps, int delay_us);
void move_6(int num_steps, int delay_us);
void move_7(int num_steps, int delay_us);
void move_8(int num_steps, int delay_us);

#endif // MOVEMENT_H

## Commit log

2024-09-17 Add legacy project files
    [CamBracket.stl, NewStringBracket.stl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]
2024-09-17 Intial PCB and File Structure Push
    [Loadcells_Schematic.kicad_sch, StepperDriver.kicad_sch, ThorPBC2.0.kicad_pcb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]
2024-09-17 Added Stuff for pico
2024-09-18 Add current firmware to repo. Included FreeRTOS Kernel repo in project.
2024-09-24 Move some files and rename some stuff. Add the 3D model files.
    [CamBracket.stl, Camera_Adapter_v3.f3d, Case_Passthrough_v4.f3d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]
2024-09-24 Add images and datasheet
    [Camera_Adapter_v3.f3d, Case_Passthrough_v4.f3d, Tension_Module_v3-v7.f3d]
2024-09-24 Add shift register driver.
2024-09-30 Updates to PCB
    [Loadcells_Schematic.kicad_sch, StepperDriver.kicad_sch, ThorPBC2.0.kicad_sch]
2024-09-30 Updates to Sch
    [Loadcells_Schematic.kicad_sch, StepperDriver.kicad_sch, ThorPBC2.0.kicad_sch]
2024-10-07 Working firmware, calibration, and balancing. Not currently utilizing the FreeRTOS Kernel.
2024-10-07 Add baseline web application. Successful camera feed and UART connection.
2024-10-08 PCB Updates
    [Loadcells_Schematic.kicad_sch, StepperDriver.kicad_sch, ThorPBC2.0.kicad_pcb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]
2024-10-08 Push latest software for thor controller. Has working object tracking, live video feed, analysis mask feed, uart feed, and hue controls.
2024-10-24 Updated UI for software controller. Added bar graph for live sensor values.
2024-10-24 PCB "Done"
    [1-1775099-3.stp, 16Bit I2C ADC+PGA - ADS1115.stp, C320C104K5R5TA.step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]
2024-10-24 ATX24 was not right
    [ThorPBC2.0.kicad_pcb]
2024-10-29 Added Back Silkscreen image
    [ThorPBC2.0.kicad_pcb]
2024-10-30 Final Updates
    [ThorPBC2.0.kicad_pcb]
2024-10-30 Got rid of old files
    [ThorPBC2.0-BOTTOM_Cu.gbr, ThorPBC2.0-B_Mask.gbr, ThorPBC2.0-B_Paste.gbr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]
2024-10-30 Power and GND plane fixed
    [ThorPBC2.0.kicad_pcb]
2024-11-01 Production PCB Version
    [ThorPBC2.0.kicad_pcb]
2024-11-26 Update UI for live bar chart sensor values, target color sliders.
2024-11-26 Add direction movement for camera. Adjust threshold values.
2024-11-29 Pico can get commands via uart. Break out the sensor and movement functions from main.c into helper files.
2024-12-01 Calibrated movement controls from thor-controller via UART.
2024-12-02 Change UI for dark mode. Swap X sign for correct object tracking direction.
    [app.py]
2024-12-12 Added to the Bill of Materials
2024-12-12 Update BOM totals
